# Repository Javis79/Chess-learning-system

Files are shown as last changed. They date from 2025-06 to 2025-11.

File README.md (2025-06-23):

# System Nauki Gry w Szachy

## Opis Projektu

System nauki gry w szachy jest dedykowany dla początkujących szachistów, którzy chcą poprawić swoje umiejętności i poznać zasady gry. Projekt oparty jest na mikrokontrolerze STM32, który zarządza interakcją z użytkownikiem oraz prezentuje ruchy na szachownicy.

Projekt ma na celu pomoc w nauce poprzez wizualne wskazywanie odpowiednich pól szachownicy oraz wyświetlanie notacji ruchów na wyświetlaczu 2.8 cala z interfejsem SPI. System wykorzystuje matrycę LED do podświetlania odpowiednich pól oraz umożliwia łatwe śledzenie postępów w grze.

## Zawartość Projektu

1. **Szachownica LED**: Matryca LED podświetlająca odpowiednie pola na planszy szachowej.
2. **Notacja Ruchów**: Wyświetlanie ruchów w odpowiedniej notacji na wyświetlaczu 2.8 cala z SPI.
3. **Mikrokontroler STM32**: Centralny układ sterujący systemem, odpowiedzialny za obsługę wyświetlacza i matrycy LED.
4. **Potencjalny Rozwój**:

   * **Wykrywanie Poprawności Ruchów**: Każde pole szachownicy będzie traktowane jako przycisk, a system będzie rozpoznawał odkliknięcie klawisza w celu sprawdzenia poprawności ruchu.
   * **Zegar Szachowy**: Wyświetlanie zegara szachowego na wyświetlaczu 2.8 cala, umożliwiającego śledzenie czasu każdej ze stron.

## Wymagania Systemowe

* **Mikrokontroler**: STM32F401RE ARM Cortex M4
* **Matryca LED**: 8x8 
* **Wyświetlacz**: 2.8 cala SPI
* **Zasilanie**: 5V 
* **Oprogramowanie**: STM32CubeIDE

## Wykorzystane Technologie

* **Mikrokontroler STM32**: Platforma sprzętowa do realizacji projektu.
* **SPI**: Interfejs do komunikacji z wyświetlaczem.
* **Matryca LED**: Wyświetlanie pól szachowych i interakcja z użytkownikiem.
* **C**: Język programowania do realizacji logiki sterującej mikrokontrolerem.

## Autor

Praca inżynierska jest tworzona przez Krystiana Bajerskiego, studenta elektroniki na AGH pod przewodnictwem dr inż. Agnieszki Dąbrowskiej-Boruch.

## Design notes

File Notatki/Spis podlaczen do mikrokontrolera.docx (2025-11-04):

# Spis podłączeń do mikrokontrolera

PIN | Podłączony element/IN/OUT elementu
PC0 | 1 rząd mux wyjście
PC1 | 2 rząd mux wyjście
PC2 | 3 rząd mux wyjście
PC3 | 4 rząd mux wyjście
PB7 | 5 rząd mux wyjście
PA13 | 6 rząd mux wyjście
PA14 | 7 rząd mux wyjście
PA15 | 8 rząd mux wyjście
PC10 | Wspólny S0 dla muxów
PC11 | Wspólny S1 dla muxów
PC12 | Wspólny S2 dla muxów
PB0 | Przycisk 1
PA4 | Przycisk 2
PA1 | Przycisk 3
PA0 | Przycisk 4

PINY WYŚWIETLACZA
3V3 | VCC, LED
GND | GND
PA5 | SCK
PA6 | MISO
PA7 | MOSI
PB6 | CS
PC7 | RESET
PA9 | DC
PA8 | Sterowanie matrycą LED
PA10 | CS karty SD

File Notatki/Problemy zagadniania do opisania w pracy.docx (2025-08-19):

# Napotkane problemy/zagadnienia do opisania w pracy

Dobór sposobu podświetlania pól, opisać opcje (dlaczego adresowalna taśma led)

Wybór centralnej jednostki (mikrokontroler, dlaczego stm, a nie esp, zalety wady)

Sposób zapisu posunięć szachowych, ustalenie w jaki sposób program przekształca sobie notacje na odpowiednie pola.

Sposób kontroli ledów, stworzenie programów do kontroli, przygotowanie systemu.

Zapis bazy otwarć szachowych (baza danych? Połączenie zdalne, format txt, json w pliku na karcie sd)

Przedstawienie posunięć na wyświetlaczu, dobór wyświetlacza, przetwarzanie bitmap, organizacja prezentowanych elementów na ekranie, optymalizacja pamięci, by bufor nie zapychał pamięci mikroprocesora.

Stworzenie układu, podłączenie elementów, schematy ideowe, blokowe, wizualizacje 3D szachownicy.

Dobór odpowiedniego zasilacza do wybranej ilości diod led.

Opisanie doboru ustawień mikrokontrolera, odpowiednia częstotliwość zegara, sposób dzialania z dokumentacji, kontrola przy pomocy odpowiednio długich sygnałów.

Podłączenie ledów z mikrokontrolerem, wspólna masa, osobne zasilanie mikrokontrolera i taśmy led. Dobór odpowiedniego przekroju przewodu do zasilania, wytrzymującego przepuszczany prąd.

Lutowanie matrycy led, druk 3d szachownicy.

Technologie zastane, informacje o produktach komercyjnych obecnych na rynku, rozwiązania opisane przy pomocy prac naukowych, potencjalne rozwiązania, którymi można się zainspirować, wady oraz zalety danych rozwiązań, kwestia ceny, zapotrzebowania technologicznego.

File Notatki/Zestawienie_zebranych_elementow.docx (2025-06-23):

# Spis elementów zebranych:

2,8 cala SPI TFT LCD ILI9341 (https://pl.aliexpress.com/item/1005006315533240.html)

WS2812B Taśma LED (https://pl.aliexpress.com/item/1005005824150092.html)

Karta pamięci 32GB (https://pl.aliexpress.com/item/1005006454965988.html)

STM32 NUCLEO-F401RE - STM32F401RE ARM Cortex M4 (https://botland.com.pl/stm32-nucleo/2217-stm32-nucleo-f401re-stm32f401re-arm-cortex-m4-5904422330613.html)

Zestaw rezystorów i kondensatorów

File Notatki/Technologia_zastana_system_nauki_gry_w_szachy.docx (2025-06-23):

Rozdział: Analiza technologii zastanej w projektach elektronicznych szachownic edukacyjnych

W związku z dynamicznym rozwojem technologii informacyjnych oraz rosnącym znaczeniem gier planszowych jako narzędzia edukacyjnego, w ostatnich latach powstało wiele projektów integrujących klasyczne rozgrywki szachowe z nowoczesnymi układami elektronicznymi. W niniejszym rozdziale przedstawiono przegląd wybranych realizacji, wskazując na wykorzystane technologie, cele projektowe oraz potencjalne ograniczenia.

Nasrul Humaïmi Mahmood oraz Che Ku Mohd Salahuddin Che Ku Long w pracy Smart Electronic Chess Board Using Reed Switch [1] przedstawili koncepcję elektronicznej szachownicy wykorzystującej czujniki kontaktronowe (reed switch). W zaproponowanym układzie pod każdą kratką planszy umieszczono czujnik reagujący na magnes w podstawie figury szachowej. W momencie przybliżenia figury do planszy, styk kontaktronu zamykał się, generując sygnał logiczny. Ze względu na dużą liczbę wymaganych wejść zastosowano multipleksery 8:1 typu 74LS251, co ograniczyło ilość linii sygnałowych do mikrokontrolera PIC18F452. Układ komunikował się z komputerem przez konwerter MAX232 i interfejs RS-232, a oprogramowanie w Visual Basic umożliwiało wizualizację rozmieszczenia figur, prowadzenie zapisu partii i obsługę zegara. Choć system nie rozpoznawał typu figur, jego prostota i niskie koszty czyniły go użytecznym narzędziem edukacyjnym oraz turniejowym.

Kolejnym rozwinięciem tej idei był projekt zaprezentowany przez Siti Zarinę Mohd Muji, Mohda Helmy’ego Abdula Wahaba, Radziego Ambara oraz Wong Kiana Loo w publikacji Design and Implementation of Electronic Chess Set [2]. Zamiast czujników magnetycznych zastosowano tu rozwiązanie optyczne — każda figura posiadała nadajnik IR, natomiast pod każdym polem planszy umieszczono fotodiodę. Mikrokontroler Arduino Mega 2560 zarządzał całością systemu, a możliwe ruchy były sygnalizowane poprzez podświetlenie odpowiednich pól diodami LED. Dzięki zastosowaniu enkoderów 64:6, multiplekserów 64:1 oraz rejestrów przesuwających rozwiązano problem ograniczonej liczby wejść/wyjść. System analizował także możliwe ruchy figur, uwzględniając zasady takie jak bicie na skos czy ruchy początkowe pionków. Pomimo ograniczeń w dokładności rozpoznawania typu figur (około 80,95%), rozwiązanie wyróżniało się dużą precyzją w detekcji pozycji i ogromnym potencjałem edukacyjnym.

Równolegle, w obszarze wykorzystania sztucznej inteligencji, badacze ze Sri Lanka Institute of Information Technology: Anuhas Divulage, Ruchika Bandara, Thamara Liyanage, Malith Ishara, Aruna Ishara Gamage i Thusithanjana Thilakarathna opracowali system Chess ADC – An Automated Aide-De-Camp [3]. Projekt ten łączył techniki głębokiego uczenia z tradycyjną grą na fizycznej szachownicy. System wykorzystywał kamery oraz algorytmy oparte na sieciach neuronowych (CNN, ConvLSTM) do wykrywania pozycji figur, kontroli poprawności ruchów i predykcji kolejnych posunięć przeciwnika. Gracze mogli korzystać z podpowiedzi generowanych przez silnik Stockfish, a wszystkie partie były zapisywane w bazie danych w formacie PGN. Analiza zmian prawdopodobieństwa wygranej po każdym ruchu oraz wysokie wyniki trafności predykcji (np. 70,71% dla pionków) czyniły Chess ADC zaawansowanym narzędziem wspierającym rozwój strategicznych umiejętności szachistów.

Studentów Uniwersytetu Centralnej Florydy (UCF) — Aleca Barno, Alejandra Felixa, Cassidy’ego Phillipsa, Viniciusa Resende oraz Nikolaia Colettę — zainteresowała natomiast kwestia intuicyjnego wsparcia nauki dla początkujących graczy. W projekcie Optical Interactive Chess Board for Beginners [4] zaprojektowali szachownicę, w której do identyfikacji figur użyto światłowodów oraz fotodiod. Odbite od podstaw figur światło, modyfikowane przez specjalne filtry, pozwalało określić typ figury stojącej na danym polu. Pod planszą umieszczono diody LED informujące o możliwych ruchach i błędach, a wyświetlacz LCD przekazywał dodatkowe instrukcje. System posiadał rozbudowaną obsługę sytuacji nieregularnych — takich jak nieprawidłowe ruchy, roszada, en passant czy promocja piona — oraz zakładał przyszłą rozbudowę o przeciwnika AI i funkcje dźwiękowe. Projekt wyróżniał się zaawansowaniem technicznym przy zachowaniu prostoty użytkowania.

Odmiennym podejściem do zagadnienia była praca Filipa Sušaca, Ivana Aleksiego oraz Željko Hocenskiego, którzy zaprezentowali rozwiązanie Digital Chess Board based on Array of Hall-Effect Sensors [5]. W ich systemie do wykrywania obecności figur zastosowano 64 czujniki efektu Halla (A3144) rozmieszczone pod polami planszy, a każda figura została wyposażona w magnes trwały. Odczyt danych realizowano poprzez multipleksowanie wierszy i przesyłanie wyników do komputera za pomocą komunikacji UART. Analiza zmian w macierzy stanów planszy umożliwiała wykrywanie ruchów, w tym podnoszenia, przesunięć oraz bić. Oprogramowanie PC oferowało graficzną wizualizację pozycji oraz zapis partii w standardowej notacji. Skuteczność wykrywania ruchów sięgała 96% dla zwykłych przesunięć oraz 86% dla bicia figur. Mimo konieczności ręcznej inicjalizacji pozycji początkowej i ograniczeń w automatycznym rozpoznawaniu typów figur, system stanowił niedrogą i edukacyjną alternatywę dla komercyjnych rozwiązań.

Nowym podejściem do integracji tradycyjnej szachownicy z systemami cyfrowymi zajęli się Guljan Atayeva, Perman Hojaqulyyev, Ayjemal Ussayeva, Yslam Orazov oraz Annageldi Orazov w pracy Cyber Physical System for Physical Chessboard Game on Computer Screen in a Real Time [6]. Autorzy zaprezentowali projekt interaktywnej szachownicy edukacyjnej, która w czasie rzeczywistym odwzorowuje fizyczną grę na ekranie komputera. Kluczowym elementem systemu były czujniki kontaktronowe (reed switch) umieszczone pod każdym polem planszy, reagujące na magnesy zamontowane w podstawach figur. Sygnały z czujników przetwarzane były przez układ Arduino Uno oraz przesyłane do oprogramowania komputerowego napisanego w Pythonie, gdzie z wykorzystaniem biblioteki Tkinter tworzono wizualizację aktualnego stanu gry. System umożliwiał nie tylko śledzenie ruchów na bieżąco, ale także rejestrowanie historii rozgrywki w plikach .xls, co pozwalało na późniejszą analizę partii. Wśród proponowanych ulepszeń autorzy wskazali m.in. możliwość rozwoju sterowania głosowego, integracji z aplikacją mobilną oraz zastosowania identyfikacji figur za pomocą chipów RFID. Projekt stanowił wartościowy krok w kierunku połączenia klasycznej gry planszowej z nowoczesnymi technologiami, oferując atrakcyjne narzędzie dydaktyczne dla graczy w każdym wieku.

Jednym z najbardziej rozpoznawalnych produktów jest DGT e-Board, wykorzystywana w oficjalnych turniejach szachowych FIDE [7]. Plansza ta wykorzystuje technologię pasywnych obwodów LC umieszczonych w podstawie każdej figury oraz aktywnych cewek w polach planszy. Dzięki pomiarowi częstotliwości rezonansowej system jest w stanie nie tylko wykrywać obecność figur, ale również rozpoznawać ich typ. DGT e-Board umożliwia bezpośrednie przesyłanie aktualnego układu planszy do komputerów i transmisję partii online. Rozwiązanie to cechuje się wysoką precyzją i niezawodnością, choć jego koszt oraz potrzeba integracji ze specjalistycznym oprogramowaniem mogą być barierą dla użytkowników domowych.

Innym ciekawym rozwiązaniem jest Square Off, które wprowadziło innowacyjną funkcję automatycznego przesuwania figur [8]. System wykorzystuje ukryty mechanizm XY, który przesuwa figury za pomocą wbudowanych magnesów, tworząc wrażenie „samodzielnie grającej” szachownicy. Użytkownicy mogą rywalizować zarówno z wirtualnymi przeciwnikami AI, jak i z graczami online. Choć rozwiązanie to imponuje efektem wizualnym, jest ono mniej skoncentrowane na edukacyjnych aspektach nauki zasad gry.

W segmencie bardziej przystępnym cenowo wyróżnia się Chessnut Air [9], który łączy fizyczną szachownicę z cyfrowym interfejsem. System oparty na matrycy czujników wykrywa obecność figur na planszy i synchronizuje je z aplikacjami szachowymi (takimi jak Chess.com czy Lichess). Chessnut Air umożliwia grę z AI oraz rozgrywki online, oferując intuicyjny sposób nauki i analizy rozgrywek. Urządzenie wymaga połączenia zewnętrznego (telefonu, tabletu lub komputera), co zwiększa jego elastyczność.

[1] N. H. Mahmood and C. K. M. S. C. K. Long, "Smart Electronic Chess Board Using Reed Switch," Jurnal Teknologi, vol. 55, no. Sains & Kej., May 2011.

[2] S. Z. M. Muji, M. H. A. Wahab, R. Ambar, and W. K. Loo, "Design and Implementation of Electronic Chess Set," in Proc. 2016 Int. Conf. Advances in Electrical, Electronic and System Engineering (ICAEES), Putrajaya, Malaysia, 2016.

[3] A. Divulage, R. Bandara, T. Liyanage, M. Ishara, A. I. Gamage, and T. Thilakarathna, "Chess ADC – An Automated Aide-De-Camp," in Proc. 20th Int. Conf. Advances in ICT for Emerging Regions (ICTer), Colombo, Sri Lanka, 2020.

[4] A. Barno, A. Felix, C. Phillips, V. Resende, and N. Coletta, "Optical Interactive Chess Board for Beginners," Senior Design Project, University of Central Florida, 2023.

[5] F. Sušac, I. Aleksi, and Ž. Hocenski, "Digital Chess Board based on Array of Hall-Effect Sensors," in Proc. 2017 Int. Conv. Information and Communication Technology, Electronics and Microelectronics (MIPRO), Opatija, Croatia, 2017.

[6] G. Atayeva, P. Hojaqulyyev, A. Ussayeva, Y. Orazov and A. Orazov, "Cyber Physical System for Physical Chessboard Game on Computer Screen in a Real Time," in Proc. 2024 3rd International Conference on Computational Modelling, Simulation and Optimization (ICCMSO), Ashgabat, Turkmenistan, 2024.

[7] Digital Game Technology (DGT), „DGT Electronic Chess Board – przegląd produktu”, [Online]. https://www.digitalgametechnology.com. [Dostęp: 28-kwi-2025].

[8] Square Off, „Square Off – pierwsza na świecie automatyczna szachownica”, [Online]. https://squareoffnow.com. [Dostęp: 28-kwi-2025].

[9] Chessnut, „Chessnut Air – inteligentna elektroniczna szachownica”, [Online]. https://chessnutech.com. [Dostęp: 28-kwi-2025].

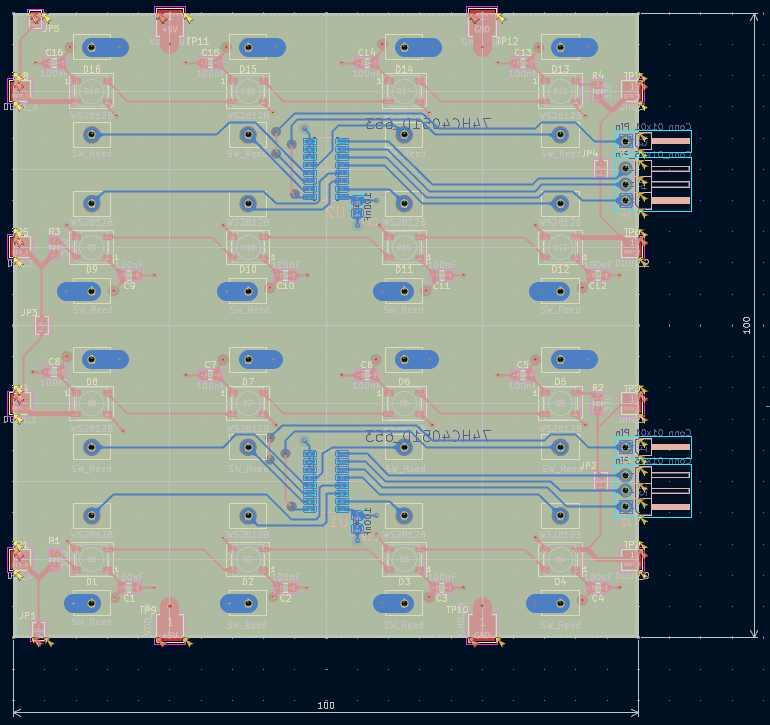
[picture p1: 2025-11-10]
PCB_inzynierka/screens/Screenshot from 2025-11-08 16-29-04.png

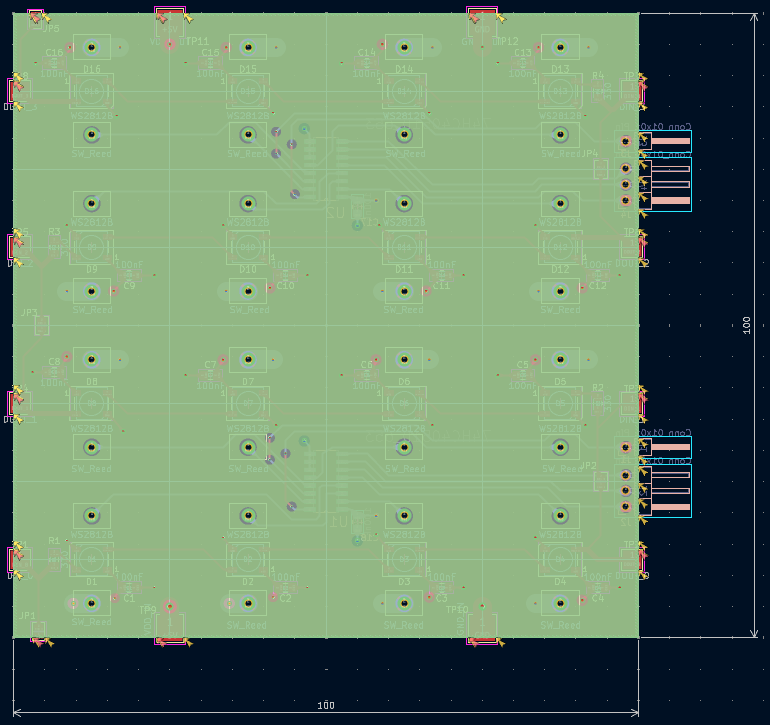
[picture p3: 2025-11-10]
PCB_inzynierka/screens/Screenshot from 2025-11-08 16-28-57.png

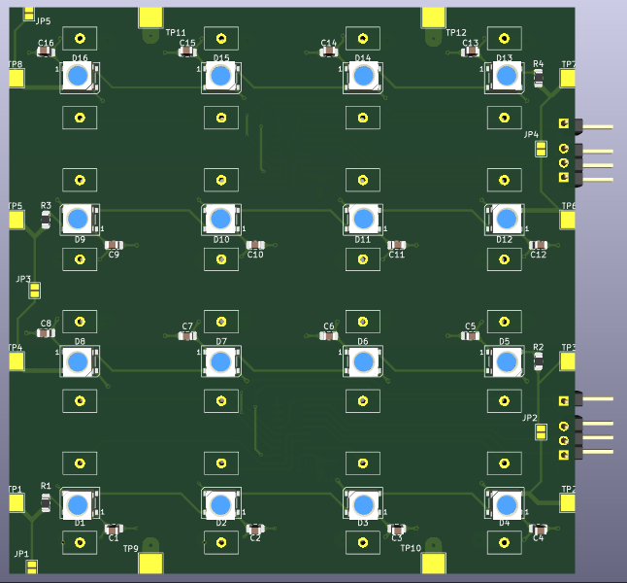
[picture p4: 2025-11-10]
PCB_inzynierka/screens/Screenshot from 2025-11-08 16-29-26.png

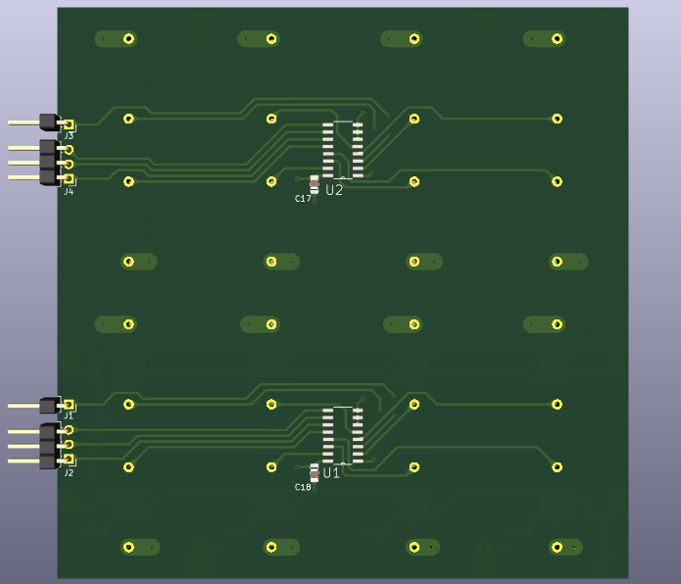
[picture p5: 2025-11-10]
PCB_inzynierka/screens/Screenshot from 2025-11-08 16-29-47.png

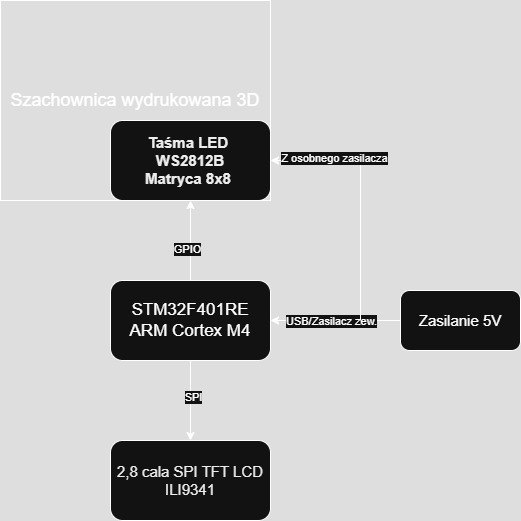
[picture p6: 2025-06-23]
Grafiki/Schemat_blokowy.jpg

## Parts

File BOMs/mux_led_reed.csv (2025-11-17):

Id | Designator | Footprint | Quantity | Designation | Supplier and ref
1 | D11,D1,D10,D12,D16,D8,D3,D6,D2,D15,D7,D13,D9,D14,D4,D5 | LED_WS2812B_PLCC4_5.0x5.0mm_P3.2mm | 16 | WS2812B
2 | SW9,SW15,SW3,SW1,SW14,SW5,SW10,SW2,SW16,SW13,SW7,SW4,SW6,SW11,SW8,SW12 | ReedSwitch_2x14mm | 16 | SW_Reed
3 | C13,C16,C7,C14,C8,C2,C11,C1,C10,C4,C5,C12,C3,C6,C9,C15,C18,C17 | C_0805_2012Metric_Pad1.18x1.45mm_HandSolder | 18 | 100nF
4 | J6,J10,J5,J9 | PinHeader_1x04_P2.54mm_Horizontal | 4 | Conn_01x04_Pin
5 | TP1 | TestPoint_Pad_3.0x3.0mm | 1 | DIN_0
6 | J8,J11,J7,J12 | PinSocket_1x04_P2.54mm_Horizontal | 4 | Conn_01x04_Pin
7 | TP9 | TestPoint_Pad_4.0x4.0mm | 1 | VDD_IN
8 | TP11 | TestPoint_Pad_4.0x4.0mm | 1 | VDD_OUT
9 | R4,R2,R1,R3 | R_0805_2012Metric_Pad1.20x1.40mm_HandSolder | 4 | 330
10 | TP6 | TestPoint_Pad_3.0x3.0mm | 1 | DOUT_2
11 | TP7 | TestPoint_Pad_3.0x3.0mm | 1 | DIN_3
12 | TP10 | TestPoint_Pad_4.0x4.0mm | 1 | GND_IN
13 | TP5 | TestPoint_Pad_3.0x3.0mm | 1 | DIN_2
14 | TP2 | TestPoint_Pad_3.0x3.0mm | 1 | DOUT_0
15 | TP12 | TestPoint_Pad_4.0x4.0mm | 1 | GND_OUT
16 | TP3 | TestPoint_Pad_3.0x3.0mm | 1 | DIN_1
17 | TP8 | TestPoint_Pad_3.0x3.0mm | 1 | DOUT_3
18 | TP4 | TestPoint_Pad_3.0x3.0mm | 1 | DOUT_1
19 | J1,J3 | PinHeader_1x01_P2.54mm_Vertical | 2 | Conn_01x01_Pin
20 | U1,U2 | SOIC127P600X175-16N | 2 | 74HC4051D_653
21 | J2,J4 | PinHeader_1x03_P2.54mm_Vertical | 2 | Conn_01x03_Pin

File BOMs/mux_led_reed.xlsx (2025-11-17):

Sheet: mux_led_reed
Id | Designator | Footprint | Quantity | Designation | Supplier and ref
1 | D11,D1,D10,D12,D16,D8,D3,D6,D2,D15,D7,D13,D9,D14,D4,D5 | LED_WS2812B_PLCC4_5.0x5.0mm_P3.2mm | 16 | WS2812B | ws2812B (https://pl.aliexpress.com/item/4001345875756.html?mp=1)
2 | SW9,SW15,SW3,SW1,SW14,SW5,SW10,SW2,SW16,SW13,SW7,SW4,SW6,SW11,SW8,SW12 | ReedSwitch_2x14mm | 16 | SW_Reed | reed_switch (https://pl.aliexpress.com/item/1005008194740665.html?mp=1)
3 | C13,C16,C7,C14,C8,C2,C11,C1,C10,C4,C5,C12,C3,C6,C9,C15,C18,C17 | C_0805_2012Metric_Pad1.18x1.45mm_HandSolder | 18 | 100nF
4 | J6,J10,J5,J9 | PinHeader_1x04_P2.54mm_Horizontal | 4 | Conn_01x04_Pin
5 | TP1 | TestPoint_Pad_3.0x3.0mm | 1 | DIN_0
6 | J8,J11,J7,J12 | PinSocket_1x04_P2.54mm_Horizontal | 4 | Conn_01x04_Pin
7 | TP9 | TestPoint_Pad_4.0x4.0mm | 1 | VDD_IN
8 | TP11 | TestPoint_Pad_4.0x4.0mm | 1 | VDD_OUT
9 | R4,R2,R1,R3 | R_0805_2012Metric_Pad1.20x1.40mm_HandSolder | 4 | 330
10 | TP6 | TestPoint_Pad_3.0x3.0mm | 1 | DOUT_2
11 | TP7 | TestPoint_Pad_3.0x3.0mm | 1 | DIN_3
12 | TP10 | TestPoint_Pad_4.0x4.0mm | 1 | GND_IN
13 | TP5 | TestPoint_Pad_3.0x3.0mm | 1 | DIN_2
14 | TP2 | TestPoint_Pad_3.0x3.0mm | 1 | DOUT_0
15 | TP12 | TestPoint_Pad_4.0x4.0mm | 1 | GND_OUT
16 | TP3 | TestPoint_Pad_3.0x3.0mm | 1 | DIN_1
17 | TP8 | TestPoint_Pad_3.0x3.0mm | 1 | DOUT_3
18 | TP4 | TestPoint_Pad_3.0x3.0mm | 1 | DOUT_1
19 | J1,J3 | PinHeader_1x01_P2.54mm_Vertical | 2 | Conn_01x01_Pin
20 | U1,U2 | SOIC127P600X175-16N | 2 | 74HC4051D_653
21 | J2,J4 | PinHeader_1x03_P2.54mm_Vertical | 2 | Conn_01x03_Pin

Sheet: uC_screen_power
Id | Designator | Footprint | Quantity | Designation | Supplier and ref
1 | C67 | CP_Radial_D4.0mm_P2.00mm | 1 | 100nF
2 | U10 | TFT-320x240 | 1 | TFT_320x240
3 | C78,C79,C76,C77 | C_0805_2012Metric_Pad1.18x1.45mm_HandSolder | 4 | 100nF
4 | SW76,SW74,SW75,SW73 | SW_TS02-66-60-BK-100-LCR-D | 4 | SW_DPST
5 | J4,J5 | PinHeader_1x04_P2.54mm_Horizontal | 2 | Conn_01x04_Pin
6 | C66 | CP_Radial_D4.0mm_P2.00mm | 1 | 22uF
7 | J1 | BarrelJack_Horizontal | 1 | Barrel_Jack_Switch
8 | J7 | PinHeader_1x01_P2.54mm_Vertical | 1 | Conn_01x01_Pin
9 | U11 | ST_NUCLEO-F401RE | 1 | NUCLEO-F401RE
10 | J2,J3 | PinHeader_1x04_P2.54mm_Vertical | 2 | Conn_01x04_Pin
11 | J6 | PinHeader_1x03_P2.54mm_Vertical | 1 | Conn_01x03_Pin

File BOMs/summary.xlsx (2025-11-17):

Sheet: Summary
Id | Footprint | Quantity | Link
1 | LED_WS2812B_PLCC4_5.0x5.0mm_P3.2mm | 64 | ws2812B (https://pl.aliexpress.com/item/4001345875756.html?mp=1)
2 | ReedSwitch_2x14mm | 64 | reed_switch (https://pl.aliexpress.com/item/1005008194740665.html?mp=1)
3 | C_0805_2012Metric_Pad1.18x1.45mm_HandSolder | 76 | cap_100nF_smd (https://www.tme.eu/pl/details/0805b104k500ct/kondensatory-mlcc-smd/walsin/)
4 | PinHeader_1x04_P2.54mm_Horizontal | 18 | pin_header_1x4hor (https://www.tme.eu/pl/details/826631-4/listwy-i-gniazda-kolkowe/te-connectivity/)
5 | PinSocket_1x04_P2.54mm_Horizontal | 16 | pin_socket_1x4hor (https://www.tme.eu/pl/details/zl263-4sg/listwy-i-gniazda-kolkowe/connfly/ds1024-1-4r2/)
6 | PinHeader_1x01_P2.54mm_Vertical | 10 | pin_header_1x1ver (https://www.tme.eu/pl/details/825433-1/listwy-i-gniazda-kolkowe/te-connectivity/)
7 | PinHeader_1x03_P2.54mm_Vertical | 10 | pin_header_1x3ver (https://www.tme.eu/pl/details/zl201-03g/listwy-i-gniazda-kolkowe/connfly/ds1021-1-3sf11-b/)
8 | SOIC127P600X175-16N | 8 | mux (https://www.tme.eu/pl/details/74hc4051dbj/dekodery-multipleksery-przelaczniki/toshiba/74hc4051d-bj/)
9 | CP_Radial_D4.0mm_P2.00mm (22uF) | 1
10 | TFT-320x240 | 1 | tft_screen (https://pl.aliexpress.com/item/1005006315533240.html)
11 | SW_TS02-66-60-BK-100-LCR-D | 4
12 | CP_Radial_D4.0mm_P2.00mm (100nF) | 1
13 | BarrelJack_Horizontal | 1 | barrel_jack (https://www.tme.eu/pl/details/1613-21/zlacza-dc/lumberg/1613-21/)
14 | ST_NUCLEO-F401RE | 1 | stm_nucleo (https://botland.com.pl/stm32-nucleo/2217-stm32-nucleo-f401re-stm32f401re-arm-cortex-m4-5904422330613.html)
15 | R_0805_2012Metric_Pad1.20x1.40mm_HandSolder (330Ω) | 16 | rezystor (https://www.tme.eu/pl/details/crgcq0805f330r/rezystory-smd/te-connectivity/1-2176341-9/)

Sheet: mux_led_reed
Id | Designator | Footprint | Quantity | Designation | Link
1 | D11,D1,D10,D12,D16,D8,D3,D6,D2,D15,D7,D13,D9,D14,D4,D5 | LED_WS2812B_PLCC4_5.0x5.0mm_P3.2mm | 16 | WS2812B | ws2812B (https://pl.aliexpress.com/item/4001345875756.html?mp=1)
2 | SW9,SW15,SW3,SW1,SW14,SW5,SW10,SW2,SW16,SW13,SW7,SW4,SW6,SW11,SW8,SW12 | ReedSwitch_2x14mm | 16 | SW_Reed | reed_switch (https://pl.aliexpress.com/item/1005008194740665.html?mp=1)
3 | C13,C16,C7,C14,C8,C2,C11,C1,C10,C4,C5,C12,C3,C6,C9,C15,C18,C17 | C_0805_2012Metric_Pad1.18x1.45mm_HandSolder | 18 | 100nF
4 | J6,J10,J5,J9 | PinHeader_1x04_P2.54mm_Horizontal | 4 | Conn_01x04_Pin
5 | TP1 | TestPoint_Pad_3.0x3.0mm | 1 | DIN_0
6 | J8,J11,J7,J12 | PinSocket_1x04_P2.54mm_Horizontal | 4 | Conn_01x04_Pin
7 | TP9 | TestPoint_Pad_4.0x4.0mm | 1 | VDD_IN
8 | TP11 | TestPoint_Pad_4.0x4.0mm | 1 | VDD_OUT
9 | R4,R2,R1,R3 | R_0805_2012Metric_Pad1.20x1.40mm_HandSolder | 4 | 330
10 | TP6 | TestPoint_Pad_3.0x3.0mm | 1 | DOUT_2
11 | TP7 | TestPoint_Pad_3.0x3.0mm | 1 | DIN_3
12 | TP10 | TestPoint_Pad_4.0x4.0mm | 1 | GND_IN
13 | TP5 | TestPoint_Pad_3.0x3.0mm | 1 | DIN_2
14 | TP2 | TestPoint_Pad_3.0x3.0mm | 1 | DOUT_0
15 | TP12 | TestPoint_Pad_4.0x4.0mm | 1 | GND_OUT
16 | TP3 | TestPoint_Pad_3.0x3.0mm | 1 | DIN_1
17 | TP8 | TestPoint_Pad_3.0x3.0mm | 1 | DOUT_3
18 | TP4 | TestPoint_Pad_3.0x3.0mm | 1 | DOUT_1
19 | J1,J3 | PinHeader_1x01_P2.54mm_Vertical | 2 | Conn_01x01_Pin
20 | U1,U2 | SOIC127P600X175-16N | 2 | 74HC4051D_653
21 | J2,J4 | PinHeader_1x03_P2.54mm_Vertical | 2 | Conn_01x03_Pin

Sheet: uC_screen_power
Id | Designator | Footprint | Quantity | Designation | Link
1 | C67 | CP_Radial_D4.0mm_P2.00mm | 1 | 100nF
2 | U10 | TFT-320x240 | 1 | TFT_320x240
3 | C78,C79,C76,C77 | C_0805_2012Metric_Pad1.18x1.45mm_HandSolder | 4 | 100nF
4 | SW76,SW74,SW75,SW73 | SW_TS02-66-60-BK-100-LCR-D | 4 | SW_DPST
5 | J4,J5 | PinHeader_1x04_P2.54mm_Horizontal | 2 | Conn_01x04_Pin
6 | C66 | CP_Radial_D4.0mm_P2.00mm | 1 | 22uF
7 | J1 | BarrelJack_Horizontal | 1 | Barrel_Jack_Switch
8 | J7 | PinHeader_1x01_P2.54mm_Vertical | 1 | Conn_01x01_Pin
9 | U11 | ST_NUCLEO-F401RE | 1 | NUCLEO-F401RE
10 | J2,J3 | PinHeader_1x04_P2.54mm_Vertical | 2 | Conn_01x04_Pin
11 | J6 | PinHeader_1x03_P2.54mm_Vertical | 1 | Conn_01x03_Pin

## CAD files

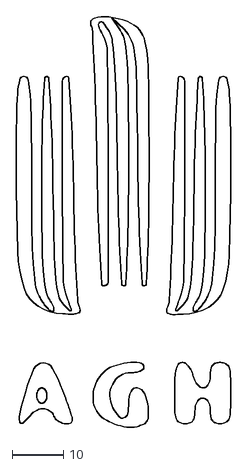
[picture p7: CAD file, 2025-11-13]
Grafiki/logo_agh-removebg-preview.dxf
42.0 x 80.5

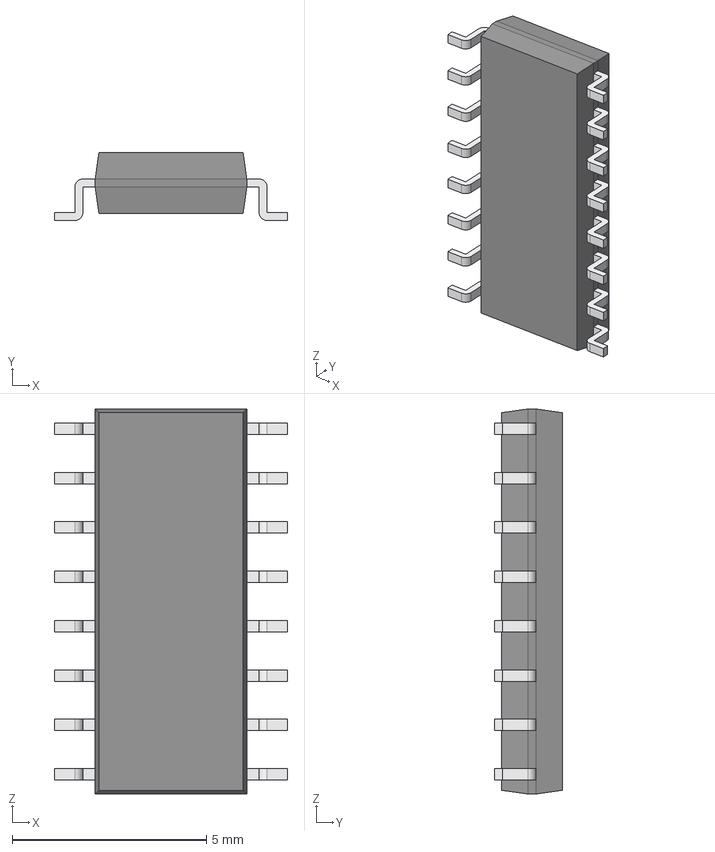
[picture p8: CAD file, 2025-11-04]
PCB_inzynierka/footprints/74HC4051D_653/74HC4051D_653.step
6.00 x 1.75 x 9.90 mm
Body001 (Mirror #1) x 8
XY-plane x 12
X-axis x 12

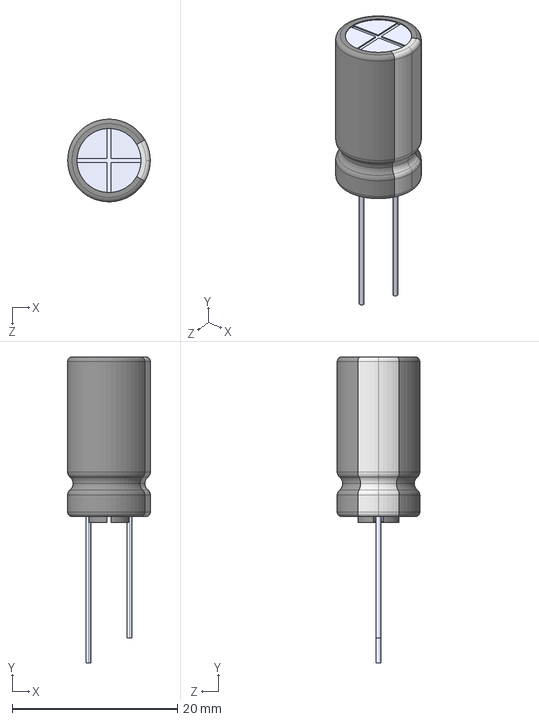
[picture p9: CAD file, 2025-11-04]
PCB_inzynierka/footprints/EEUFR1C152/EEUFR1C152.step
10.0 x 37.0 x 9.99 mm

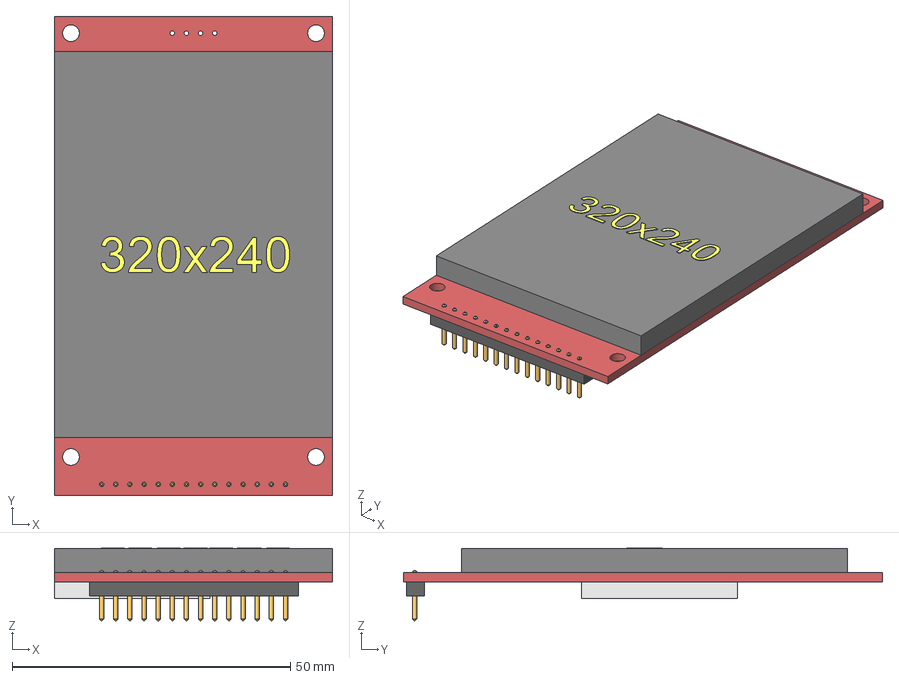
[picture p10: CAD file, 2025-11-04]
PCB_inzynierka/footprints/TFT_screen/TFT_320x240_touch_r0.step
50.0 x 86.0 x 13.1 mm
Body-header
Body-pins
Body-display
Body-sdcard
Body-board

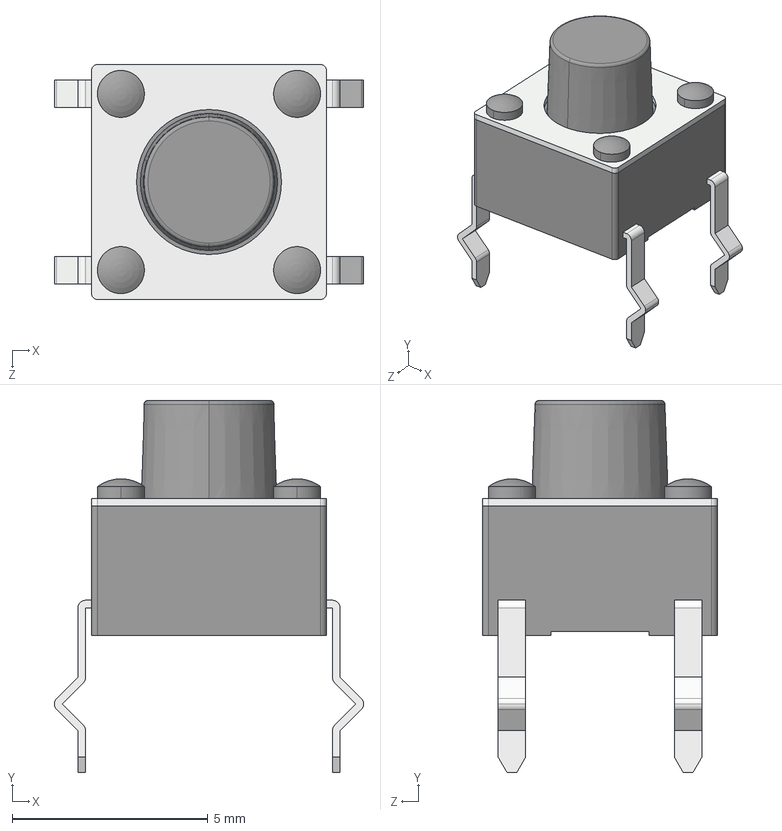
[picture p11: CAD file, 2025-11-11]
PCB_inzynierka/footprints/TS02-66-60-BK-100-LCR-D/TS02-66-60-BK-100-LCR-D.step
7.90 x 9.50 x 6.00 mm

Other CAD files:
Model_3D/podstawa szachownicy od strony uC.f3d
Model_3D/podstawa szachownicy.f3d
Model_3D/uC podstawa.f3d
Model_3D/zlozenie szachownicy.f3z

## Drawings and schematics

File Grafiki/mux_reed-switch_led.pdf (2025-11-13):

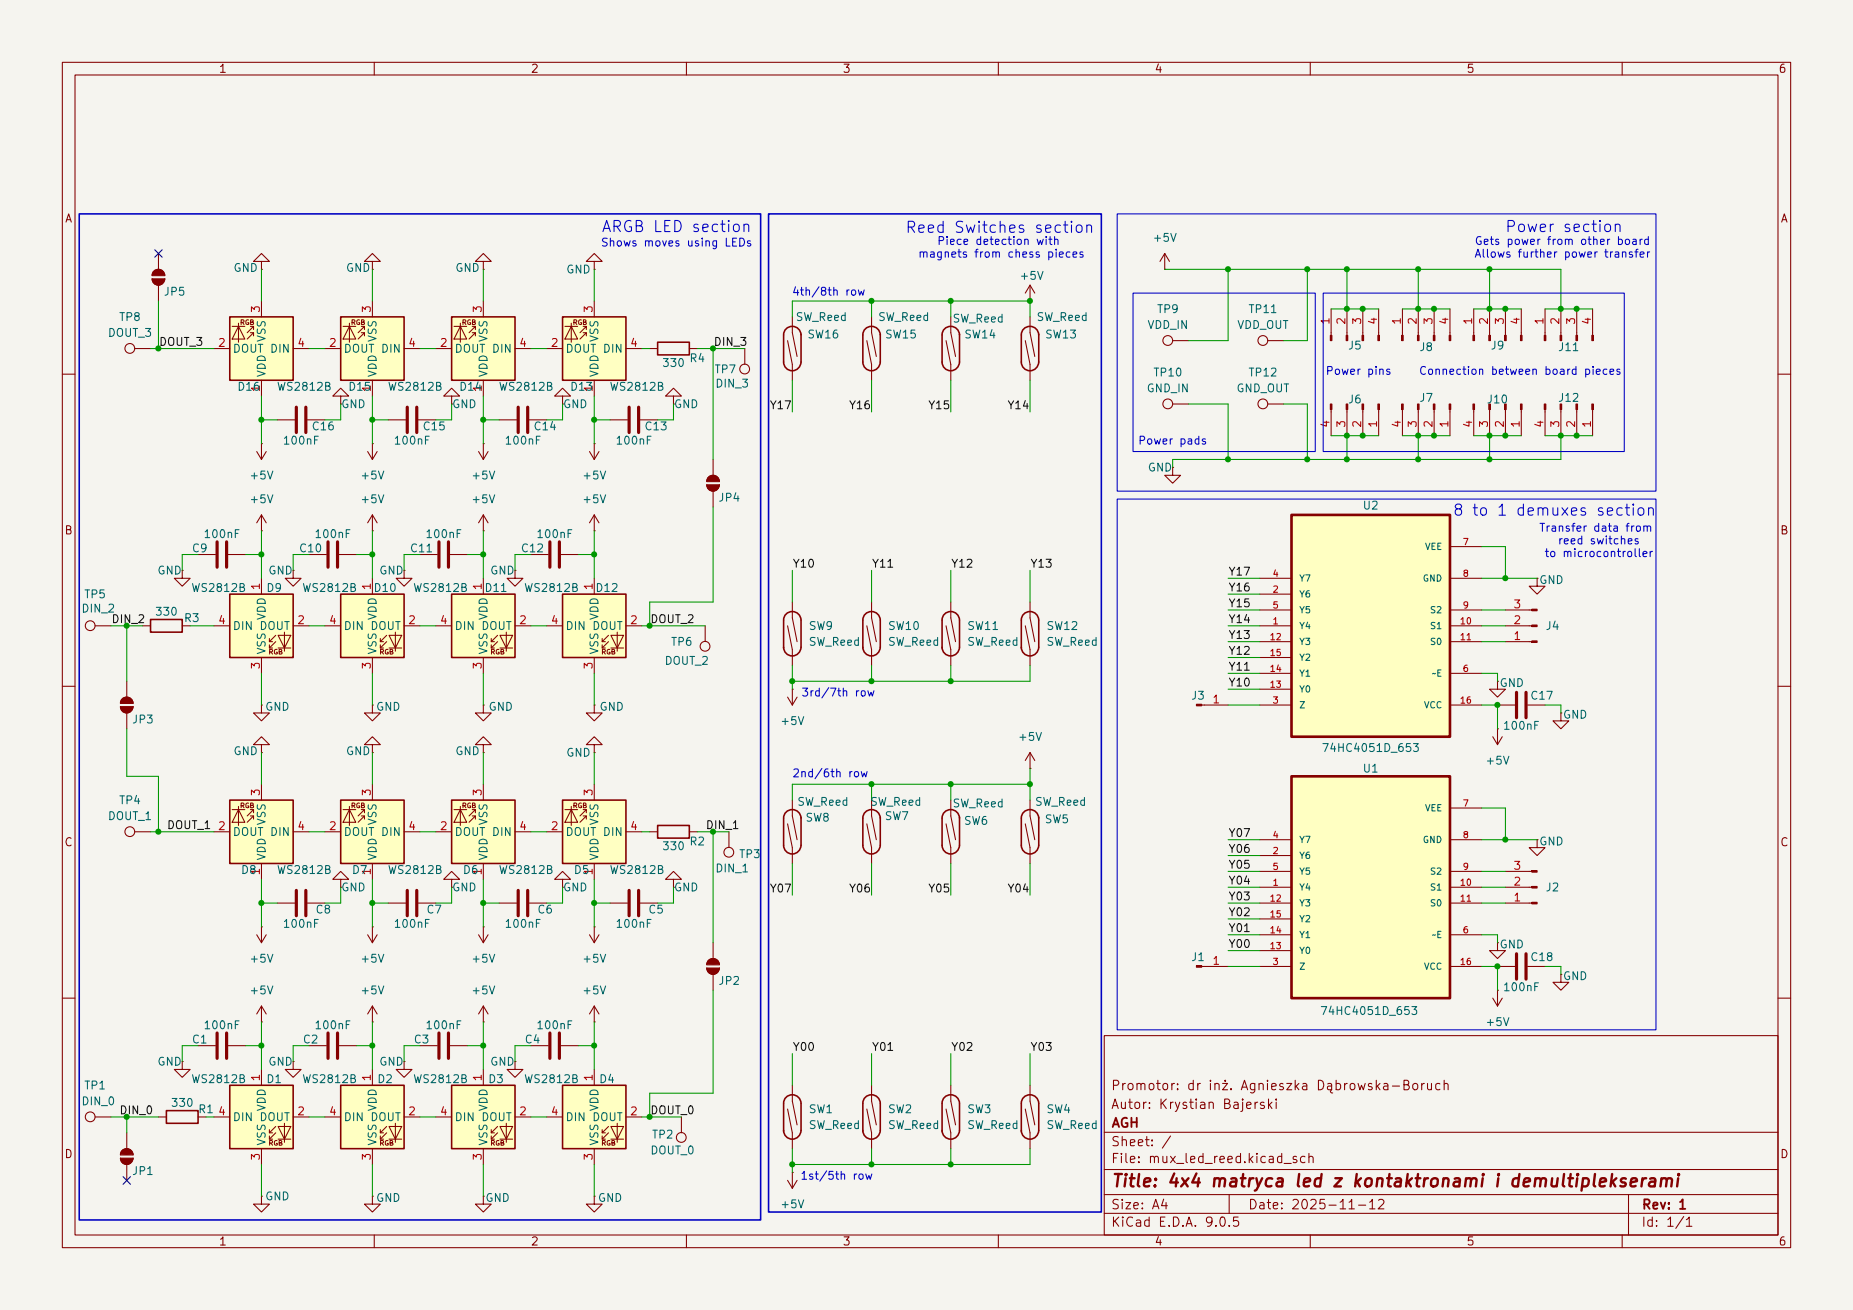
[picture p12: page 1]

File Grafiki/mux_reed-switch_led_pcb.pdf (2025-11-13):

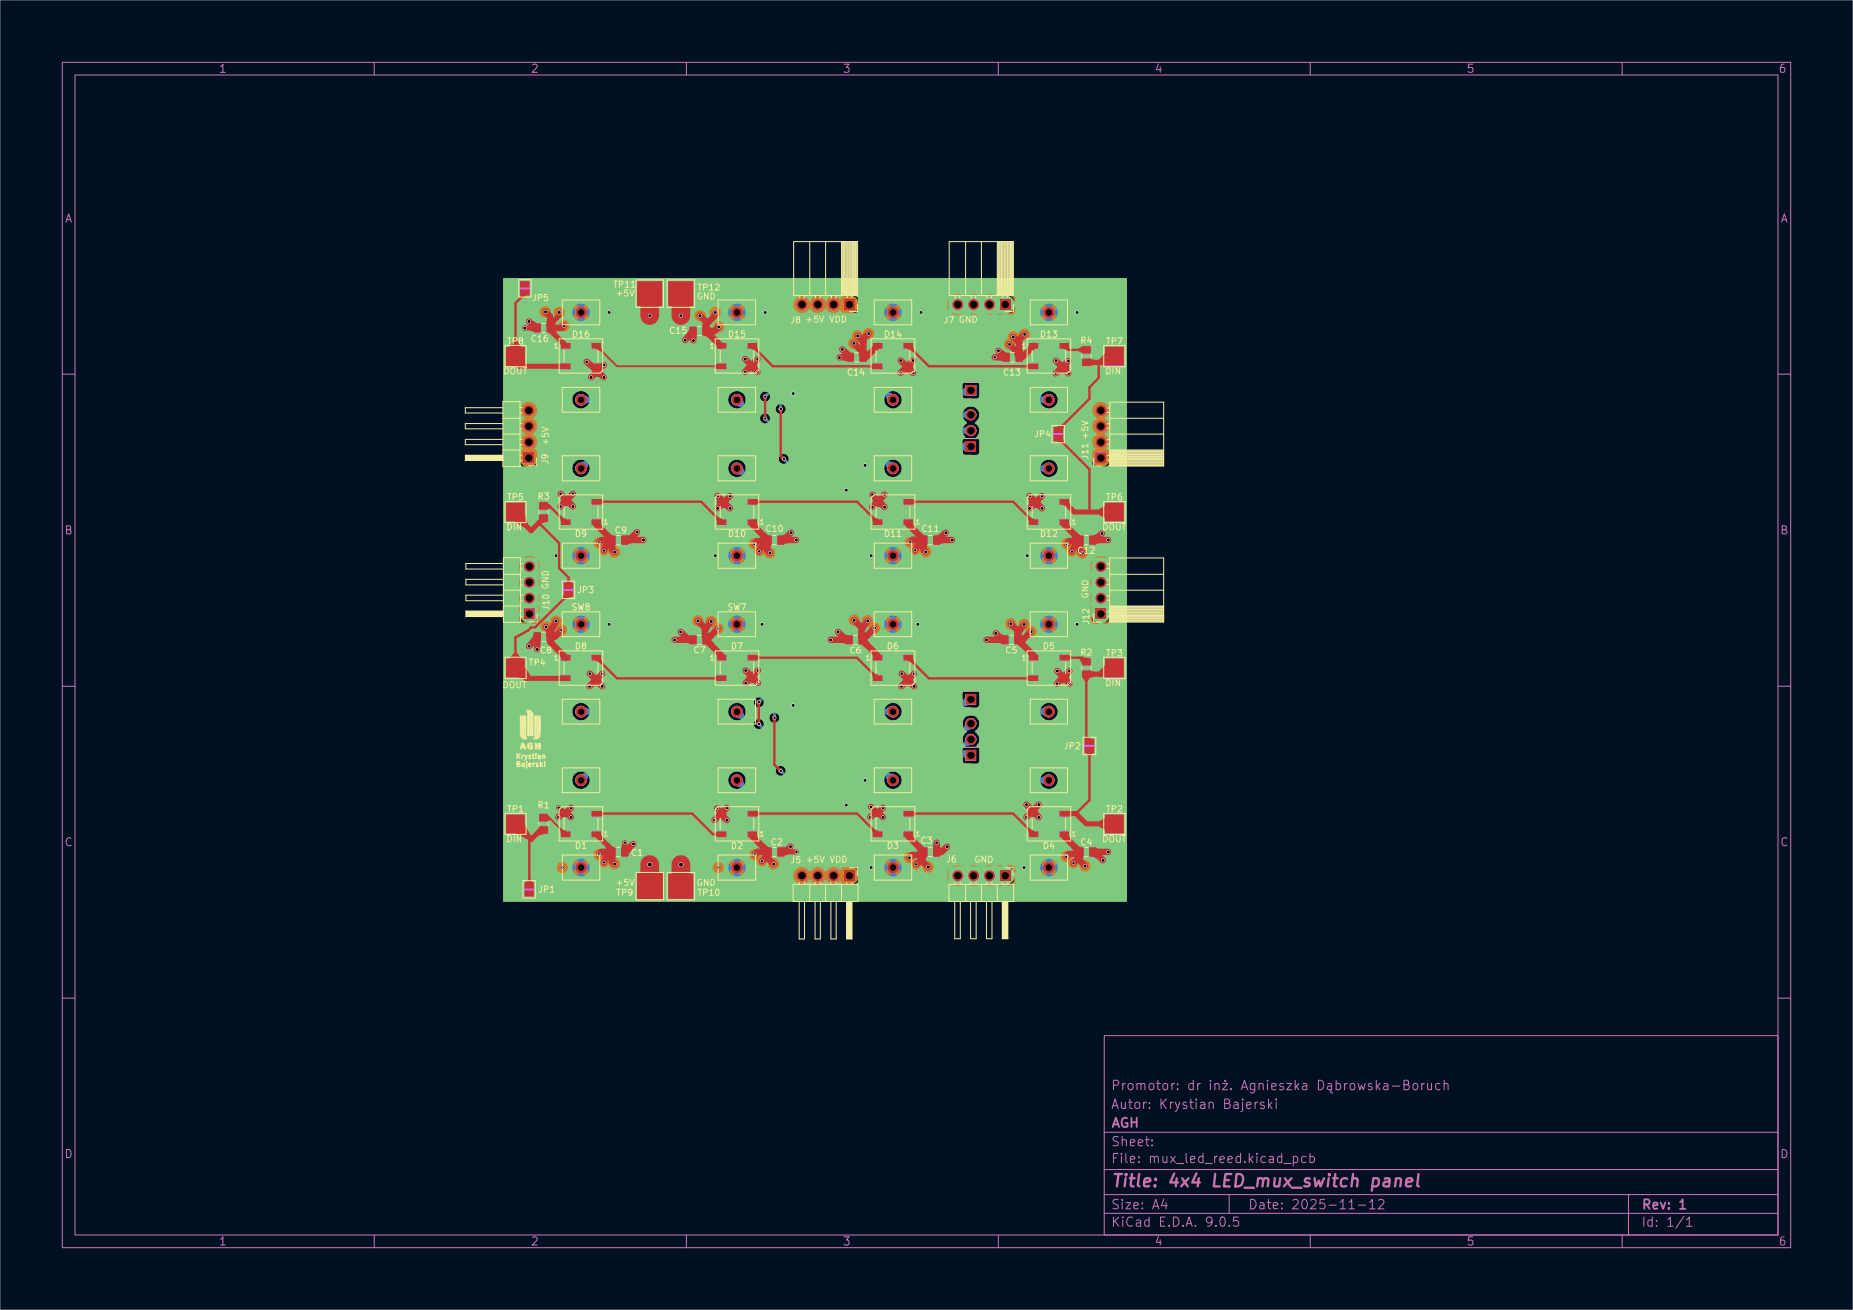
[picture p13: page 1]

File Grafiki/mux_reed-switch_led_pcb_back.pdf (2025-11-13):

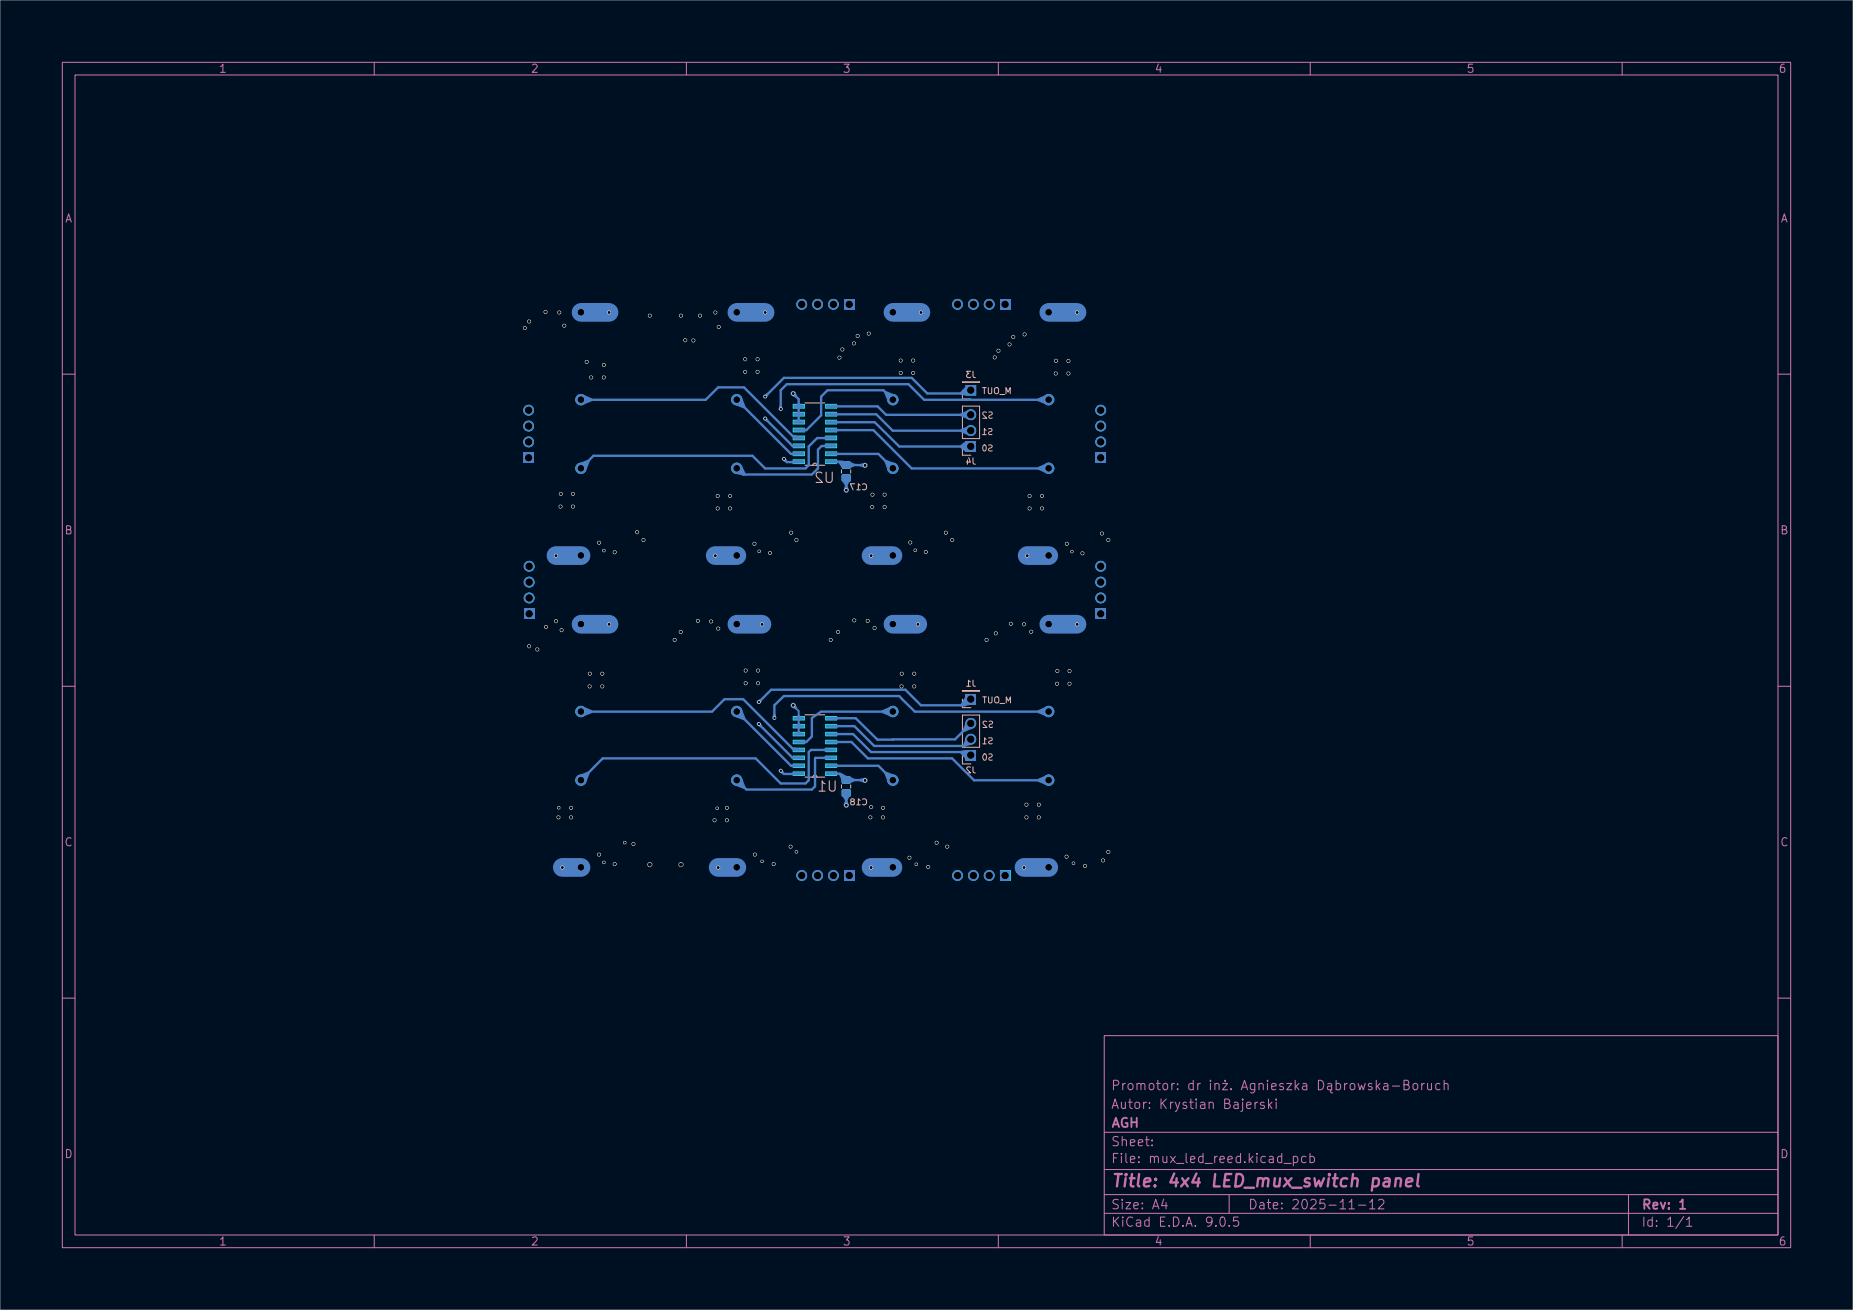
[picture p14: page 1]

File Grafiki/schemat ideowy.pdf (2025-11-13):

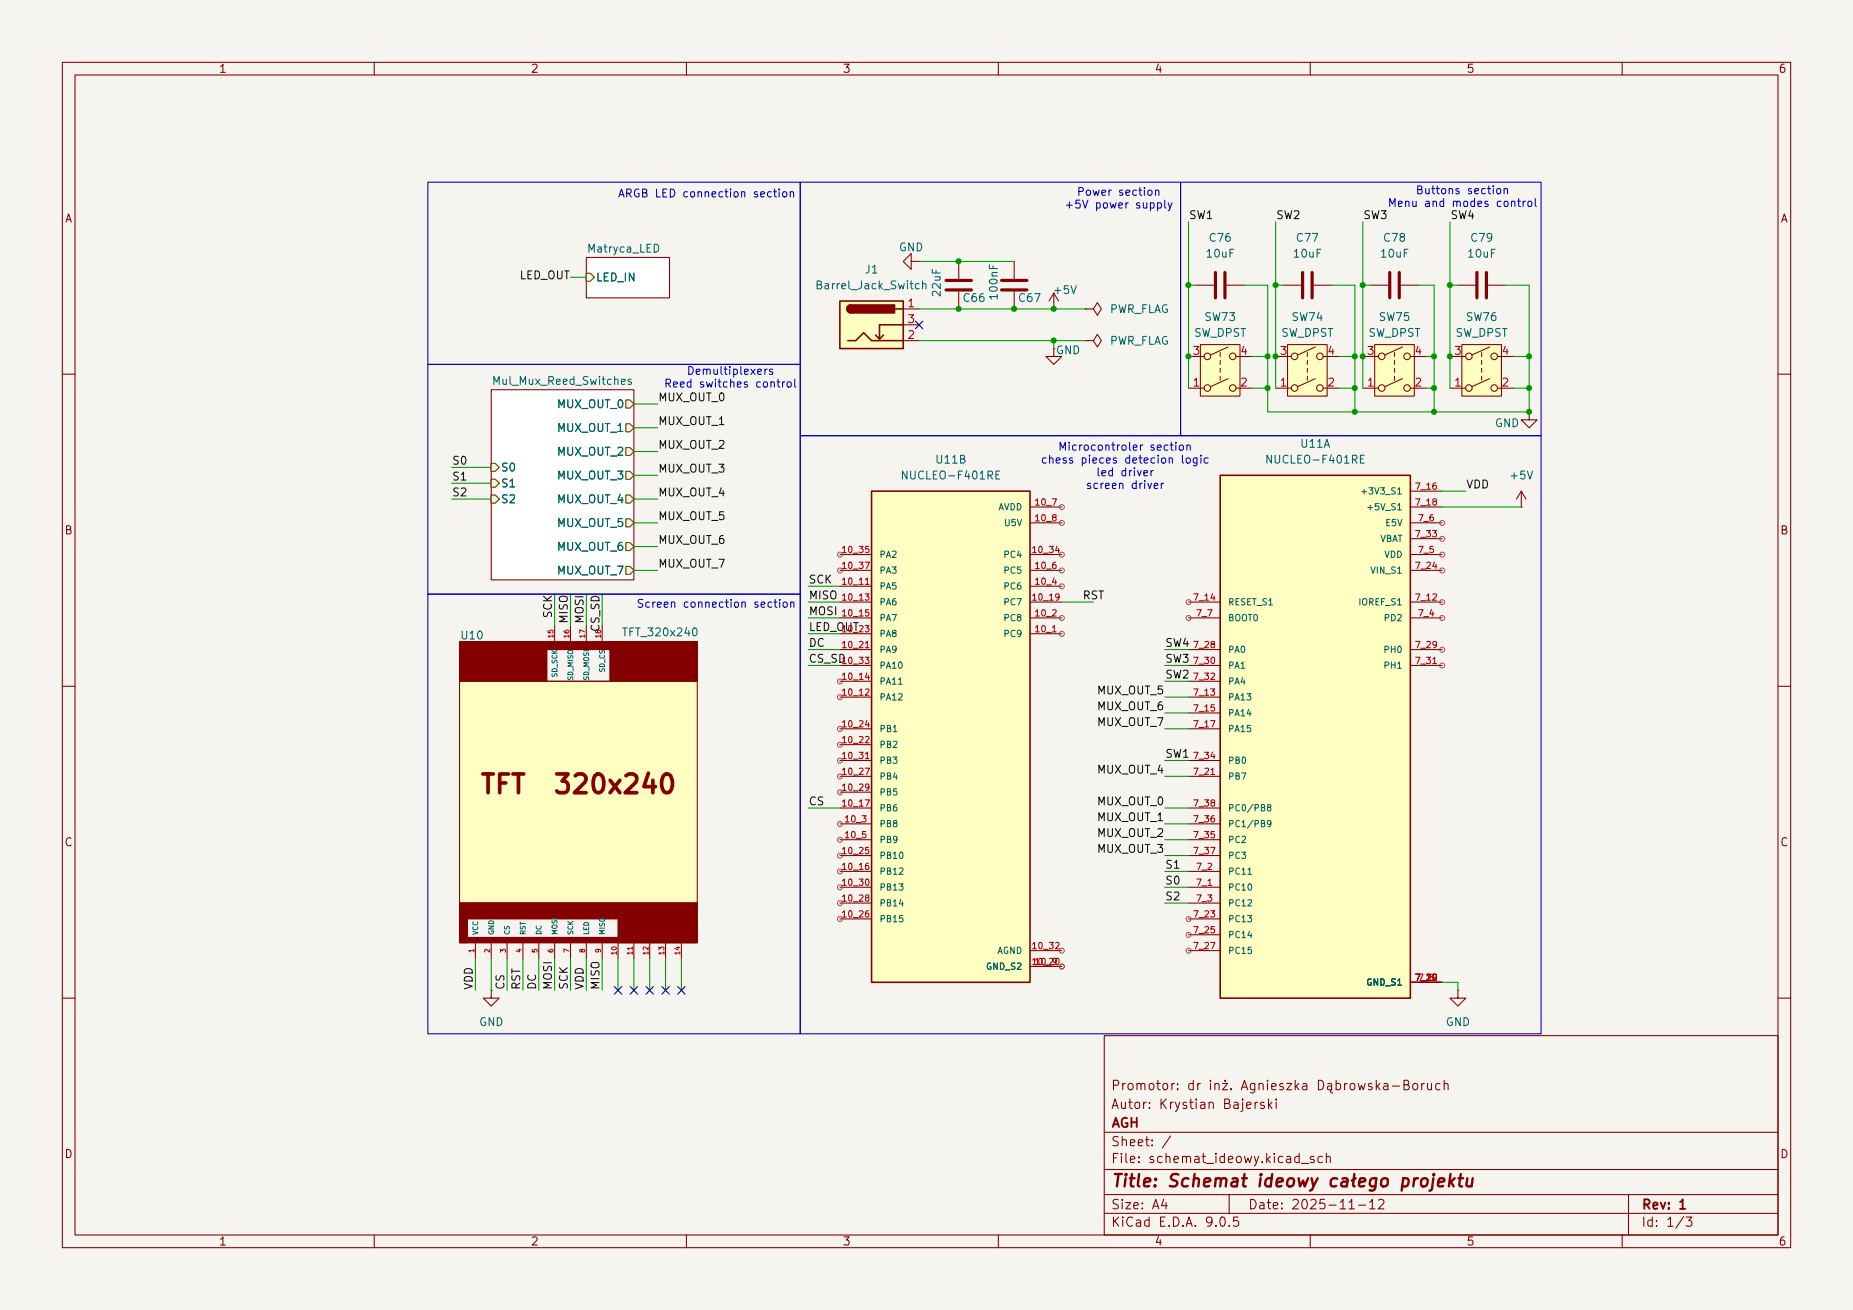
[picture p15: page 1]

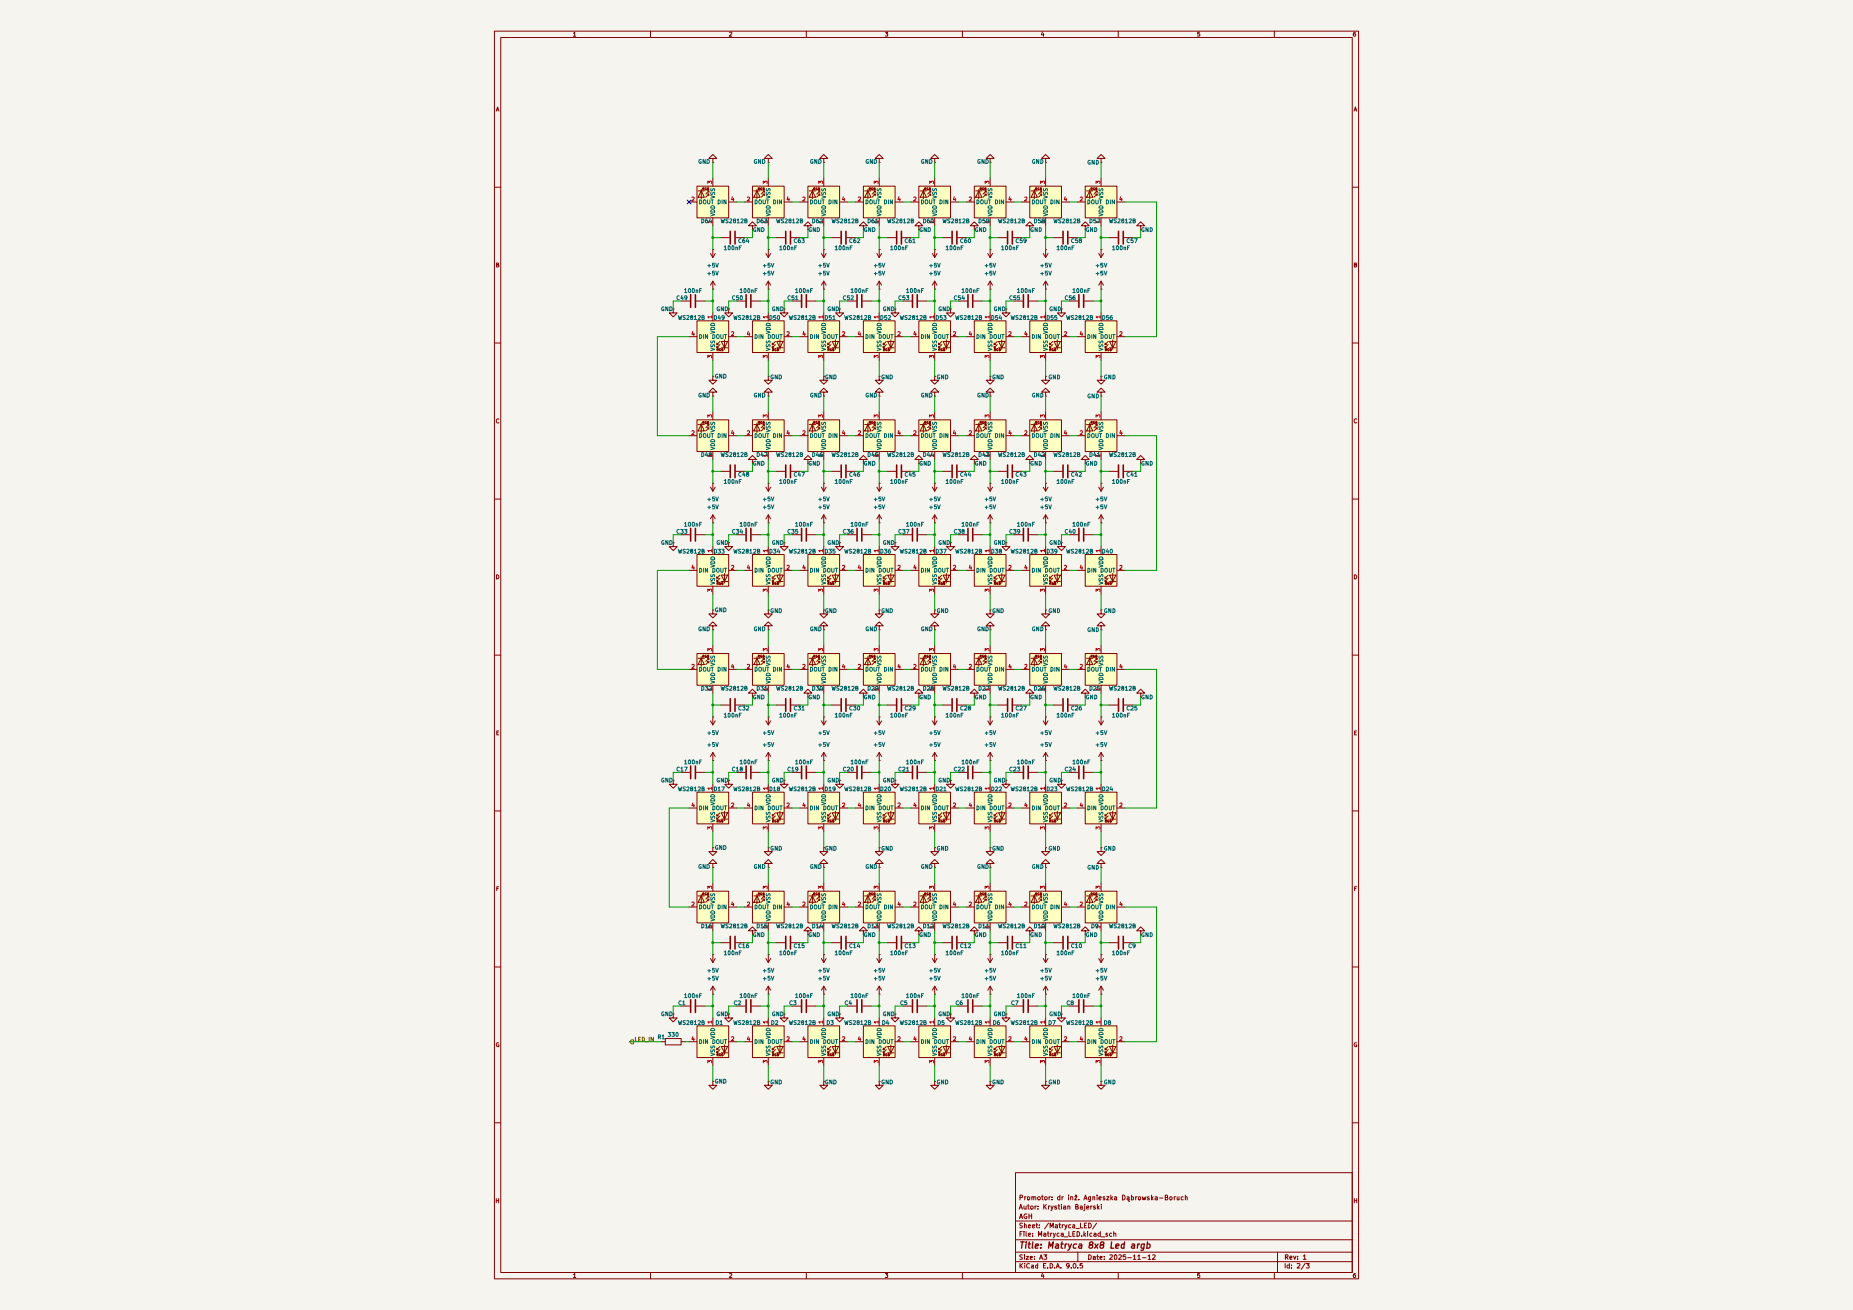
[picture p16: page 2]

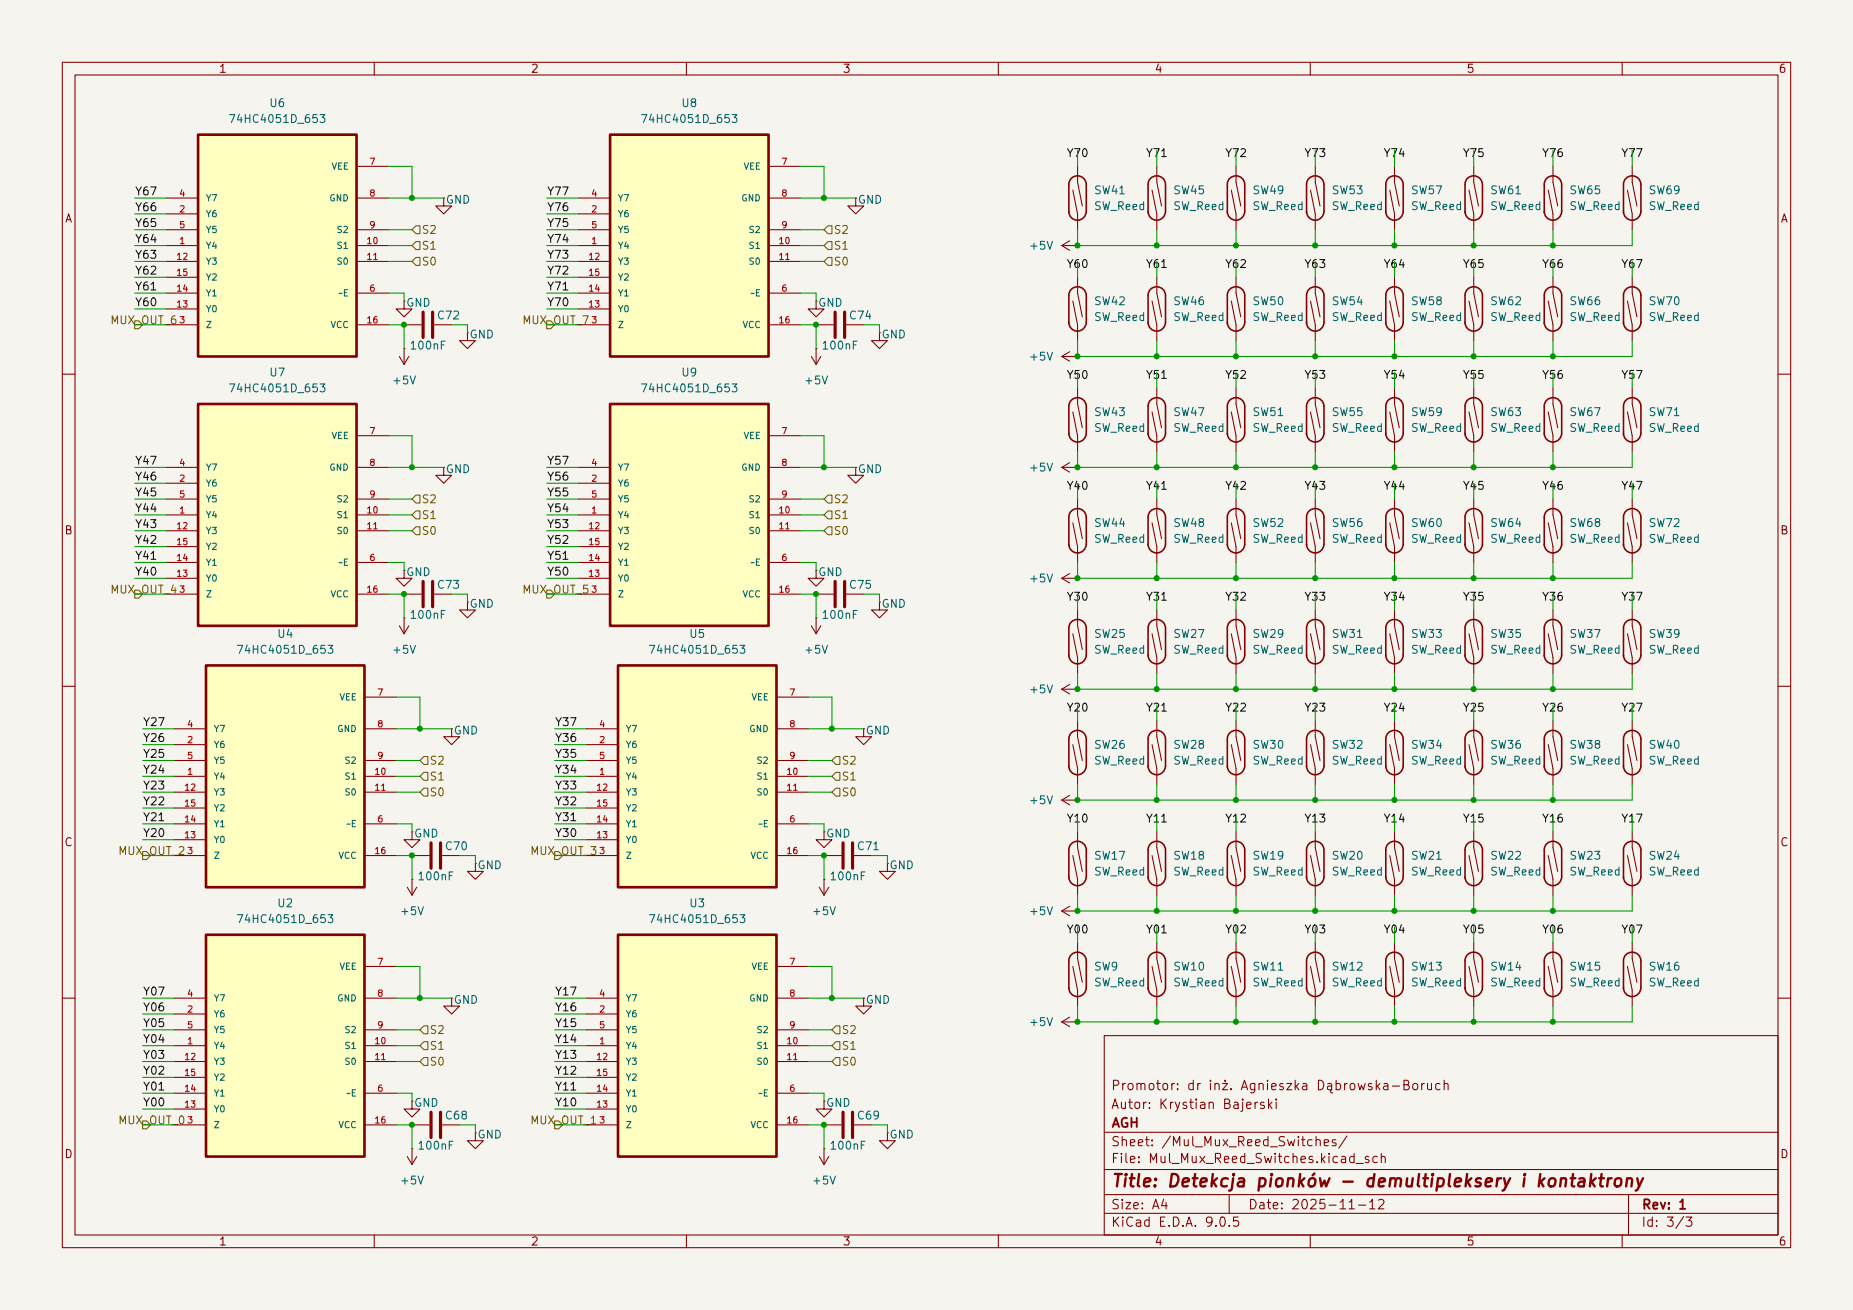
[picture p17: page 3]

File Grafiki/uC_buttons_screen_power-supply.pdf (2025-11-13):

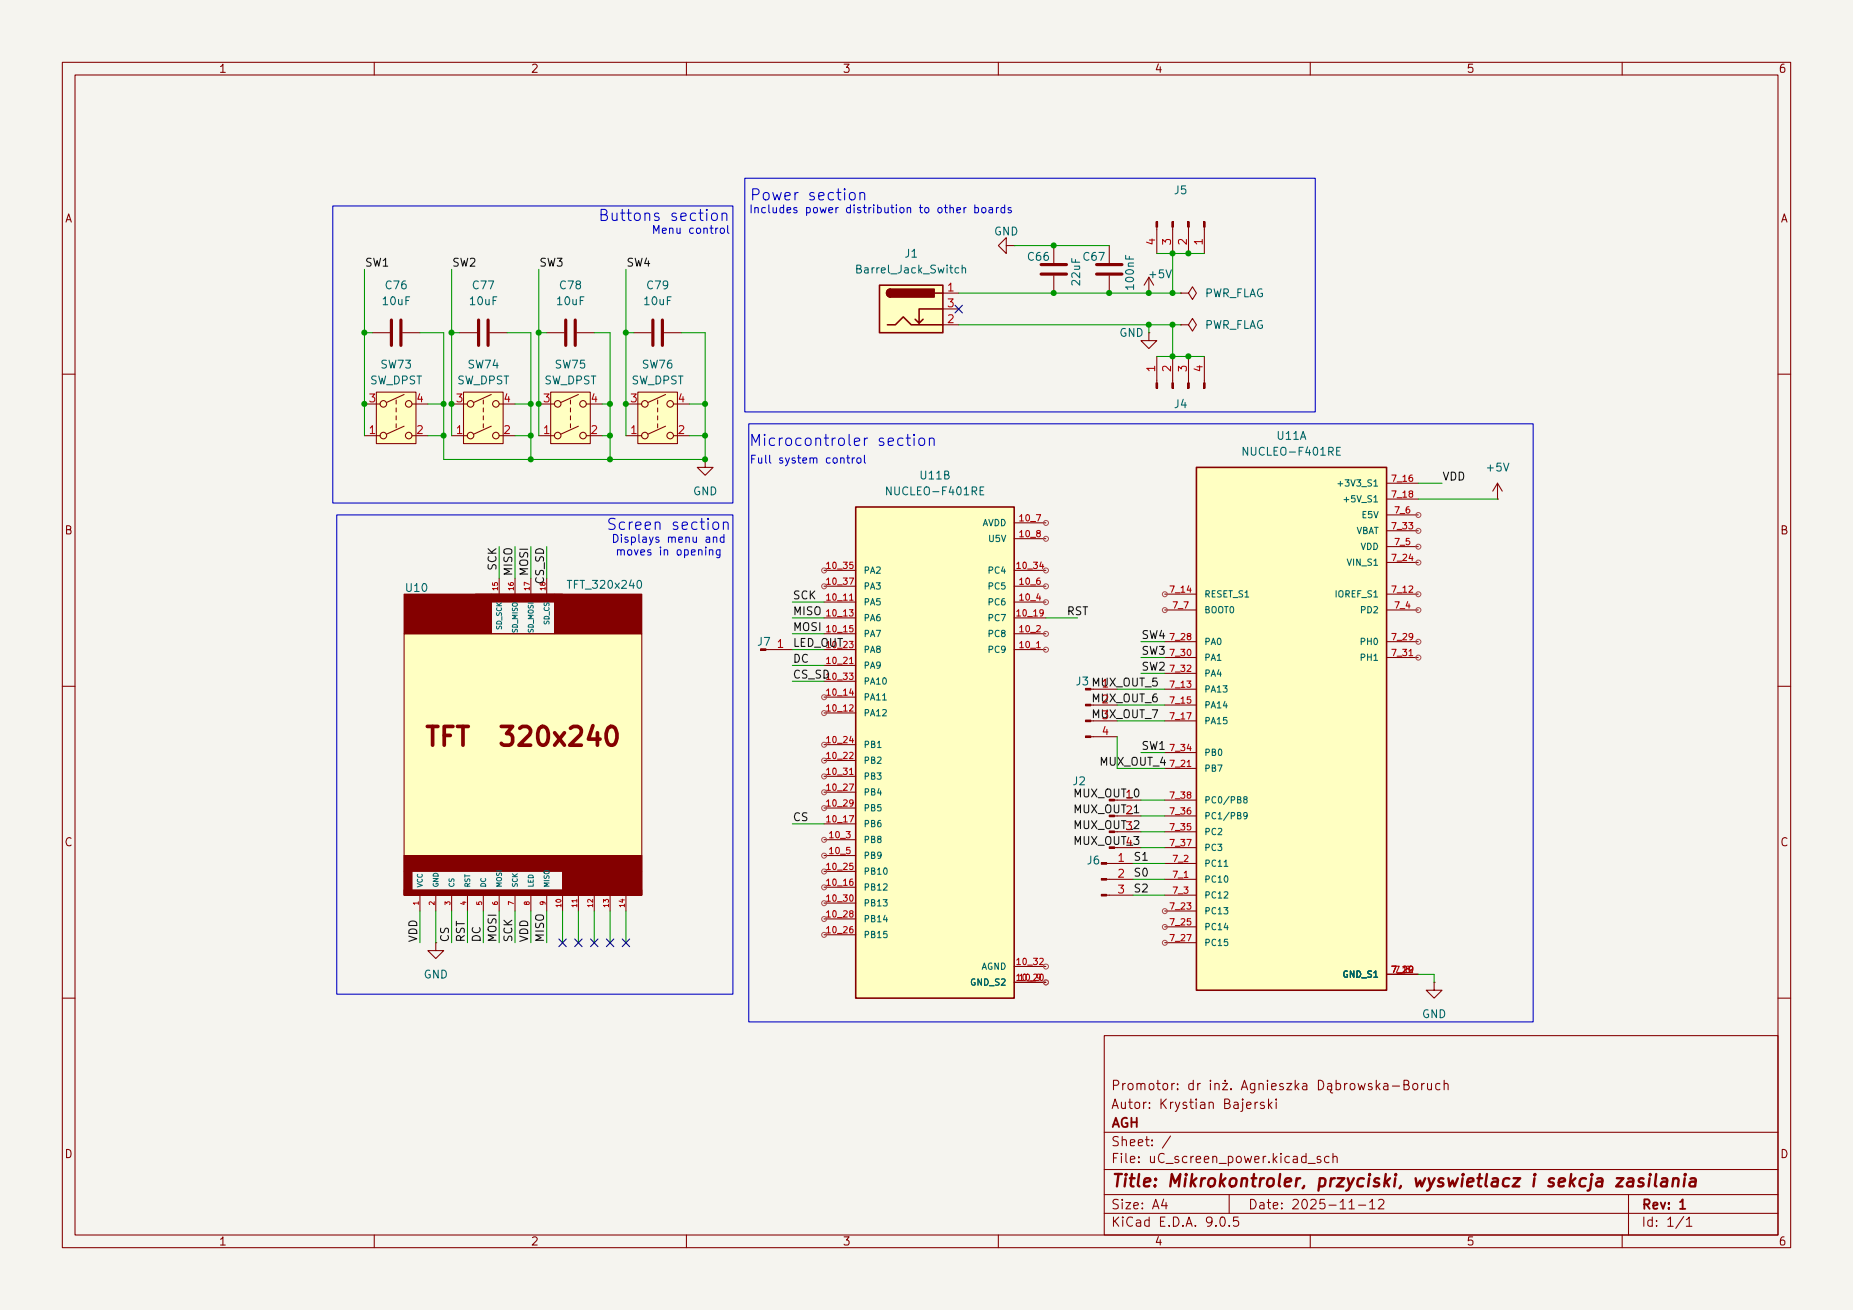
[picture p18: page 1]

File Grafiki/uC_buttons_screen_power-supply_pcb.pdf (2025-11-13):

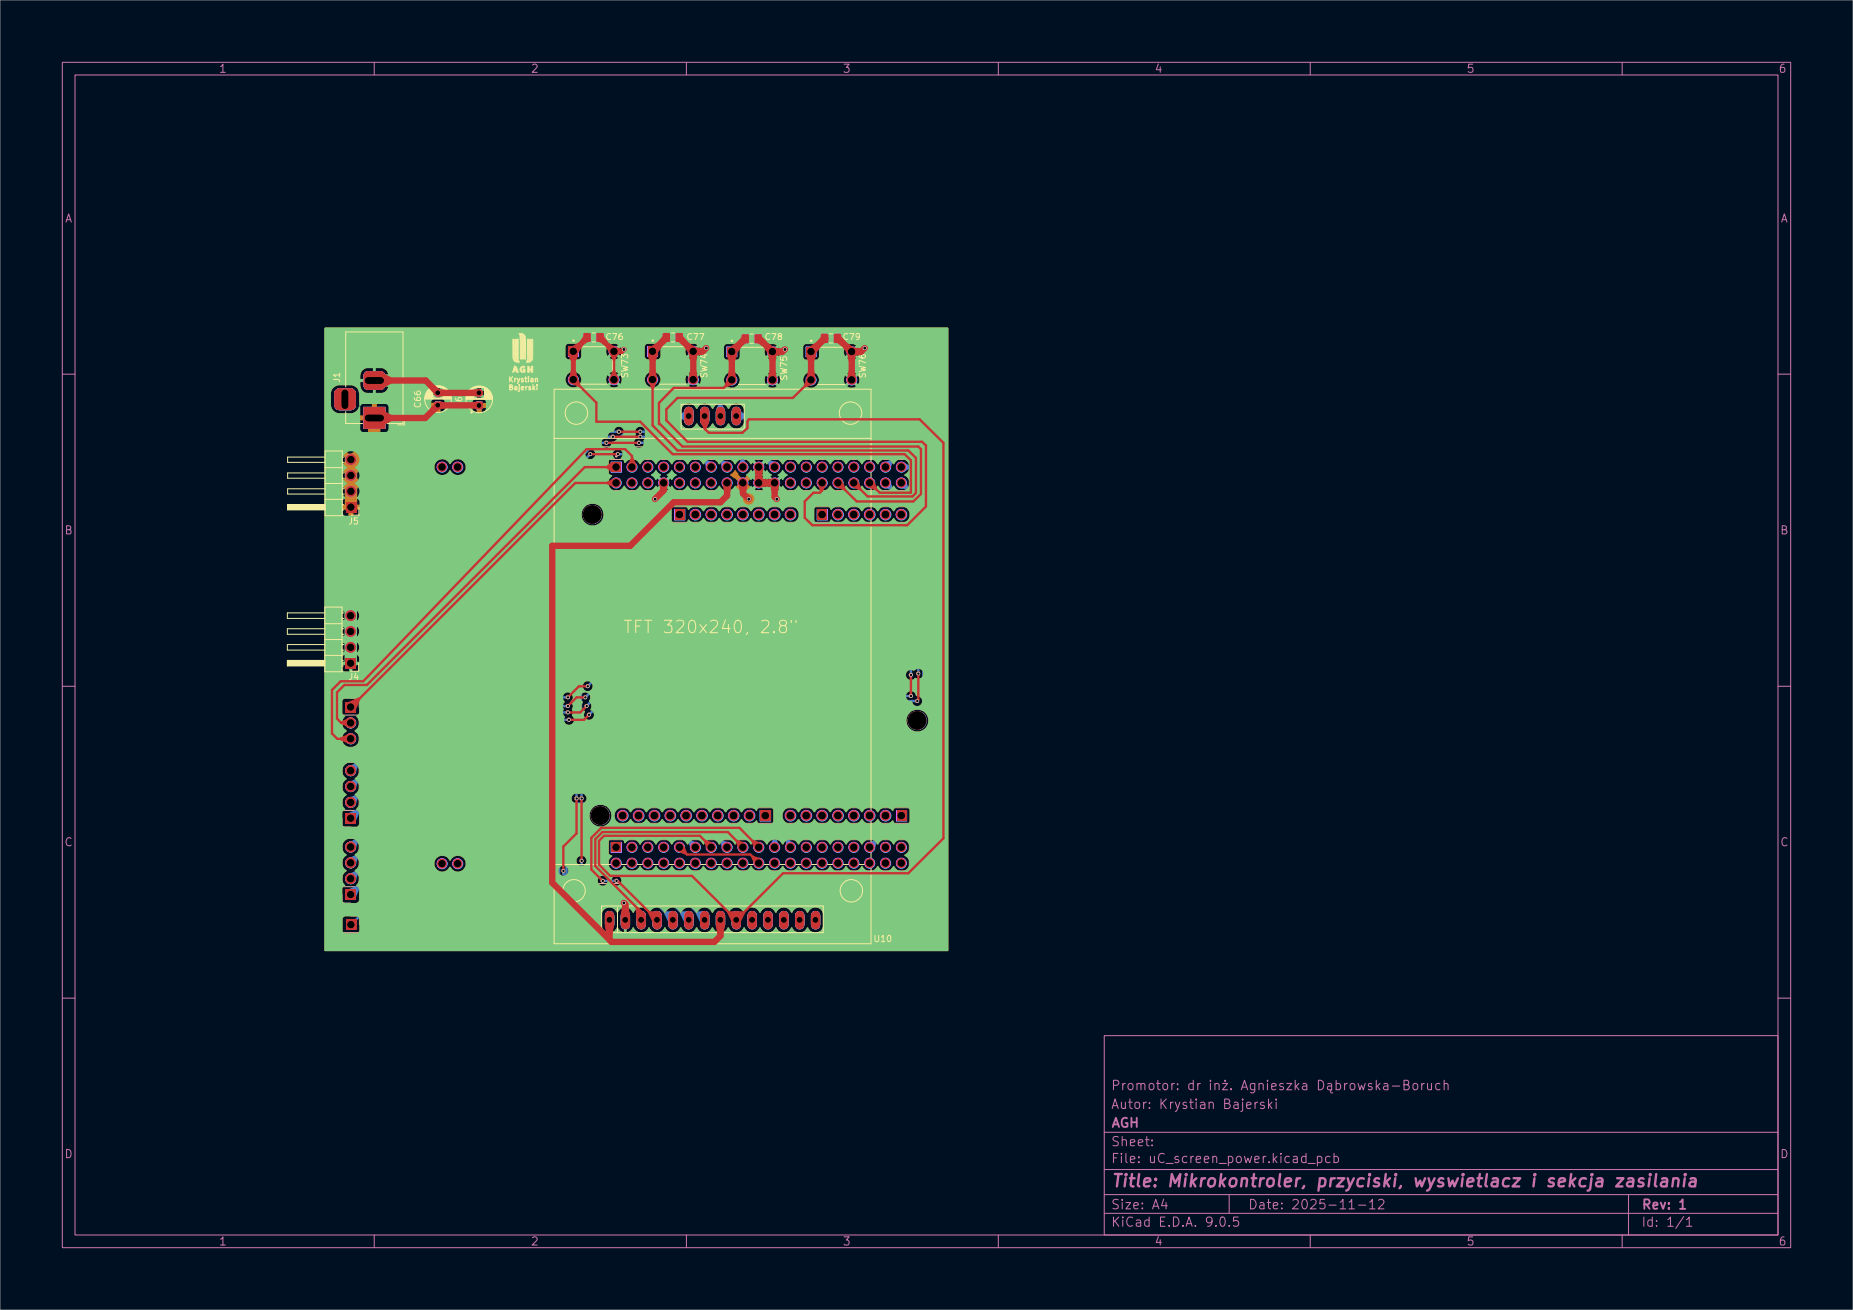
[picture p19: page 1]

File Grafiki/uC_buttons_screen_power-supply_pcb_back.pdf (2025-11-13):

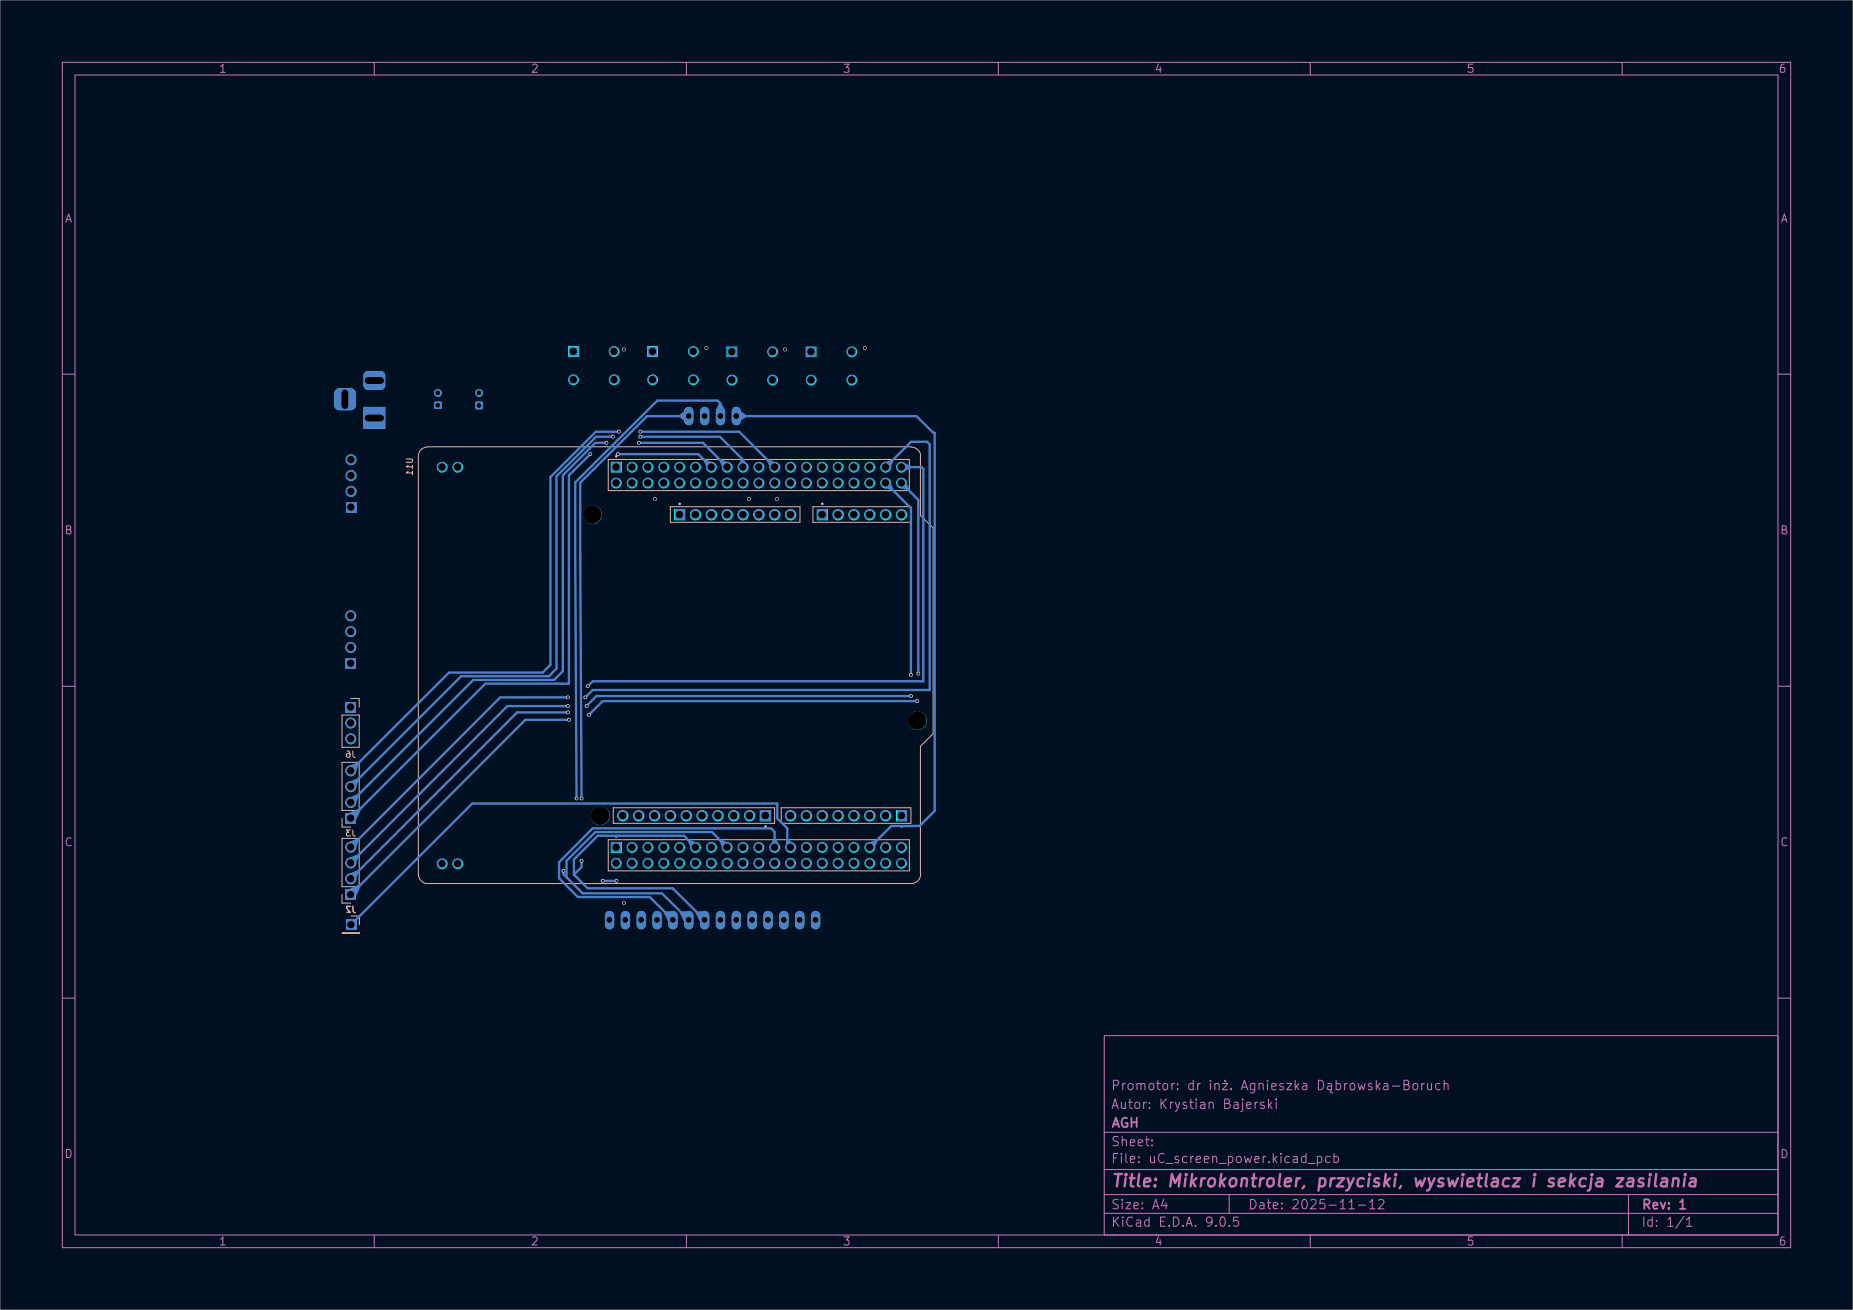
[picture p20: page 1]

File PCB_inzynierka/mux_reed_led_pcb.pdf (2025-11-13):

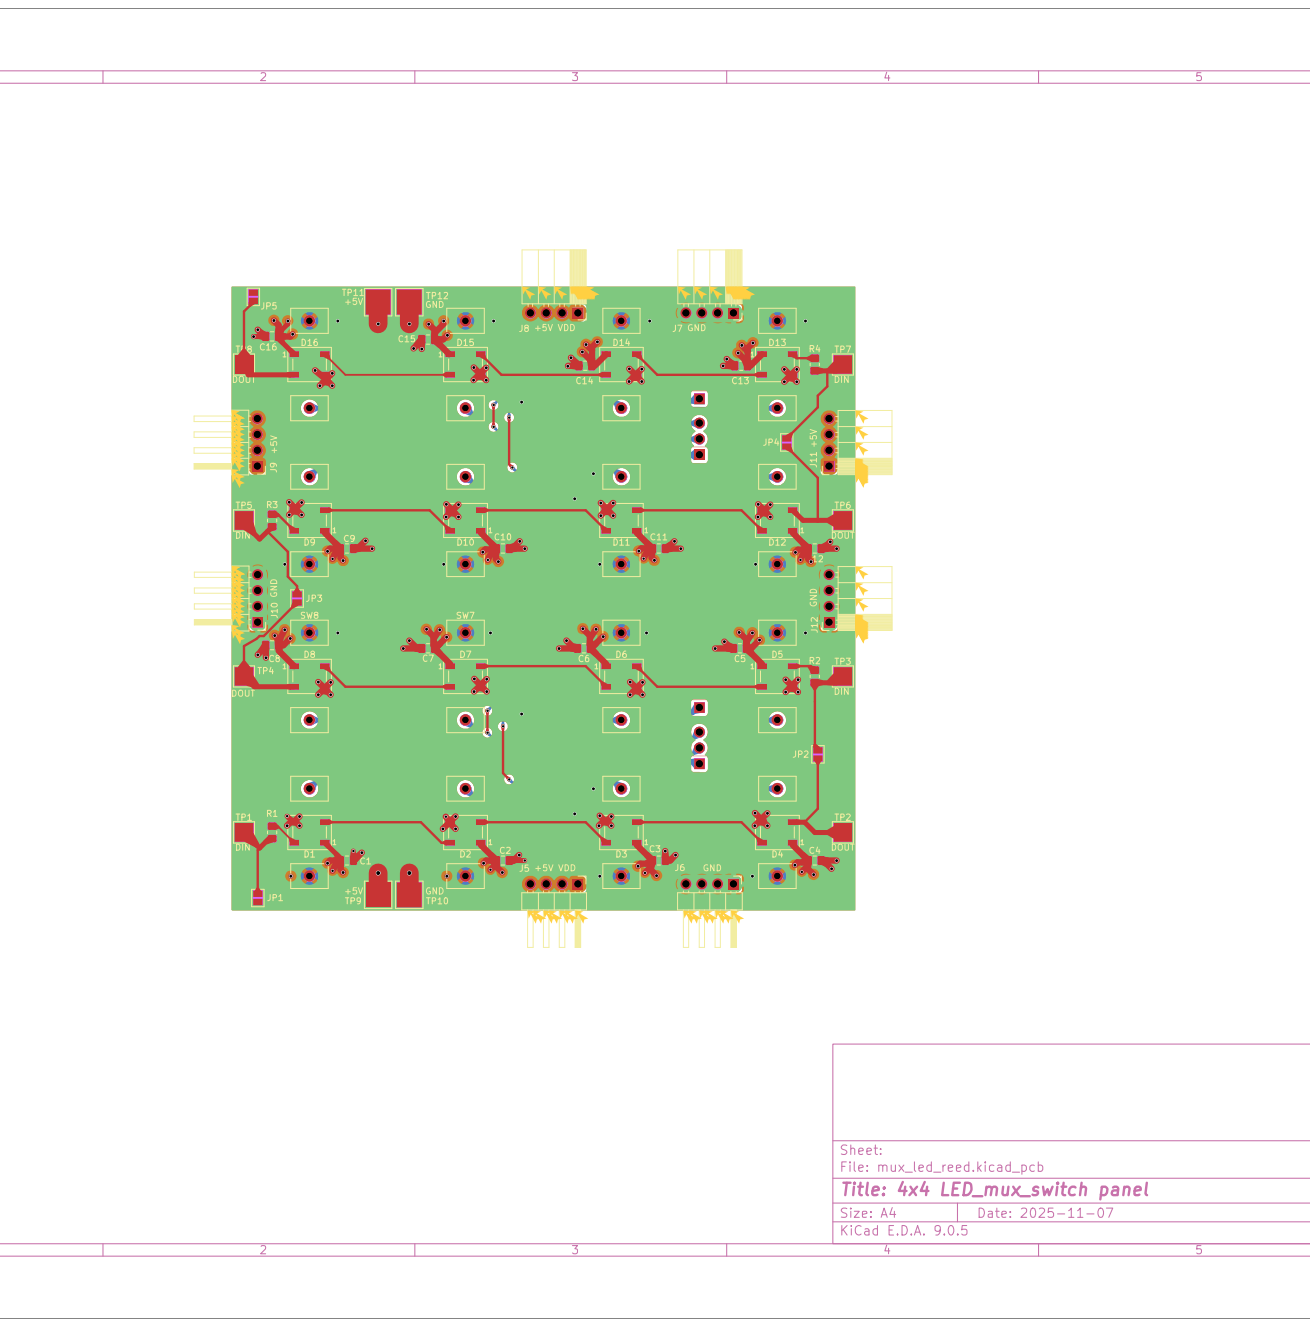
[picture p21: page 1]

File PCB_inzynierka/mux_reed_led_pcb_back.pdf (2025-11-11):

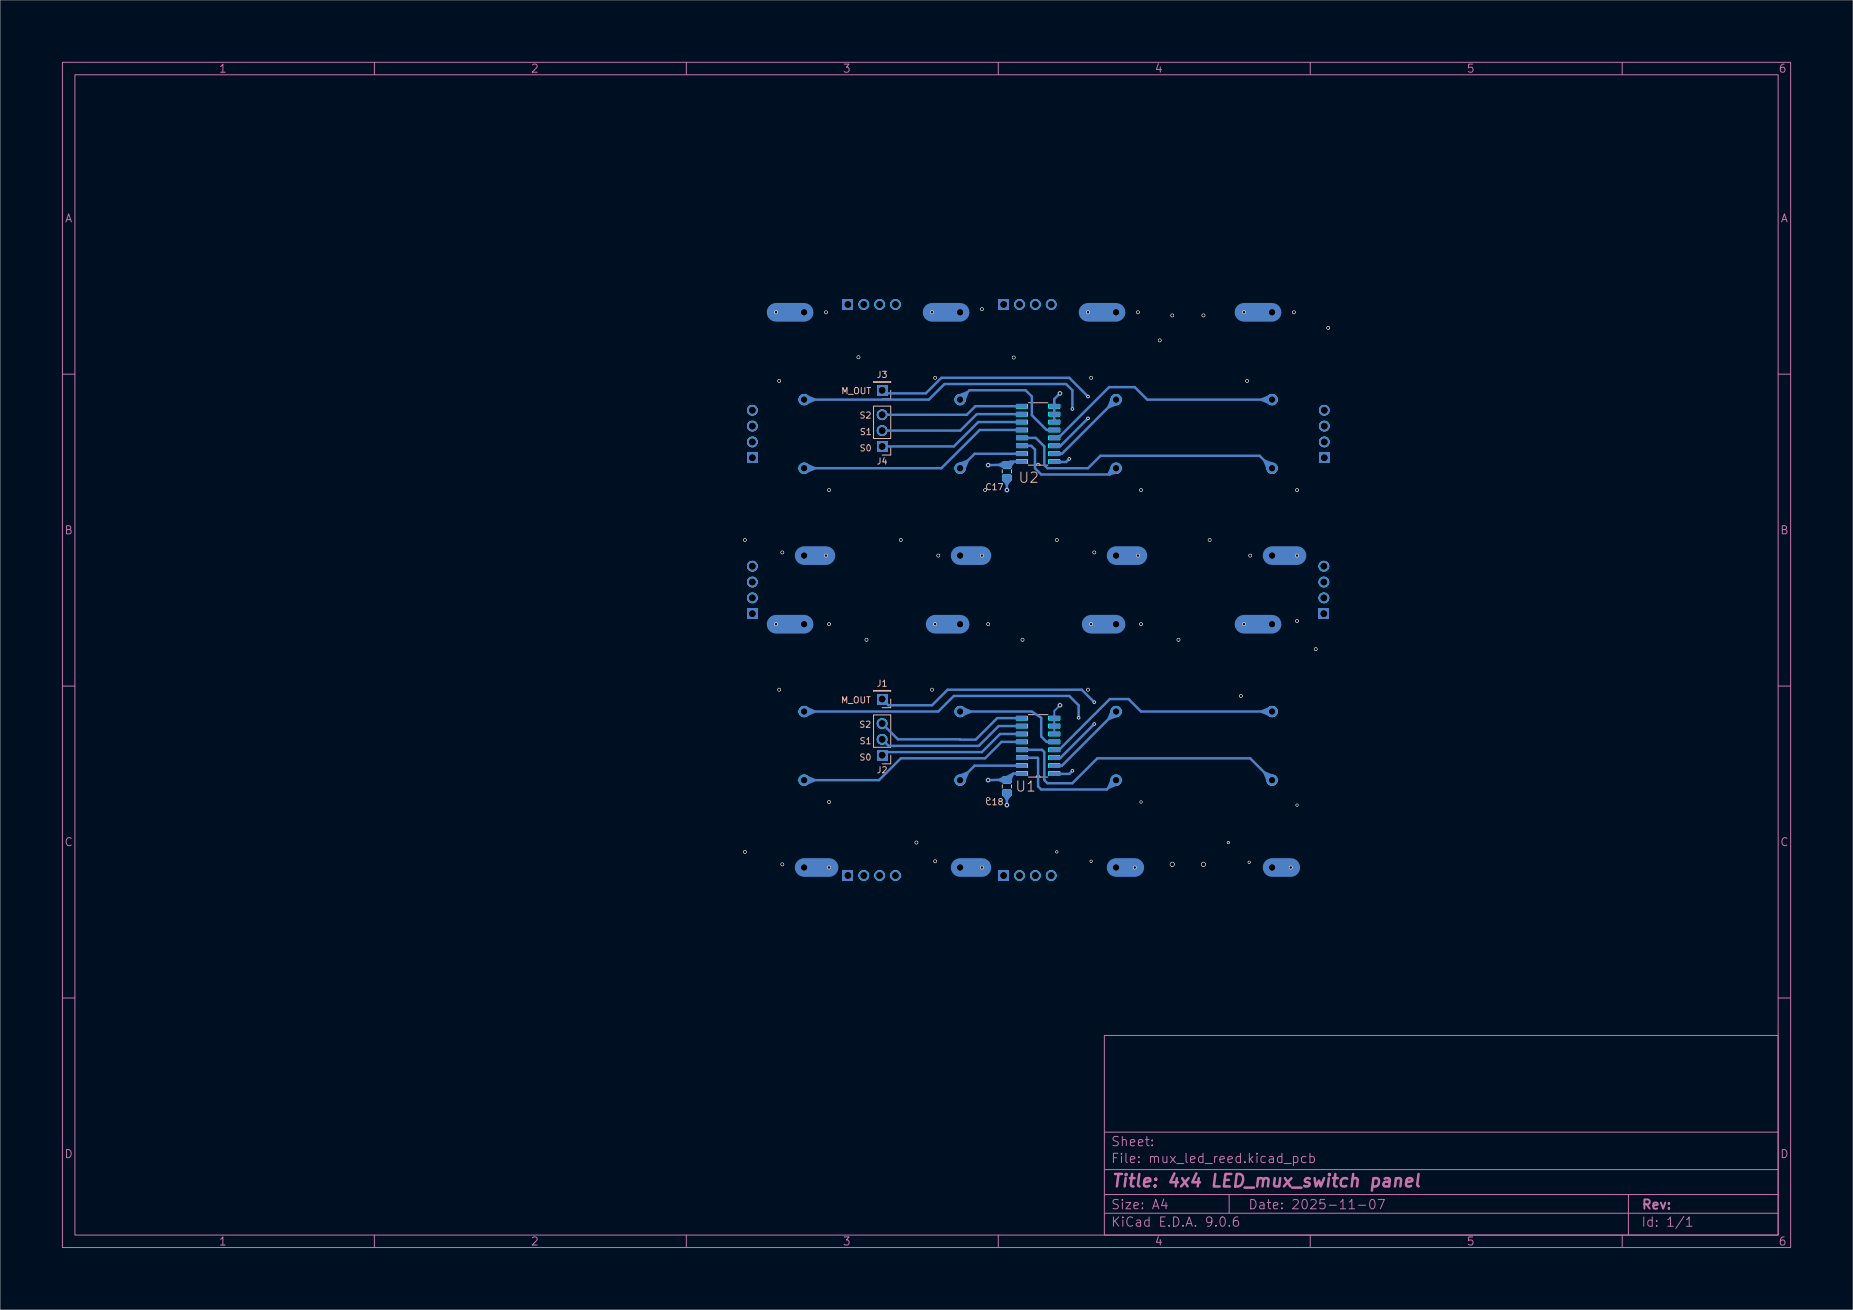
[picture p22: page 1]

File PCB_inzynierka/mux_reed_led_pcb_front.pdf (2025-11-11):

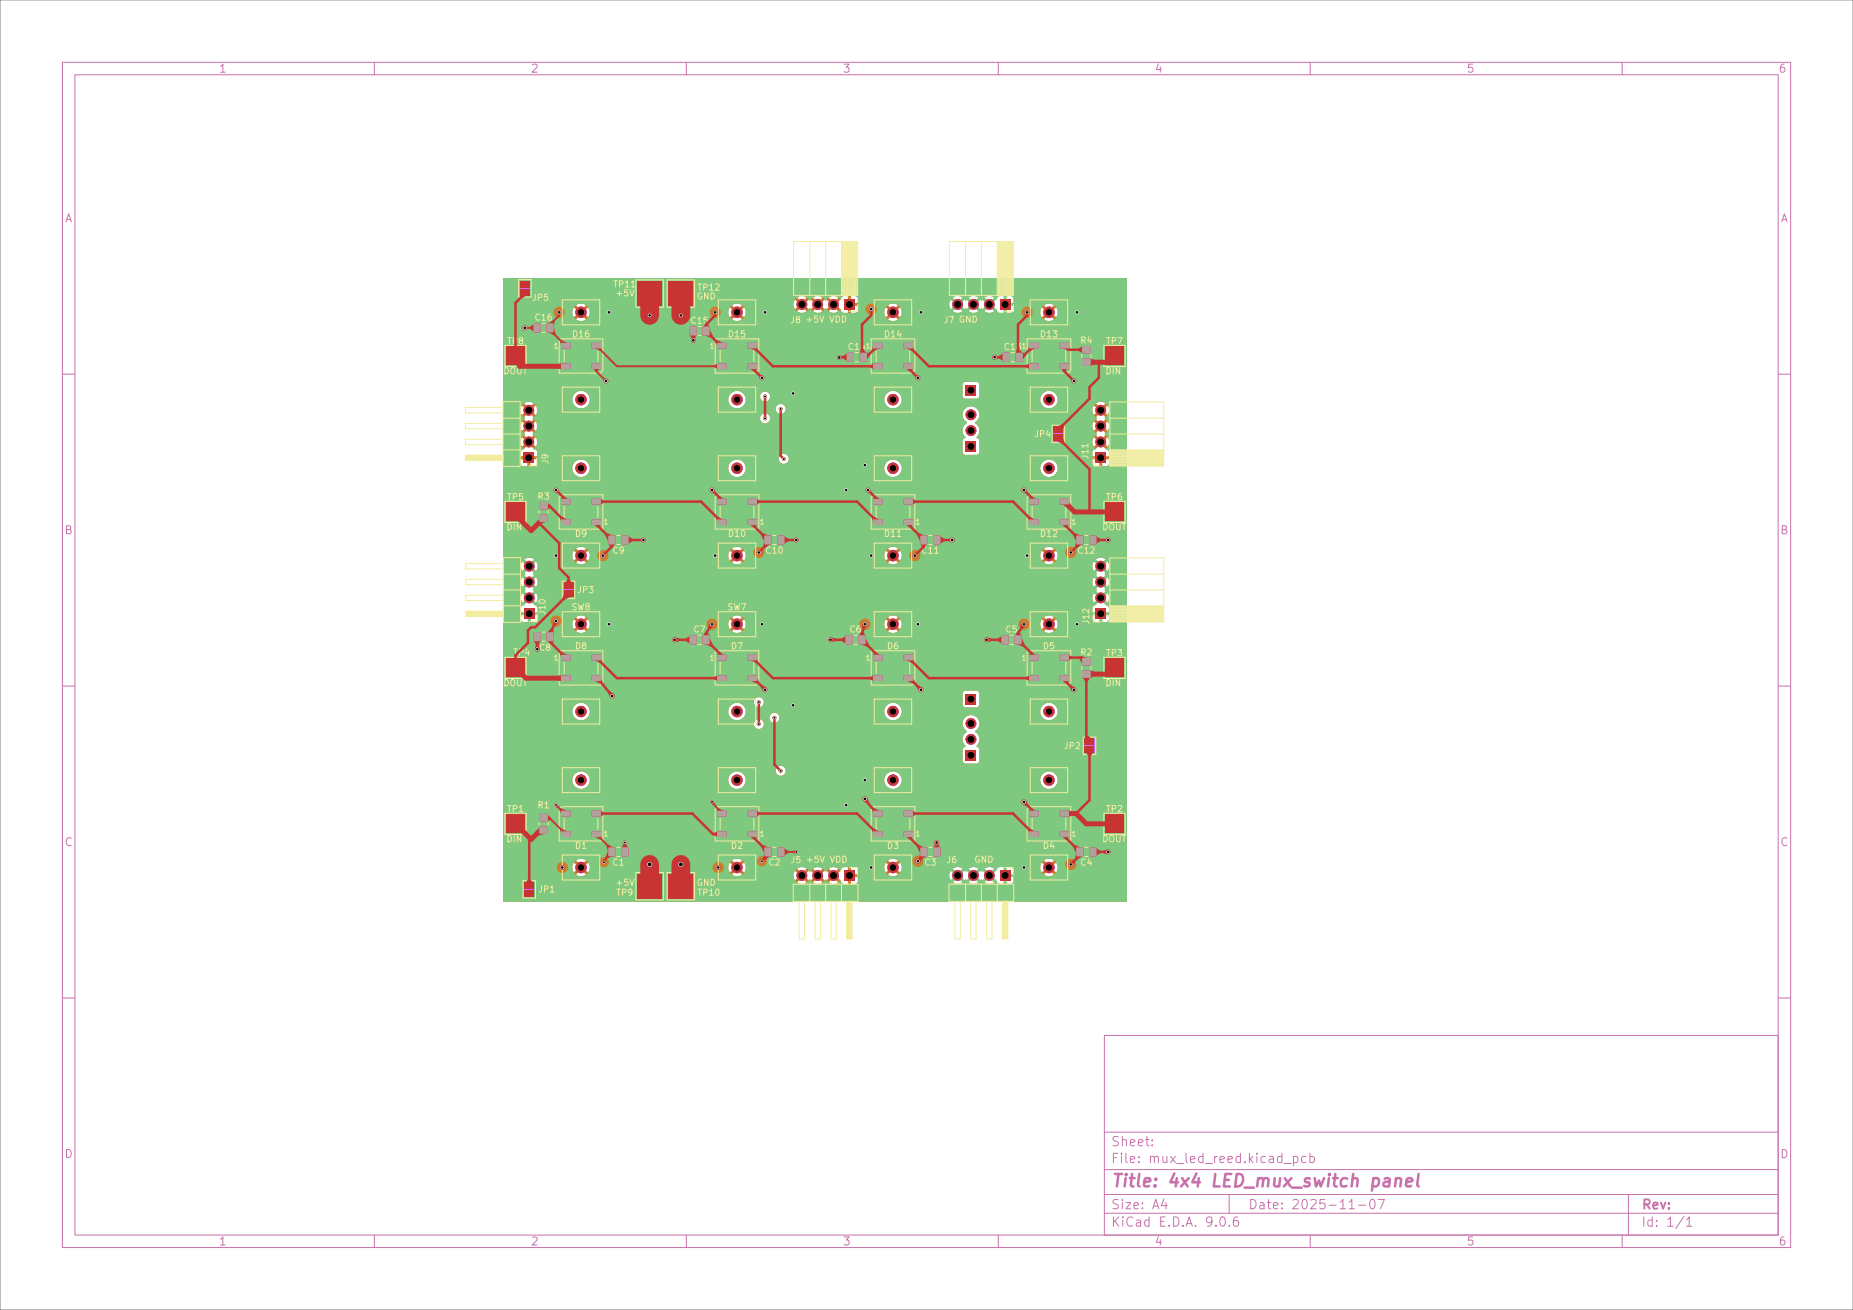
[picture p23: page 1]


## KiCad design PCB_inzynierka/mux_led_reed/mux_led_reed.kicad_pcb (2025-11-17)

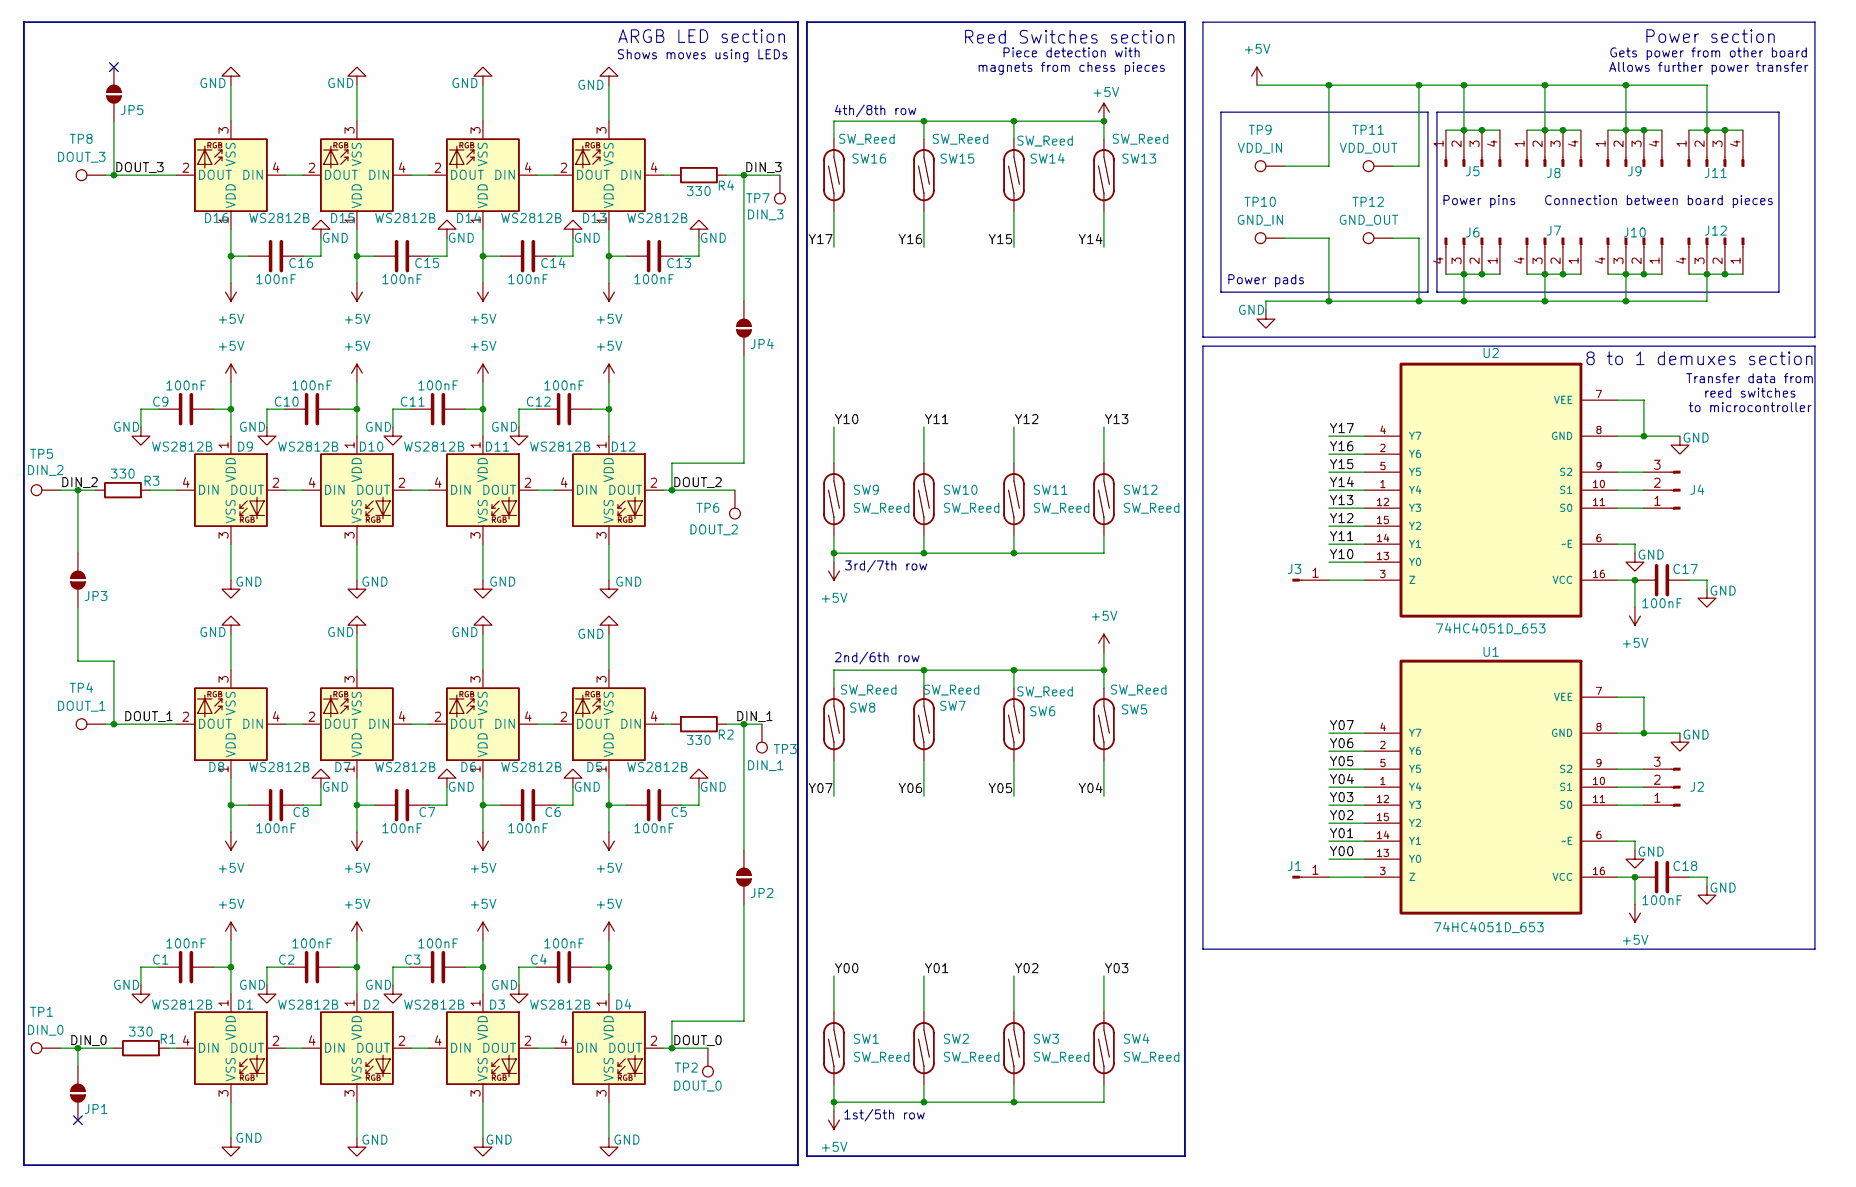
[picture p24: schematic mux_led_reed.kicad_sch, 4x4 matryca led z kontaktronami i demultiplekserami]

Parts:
C1, C2, C3, C4, C5, C6, C7, C8, C9, C10, C11, C12, C13, C14, C15, C16, C17, C18: 100nF; C_0805_2012Metric_Pad1.18x1.45mm_HandSolder
D1, D2, D3, D4, D5, D6, D7, D8, D9, D10, D11, D12, D13, D14, D15, D16: WS2812B; LED_WS2812B_PLCC4_5.0x5.0mm_P3.2mm
J1, J3: Conn_01x01_Pin; PinHeader_1x01_P2.54mm_Vertical
J2, J4: Conn_01x03_Pin; PinHeader_1x03_P2.54mm_Vertical
J5, J6, J9, J10: Conn_01x04_Pin; PinHeader_1x04_P2.54mm_Horizontal
J7, J8, J11, J12: Conn_01x04_Pin; PinSocket_1x04_P2.54mm_Horizontal
JP1, JP2, JP3, JP4, JP5: SolderJumper_2_Open; SolderJumper-2_P1.3mm_Open_Pad1.0x1.5mm
R1, R2, R3, R4: 330; R_0805_2012Metric_Pad1.20x1.40mm_HandSolder
SW1, SW2, SW3, SW4, SW5, SW6, SW7, SW8, SW9, SW10, SW11, SW12, SW13, SW14, SW15, SW16: SW_Reed; ReedSwitch_2x14mm
TP1: DIN_0; TestPoint_Pad_3.0x3.0mm
TP2: DOUT_0; TestPoint_Pad_3.0x3.0mm
TP3: DIN_1; TestPoint_Pad_3.0x3.0mm
TP4: DOUT_1; TestPoint_Pad_3.0x3.0mm
TP5: DIN_2; TestPoint_Pad_3.0x3.0mm
TP6: DOUT_2; TestPoint_Pad_3.0x3.0mm
TP7: DIN_3; TestPoint_Pad_3.0x3.0mm
TP8: DOUT_3; TestPoint_Pad_3.0x3.0mm
TP9: VDD_IN; TestPoint_Pad_4.0x4.0mm
TP10: GND_IN; TestPoint_Pad_4.0x4.0mm
TP11: VDD_OUT; TestPoint_Pad_4.0x4.0mm
TP12: GND_OUT; TestPoint_Pad_4.0x4.0mm
U1, U2: 74HC4051D_653; SOIC127P600X175-16N; MPN 74HC4051D,653

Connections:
+5V: C1.2, C2.2, C3.2, C4.2, C5.2, C6.2, C7.2, C8.2, C9.2, C10.2, C11.2, C12.2, C13.2, C14.2, C15.2, C16.2, C17.1, C18.1, D1.1 (VDD), D2.1 (VDD), D3.1 (VDD), D4.1 (VDD), D5.1 (VDD), D6.1 (VDD), D7.1 (VDD), D8.1 (VDD), D9.1 (VDD), D10.1 (VDD), D11.1 (VDD), D12.1 (VDD), D13.1 (VDD), D14.1 (VDD), D15.1 (VDD), D16.1 (VDD), J5.1, J5.2, J5.3, J5.4, J8.1, J8.2, J8.3, J8.4, J9.1, J9.2, J9.3, J9.4, J11.1, J11.2, J11.3, J11.4, SW1.2, SW2.2, SW3.2, SW4.2, SW5.2, SW6.2, SW7.2, SW8.2, SW9.2, SW10.2, SW11.2, SW12.2, SW13.2, SW14.2, SW15.2, SW16.2, TP9.1, TP11.1, U1.16 (VCC), U2.16 (VCC)
/DIN_0: JP1.2 (B), R1.1, TP1.1
/DIN_1: JP2.2 (B), R2.1, TP3.1
/DIN_2: JP3.2 (B), R3.1, TP5.1
/DIN_3: JP4.2 (B), R4.1, TP7.1
/DOUT_0: D4.2 (DOUT), JP2.1 (A), TP2.1
/DOUT_1: D8.2 (DOUT), JP3.1 (A), TP4.1
/DOUT_2: D12.2 (DOUT), JP4.1 (A), TP6.1
/DOUT_3: D16.2 (DOUT), JP5.1 (A), TP8.1
/Y00: SW1.1, U1.13 (Y0)
/Y01: SW2.1, U1.14 (Y1)
/Y02: SW3.1, U1.15 (Y2)
/Y03: SW4.1, U1.12 (Y3)
/Y04: SW5.1, U1.1 (Y4)
/Y05: SW6.1, U1.5 (Y5)
/Y06: SW7.1, U1.2 (Y6)
/Y07: SW8.1, U1.4 (Y7)
/Y10: SW9.1, U2.13 (Y0)
/Y11: SW10.1, U2.14 (Y1)
/Y12: SW11.1, U2.15 (Y2)
/Y13: SW12.1, U2.12 (Y3)
/Y14: SW13.1, U2.1 (Y4)
/Y15: SW14.1, U2.5 (Y5)
/Y16: SW15.1, U2.2 (Y6)
/Y17: SW16.1, U2.4 (Y7)
GND: C1.1, C2.1, C3.1, C4.1, C5.1, C6.1, C7.1, C8.1, C9.1, C10.1, C11.1, C12.1, C13.1, C14.1, C15.1, C16.1, C17.2, C18.2, D1.3 (VSS), D2.3 (VSS), D3.3 (VSS), D4.3 (VSS), D5.3 (VSS), D6.3 (VSS), D7.3 (VSS), D8.3 (VSS), D9.3 (VSS), D10.3 (VSS), D11.3 (VSS), D12.3 (VSS), D13.3 (VSS), D14.3 (VSS), D15.3 (VSS), D16.3 (VSS), J6.1, J6.2, J6.3, J6.4, J7.1, J7.2, J7.3, J7.4, J10.1, J10.2, J10.3, J10.4, J12.1, J12.2, J12.3, J12.4, TP10.1, TP12.1, U1.6 (~E), U1.7 (VEE), U1.8 (GND), U2.6 (~E), U2.7 (VEE), U2.8 (GND)
unnamed: D1.4 (DIN), R1.2
unnamed: D1.2 (DOUT), D2.4 (DIN)
unnamed: D2.2 (DOUT), D3.4 (DIN)
unnamed: D3.2 (DOUT), D4.4 (DIN)
unnamed: D5.4 (DIN), R2.2
unnamed: D5.2 (DOUT), D6.4 (DIN)
unnamed: D6.2 (DOUT), D7.4 (DIN)
unnamed: D7.2 (DOUT), D8.4 (DIN)
unnamed: D9.4 (DIN), R3.2
unnamed: D9.2 (DOUT), D10.4 (DIN)
unnamed: D10.2 (DOUT), D11.4 (DIN)
unnamed: D11.2 (DOUT), D12.4 (DIN)
unnamed: D13.4 (DIN), R4.2
unnamed: D13.2 (DOUT), D14.4 (DIN)
unnamed: D14.2 (DOUT), D15.4 (DIN)
unnamed: D15.2 (DOUT), D16.4 (DIN)
unnamed: J1.1, U1.3 (Z)
unnamed: J2.1, U1.11 (S0)
unnamed: J2.2, U1.10 (S1)
unnamed: J2.3, U1.9 (S2)
unnamed: J3.1, U2.3 (Z)
unnamed: J4.1, U2.11 (S0)
unnamed: J4.2, U2.10 (S1)
unnamed: J4.3, U2.9 (S2)

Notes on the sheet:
ARGB LED section
Gets power from other board Allows further power transfer
2nd/6th row
Shows moves using LEDs
1st/5th row
Power pads
Power section
8 to 1 demuxes section
Reed Switches section
Power pins Connection between board pieces
Piece detection with magnets from chess pieces
4th/8th row
Transfer data from reed switches to microcontroller
3rd/7th row

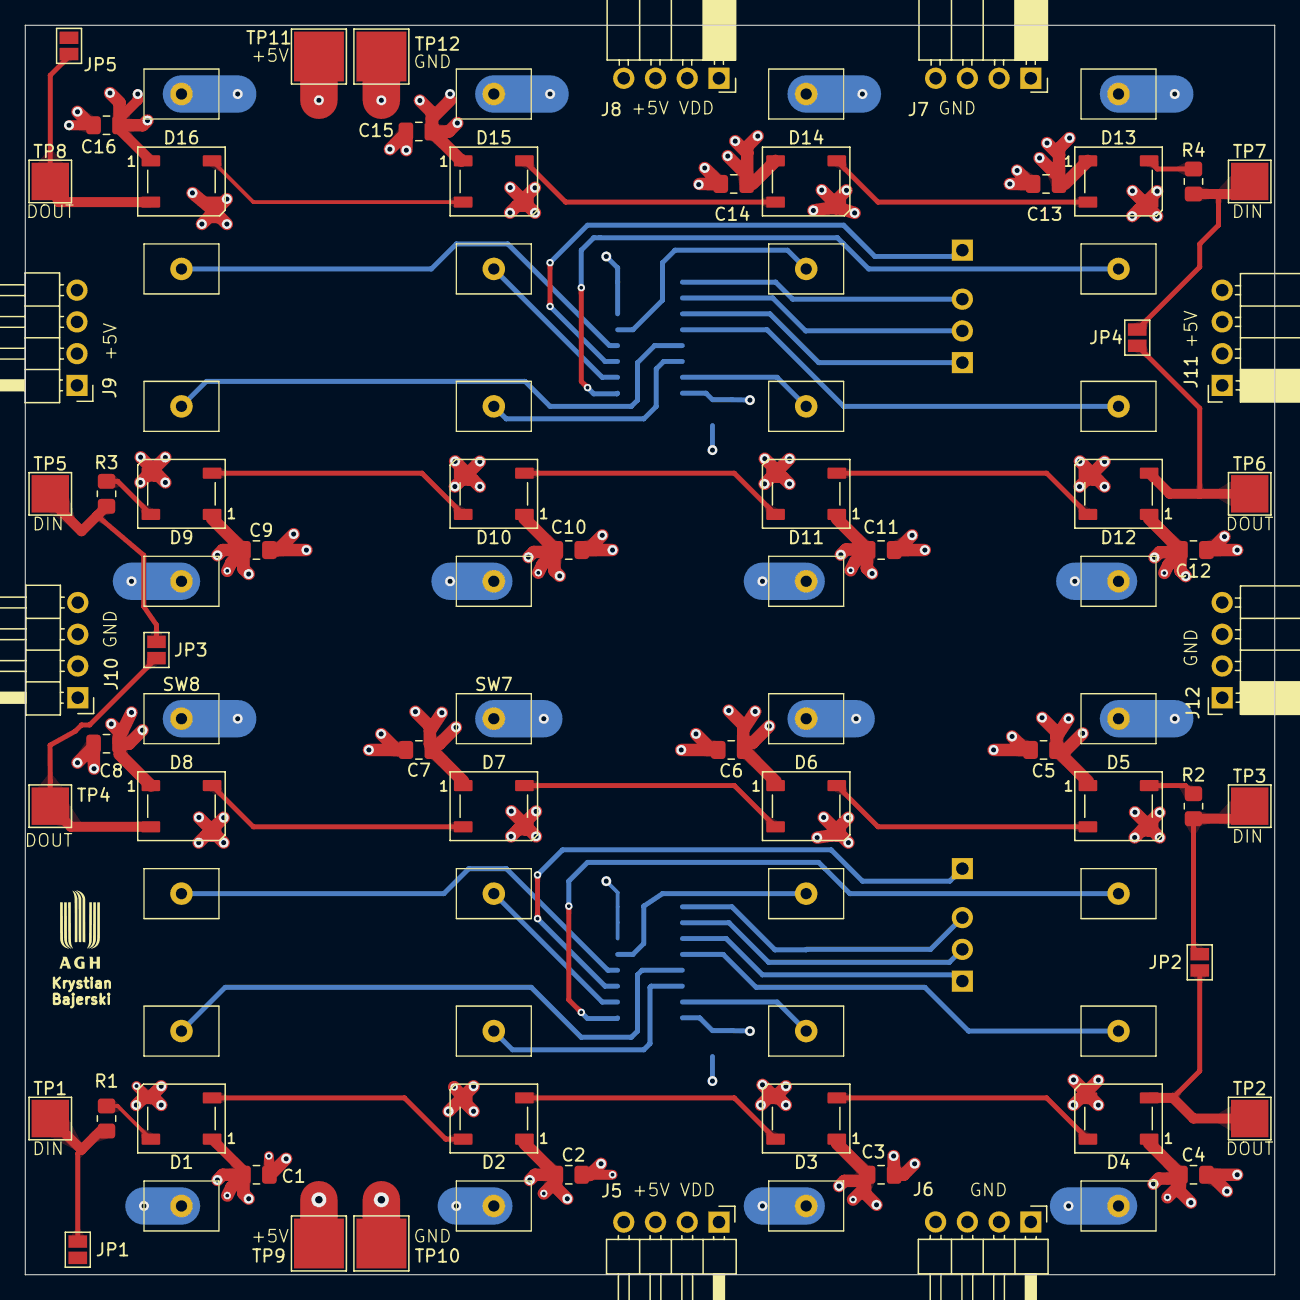
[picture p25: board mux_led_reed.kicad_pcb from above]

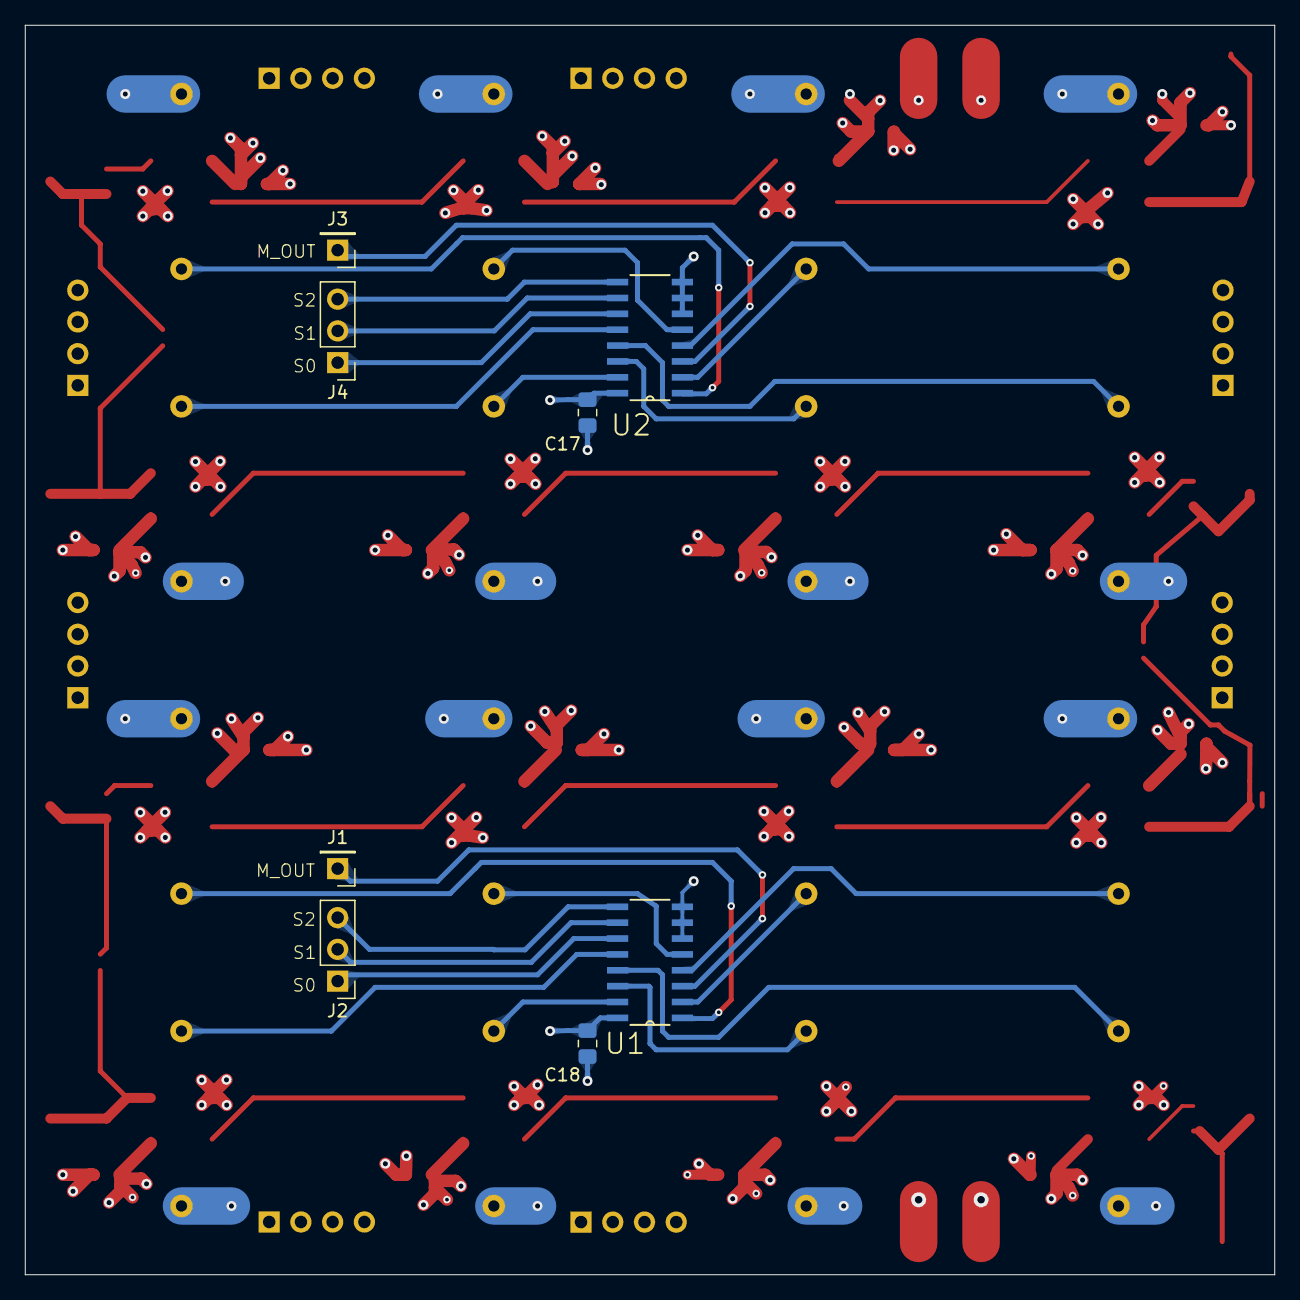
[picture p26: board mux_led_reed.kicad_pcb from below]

Board: 4 copper layers, 100.0 x 100.0 mm, 85 parts (8 on the bottom side), 50 nets.

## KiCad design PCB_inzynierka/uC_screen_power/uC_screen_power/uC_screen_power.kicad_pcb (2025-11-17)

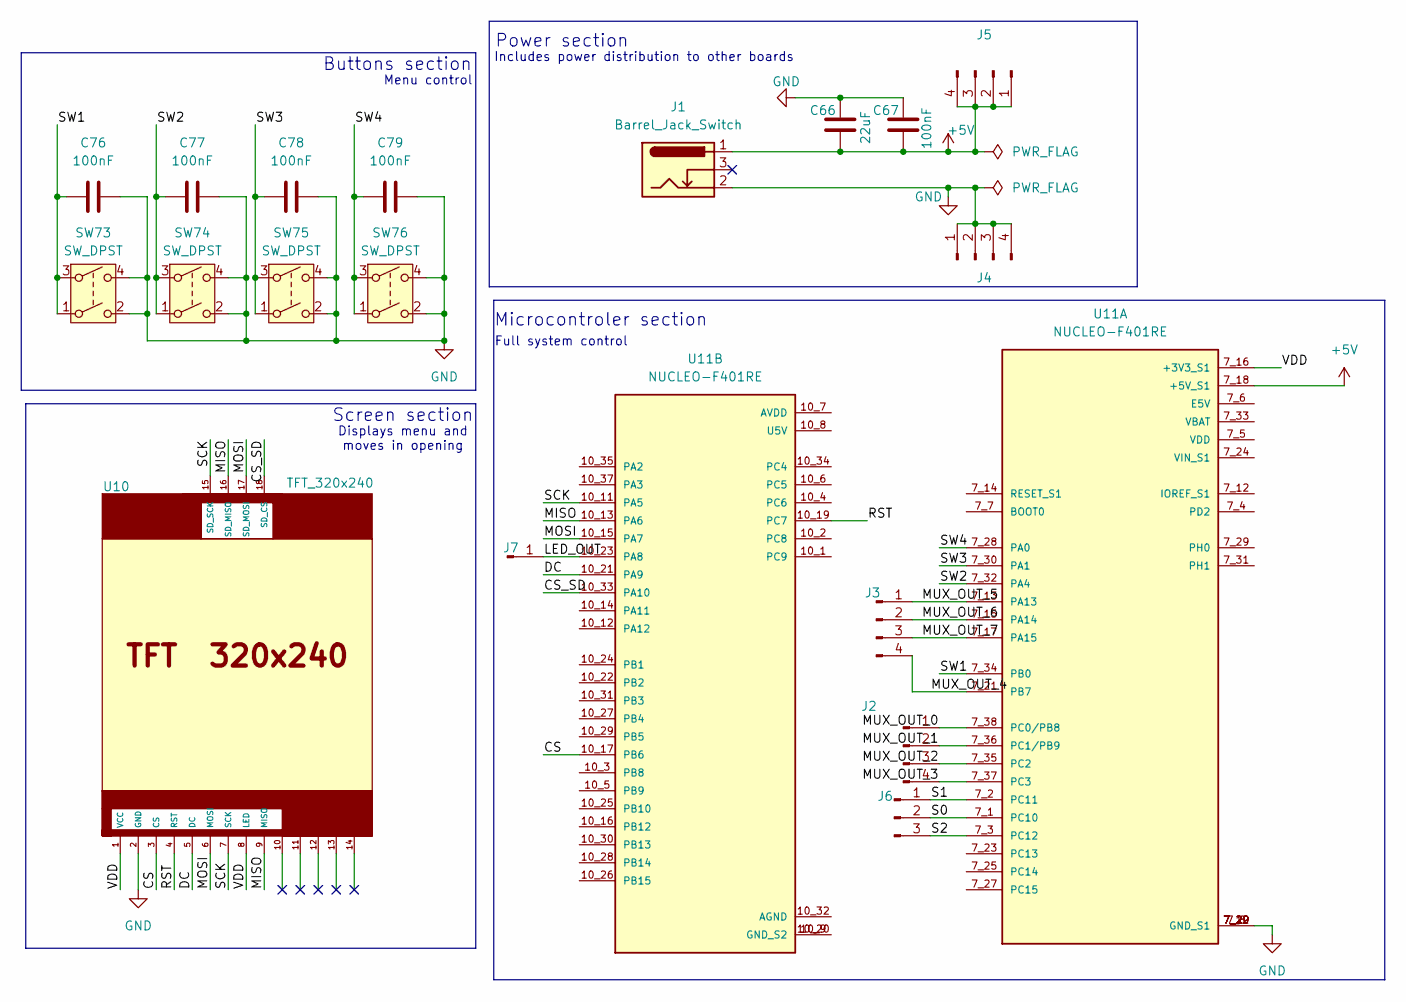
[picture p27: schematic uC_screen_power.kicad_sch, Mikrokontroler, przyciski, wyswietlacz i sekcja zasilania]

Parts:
C66: 22uF; CP_Radial_D4.0mm_P2.00mm
C67: 100nF; CP_Radial_D4.0mm_P2.00mm
C76, C77, C78, C79: 100nF; C_0805_2012Metric_Pad1.18x1.45mm_HandSolder
J1: Barrel_Jack_Switch; BarrelJack_Horizontal
J2, J3: Conn_01x04_Pin; PinHeader_1x04_P2.54mm_Vertical
J4, J5: Conn_01x04_Pin; PinHeader_1x04_P2.54mm_Horizontal
J6: Conn_01x03_Pin; PinHeader_1x03_P2.54mm_Vertical
J7: Conn_01x01_Pin; PinHeader_1x01_P2.54mm_Vertical
SW73, SW74, SW75, SW76: SW_DPST; SW_TS02-66-60-BK-100-LCR-D
U10: TFT_320x240; TFT-320x240
U11: NUCLEO-F401RE; ST_NUCLEO-F401RE; PARTREV 13

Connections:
+5V: C66.1, C67.1, J1.1, J5.1, J5.2, J5.3, J5.4, U11.7_18 (+5V_S1)
/CS: U10.3 (CS), U11.10_17 (PB6)
/CS_SD: U10.18 (SD_CS), U11.10_33 (PA10)
/DC: U10.5 (DC), U11.10_21 (PA9)
/LED_OUT: J7.1, U11.10_23 (PA8)
/MISO: U10.9 (MISO), U10.16 (SD_MISO), U11.10_13 (PA6)
/MOSI: U10.6 (MOSI), U10.17 (SD_MOSI), U11.10_15 (PA7)
/MUX_OUT_0: J2.1, U11.7_38 (PC0/PB8)
/MUX_OUT_1: J2.2, U11.7_36 (PC1/PB9)
/MUX_OUT_2: J2.3, U11.7_35 (PC2)
/MUX_OUT_3: J2.4, U11.7_37 (PC3)
/MUX_OUT_4: J3.4, U11.7_21 (PB7)
/MUX_OUT_5: J3.1, U11.7_13 (PA13)
/MUX_OUT_6: J3.2, U11.7_15 (PA14)
/MUX_OUT_7: J3.3, U11.7_17 (PA15)
/RST: U10.4 (RST), U11.10_19 (PC7)
/S0: J6.2, U11.7_1 (PC10)
/S1: J6.1, U11.7_2 (PC11)
/S2: J6.3, U11.7_3 (PC12)
/SCK: U10.7 (SCK), U10.15 (SD_SCK), U11.10_11 (PA5)
/SW1: C76.1, SW73.1, SW73.3, U11.7_34 (PB0)
/SW2: C77.1, SW74.1, SW74.3, U11.7_32 (PA4)
/SW3: C78.1, SW75.1, SW75.3, U11.7_30 (PA1)
/SW4: C79.1, SW76.1, SW76.3, U11.7_28 (PA0)
/VDD: U10.1 (VCC), U10.8 (LED), U11.7_16 (+3V3_S1)
GND: C66.2, C67.2, C76.2, C77.2, C78.2, C79.2, J1.2, J4.1, J4.2, J4.3, J4.4, SW73.2, SW73.4, SW74.2, SW74.4, SW75.2, SW75.4, SW76.2, SW76.4, U10.2 (GND), U11.7_8 (GND_S1), U11.7_19 (GND_S1), U11.7_20 (GND_S1), U11.7_22 (GND_S1)
unnamed: U11.10_9 (GND_S2), U11.10_20 (GND_S2)

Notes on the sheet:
Microcontroler section
Power section
Full system control
Menu control
Displays menu and moves in opening
Screen section
Buttons section
Includes power distribution to other boards

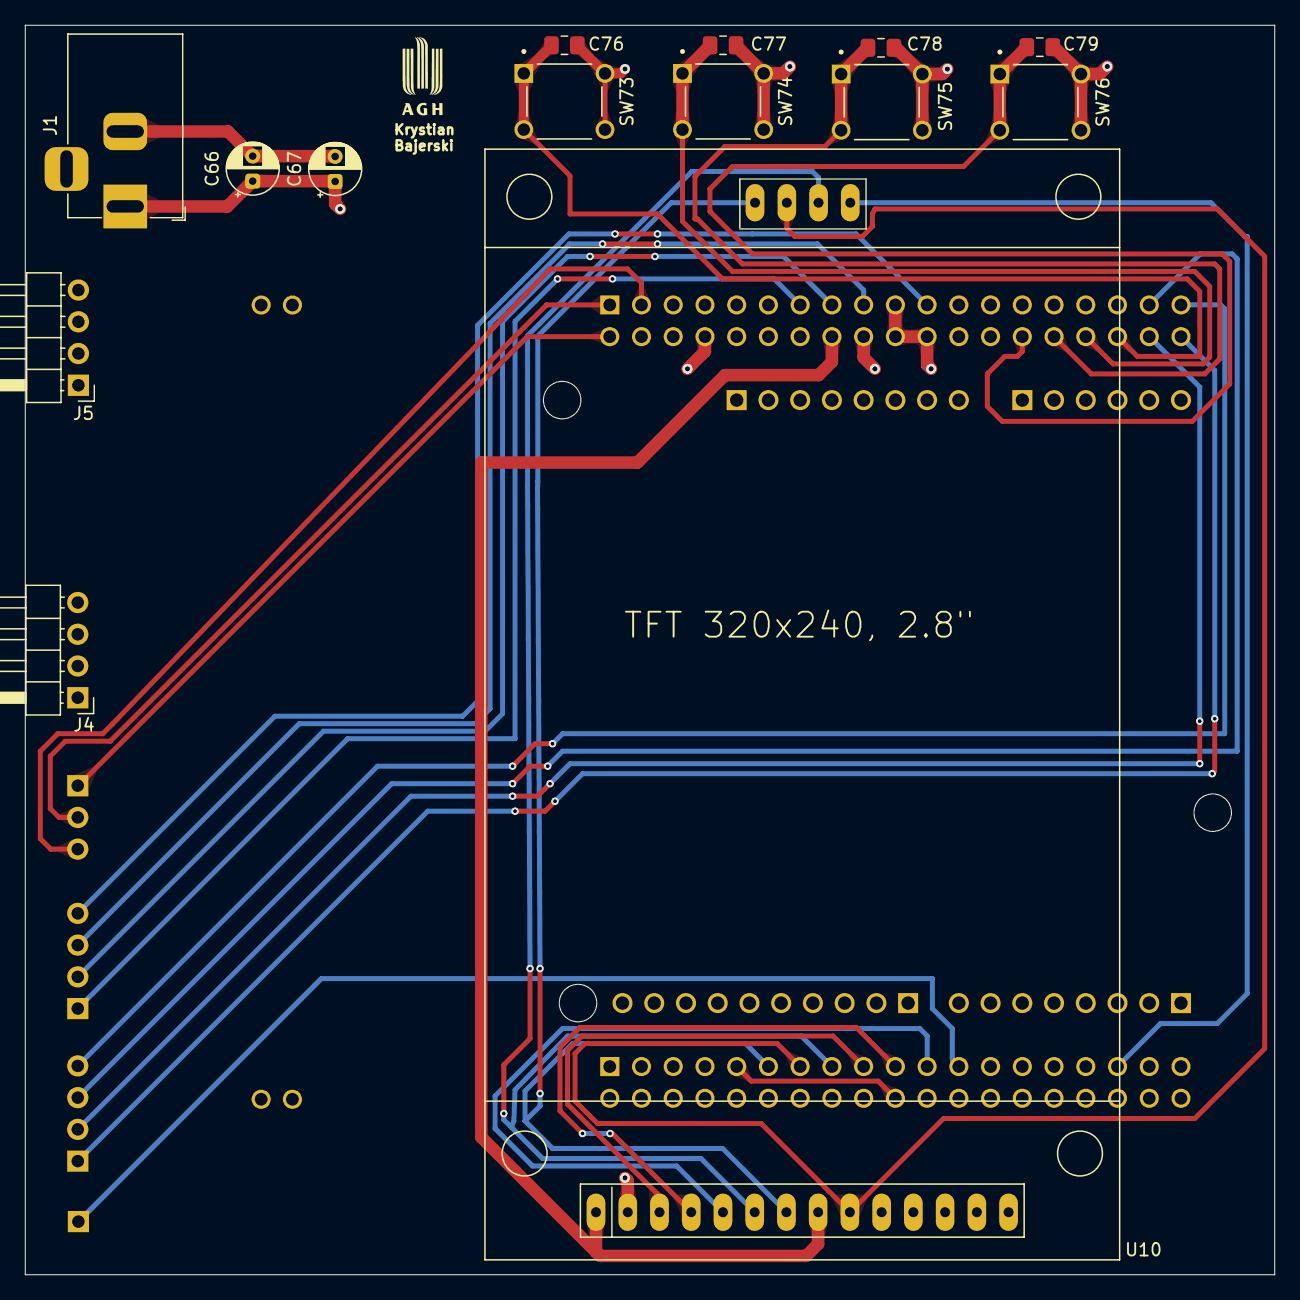
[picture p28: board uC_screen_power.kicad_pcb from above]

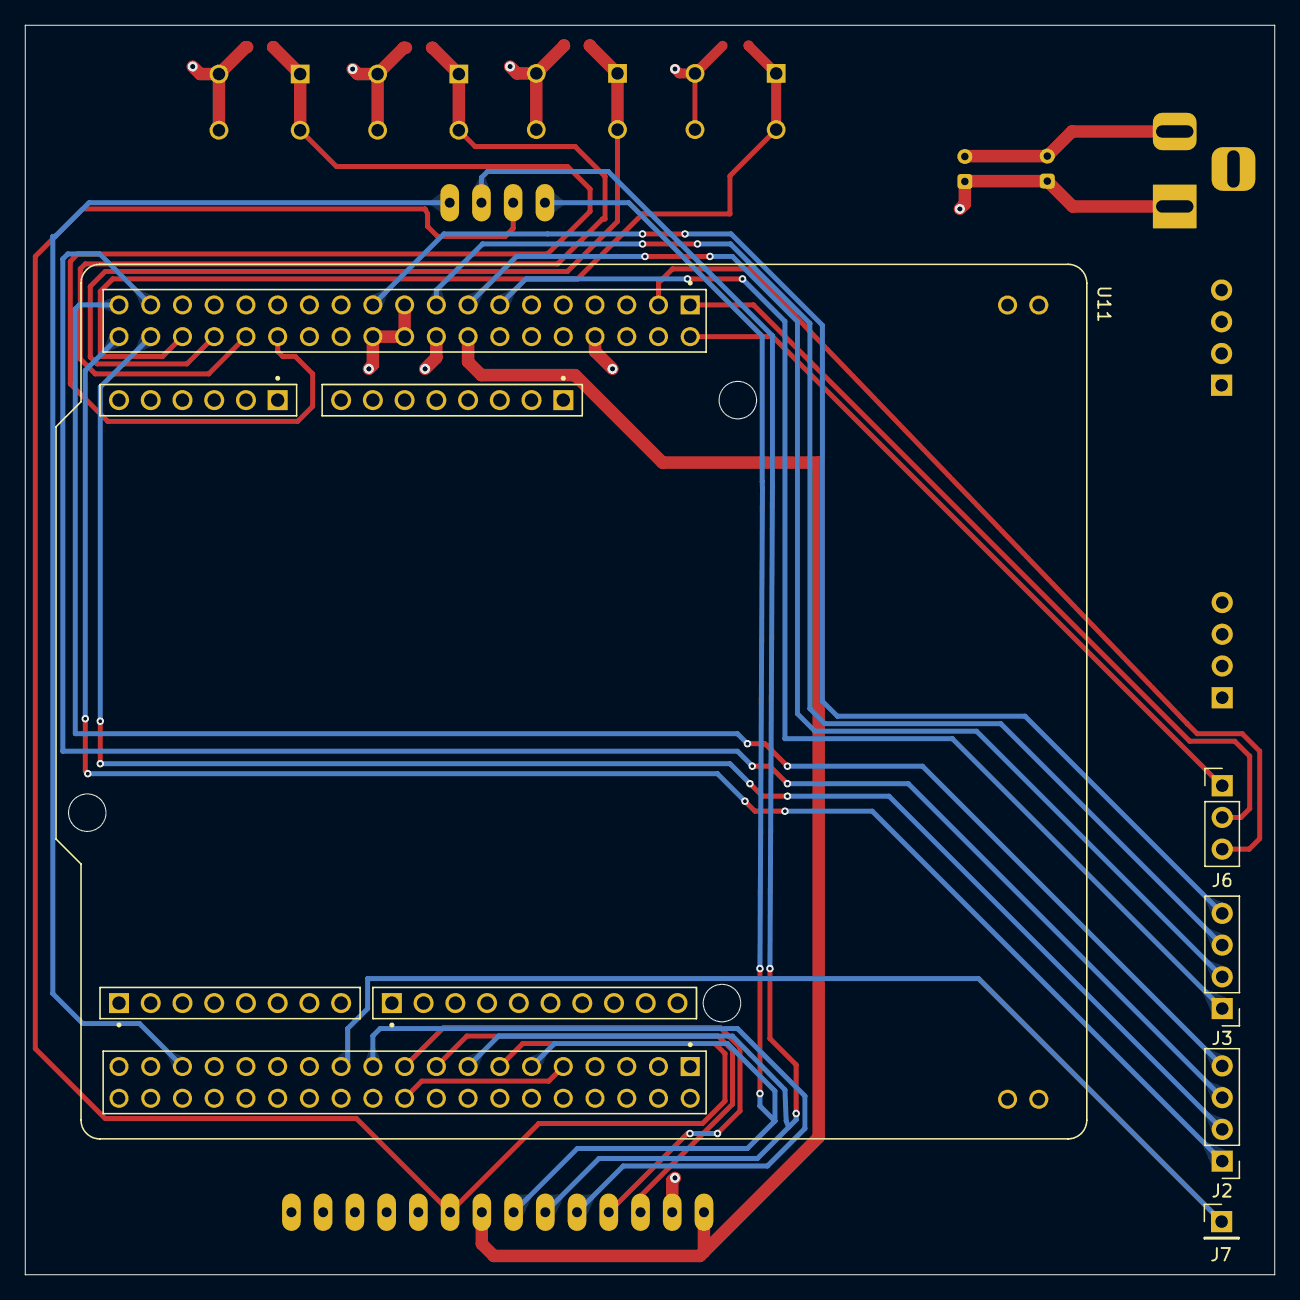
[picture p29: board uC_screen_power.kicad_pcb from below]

Board: 4 copper layers, 100.0 x 100.0 mm, 19 parts (5 on the bottom side), 27 nets.

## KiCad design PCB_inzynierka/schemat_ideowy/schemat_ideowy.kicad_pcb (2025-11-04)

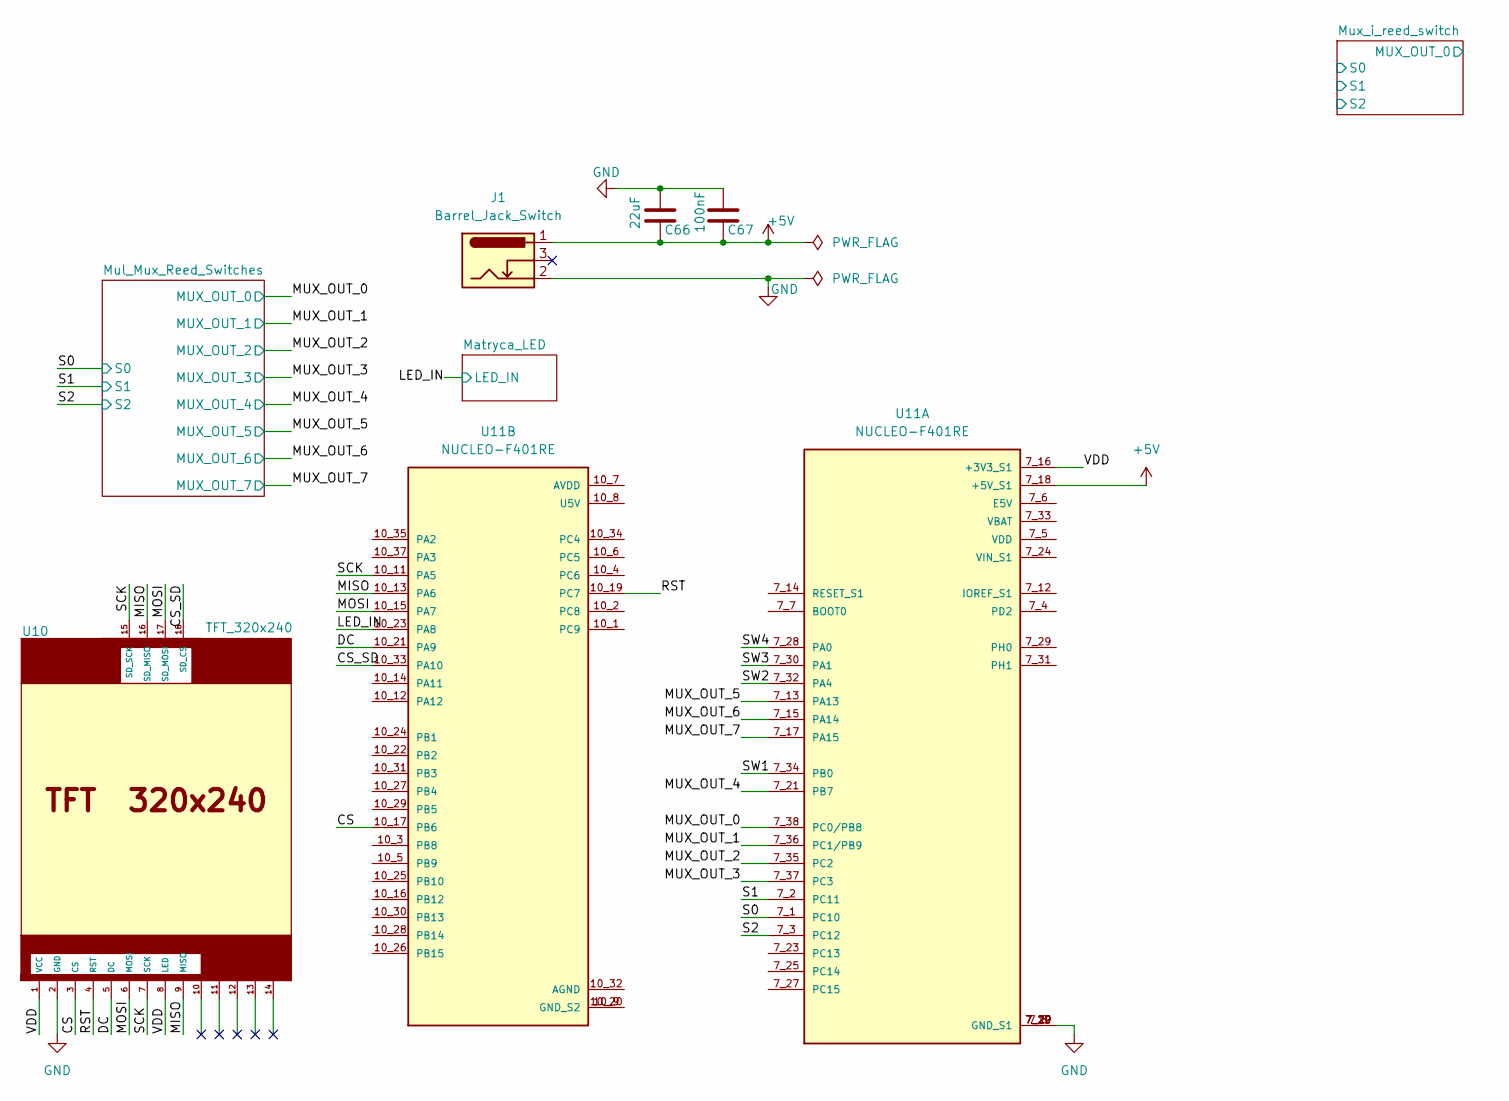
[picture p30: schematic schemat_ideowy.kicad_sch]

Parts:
C66: 22uF; CP_Radial_D4.0mm_P2.00mm
C67: 100nF; CP_Radial_D4.0mm_P2.00mm
J1: Barrel_Jack_Switch; BarrelJack_Horizontal
U10: TFT_320x240; TFT-320x240
U11: NUCLEO-F401RE; ST_NUCLEO-F401RE; PARTREV 13

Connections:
+5V: C66.2, C67.2, J1.1, U11.7_18 (+5V_S1); also elsewhere on the board
/CS: U10.3 (CS), U11.10_17 (PB6)
/CS_SD: U10.18 (SD_CS), U11.10_33 (PA10)
/DC: U10.5 (DC), U11.10_21 (PA9)
/LED_IN: U11.10_23 (PA8); also elsewhere on the board
/MISO: U10.9 (MISO), U10.16 (SD_MISO), U11.10_13 (PA6)
/MOSI: U10.6 (MOSI), U10.17 (SD_MOSI), U11.10_15 (PA7)
/MUX_OUT_0: U11.7_38 (PC0/PB8); also elsewhere on the board
/MUX_OUT_1: U11.7_36 (PC1/PB9); also elsewhere on the board
/MUX_OUT_2: U11.7_35 (PC2); also elsewhere on the board
/MUX_OUT_3: U11.7_37 (PC3); also elsewhere on the board
/MUX_OUT_4: U11.7_21 (PB7); also elsewhere on the board
/MUX_OUT_5: U11.7_13 (PA13); also elsewhere on the board
/MUX_OUT_6: U11.7_15 (PA14); also elsewhere on the board
/MUX_OUT_7: U11.7_17 (PA15); also elsewhere on the board
/RST: U10.4 (RST), U11.10_19 (PC7)
/S0: U11.7_1 (PC10); also elsewhere on the board
/S1: U11.7_2 (PC11); also elsewhere on the board
/S2: U11.7_3 (PC12); also elsewhere on the board
/SCK: U10.7 (SCK), U10.15 (SD_SCK), U11.10_11 (PA5)
/SW1: U11.7_34 (PB0)
/SW2: U11.7_32 (PA4)
/SW3: U11.7_30 (PA1)
/SW4: U11.7_28 (PA0)
/VDD: U10.1 (VCC), U10.8 (LED), U11.7_16 (+3V3_S1)
GND: C66.1, C67.1, J1.2, U10.2 (GND), U11.7_8 (GND_S1), U11.7_19 (GND_S1), U11.7_20 (GND_S1), U11.7_22 (GND_S1); also elsewhere on the board
unnamed: U11.10_9 (GND_S2), U11.10_20 (GND_S2)

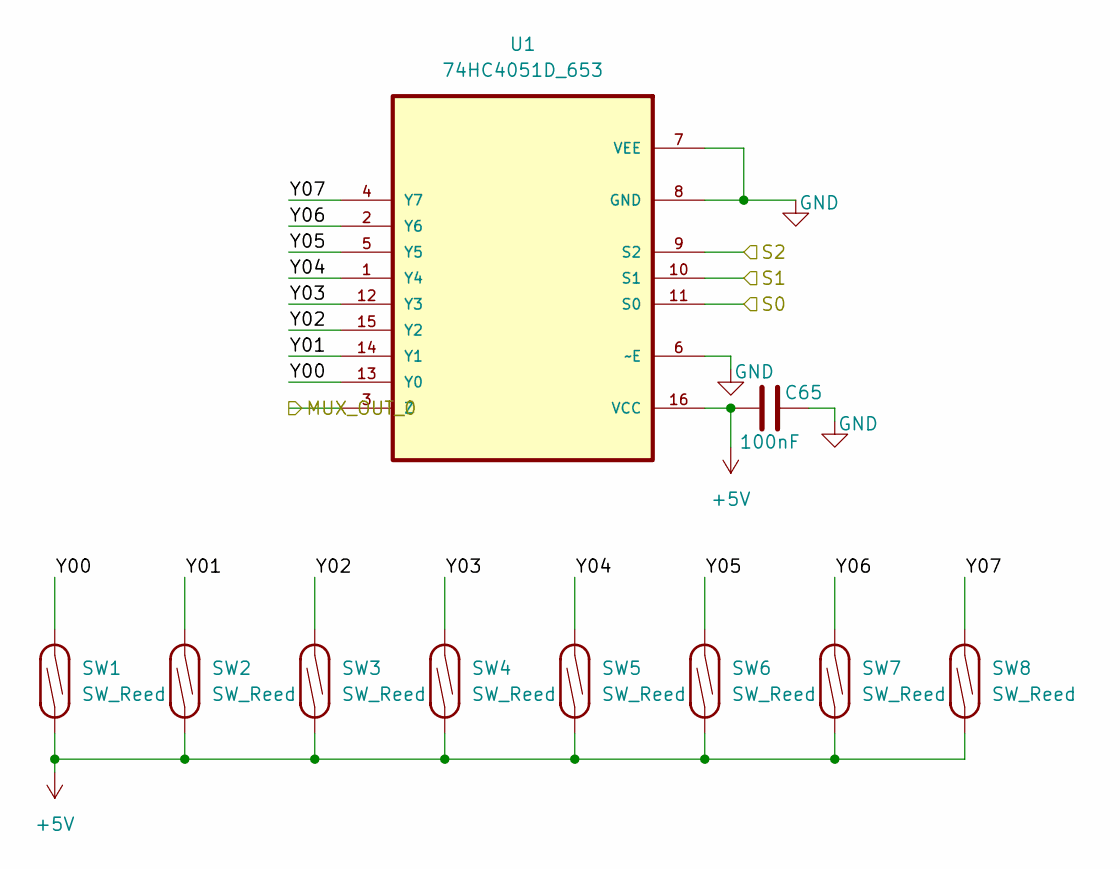
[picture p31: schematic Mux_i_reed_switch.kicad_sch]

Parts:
C65: 100nF; C_0805_2012Metric_Pad1.18x1.45mm_HandSolder
SW1, SW2, SW3, SW4, SW5, SW6, SW7, SW8: SW_Reed; ReedSwitch_2x14mm
U1: 74HC4051D_653; SOIC127P600X175-16N; MPN 74HC4051D,653

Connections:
+5V: C65.1, SW1.2, SW2.2, SW3.2, SW4.2, SW5.2, SW6.2, SW7.2, SW8.2, U1.16 (VCC); also elsewhere on the board
/Mux_i_reed_switch/MUX_OUT_0: U1.3 (Z)
/Mux_i_reed_switch/S0: U1.11 (S0)
/Mux_i_reed_switch/S1: U1.10 (S1)
/Mux_i_reed_switch/S2: U1.9 (S2)
/Mux_i_reed_switch/Y00: SW1.1, U1.13 (Y0)
/Mux_i_reed_switch/Y01: SW2.1, U1.14 (Y1)
/Mux_i_reed_switch/Y02: SW3.1, U1.15 (Y2)
/Mux_i_reed_switch/Y03: SW4.1, U1.12 (Y3)
/Mux_i_reed_switch/Y04: SW5.1, U1.1 (Y4)
/Mux_i_reed_switch/Y05: SW6.1, U1.5 (Y5)
/Mux_i_reed_switch/Y06: SW7.1, U1.2 (Y6)
/Mux_i_reed_switch/Y07: SW8.1, U1.4 (Y7)
GND: C65.2, U1.6 (~E), U1.7 (VEE), U1.8 (GND); also elsewhere on the board

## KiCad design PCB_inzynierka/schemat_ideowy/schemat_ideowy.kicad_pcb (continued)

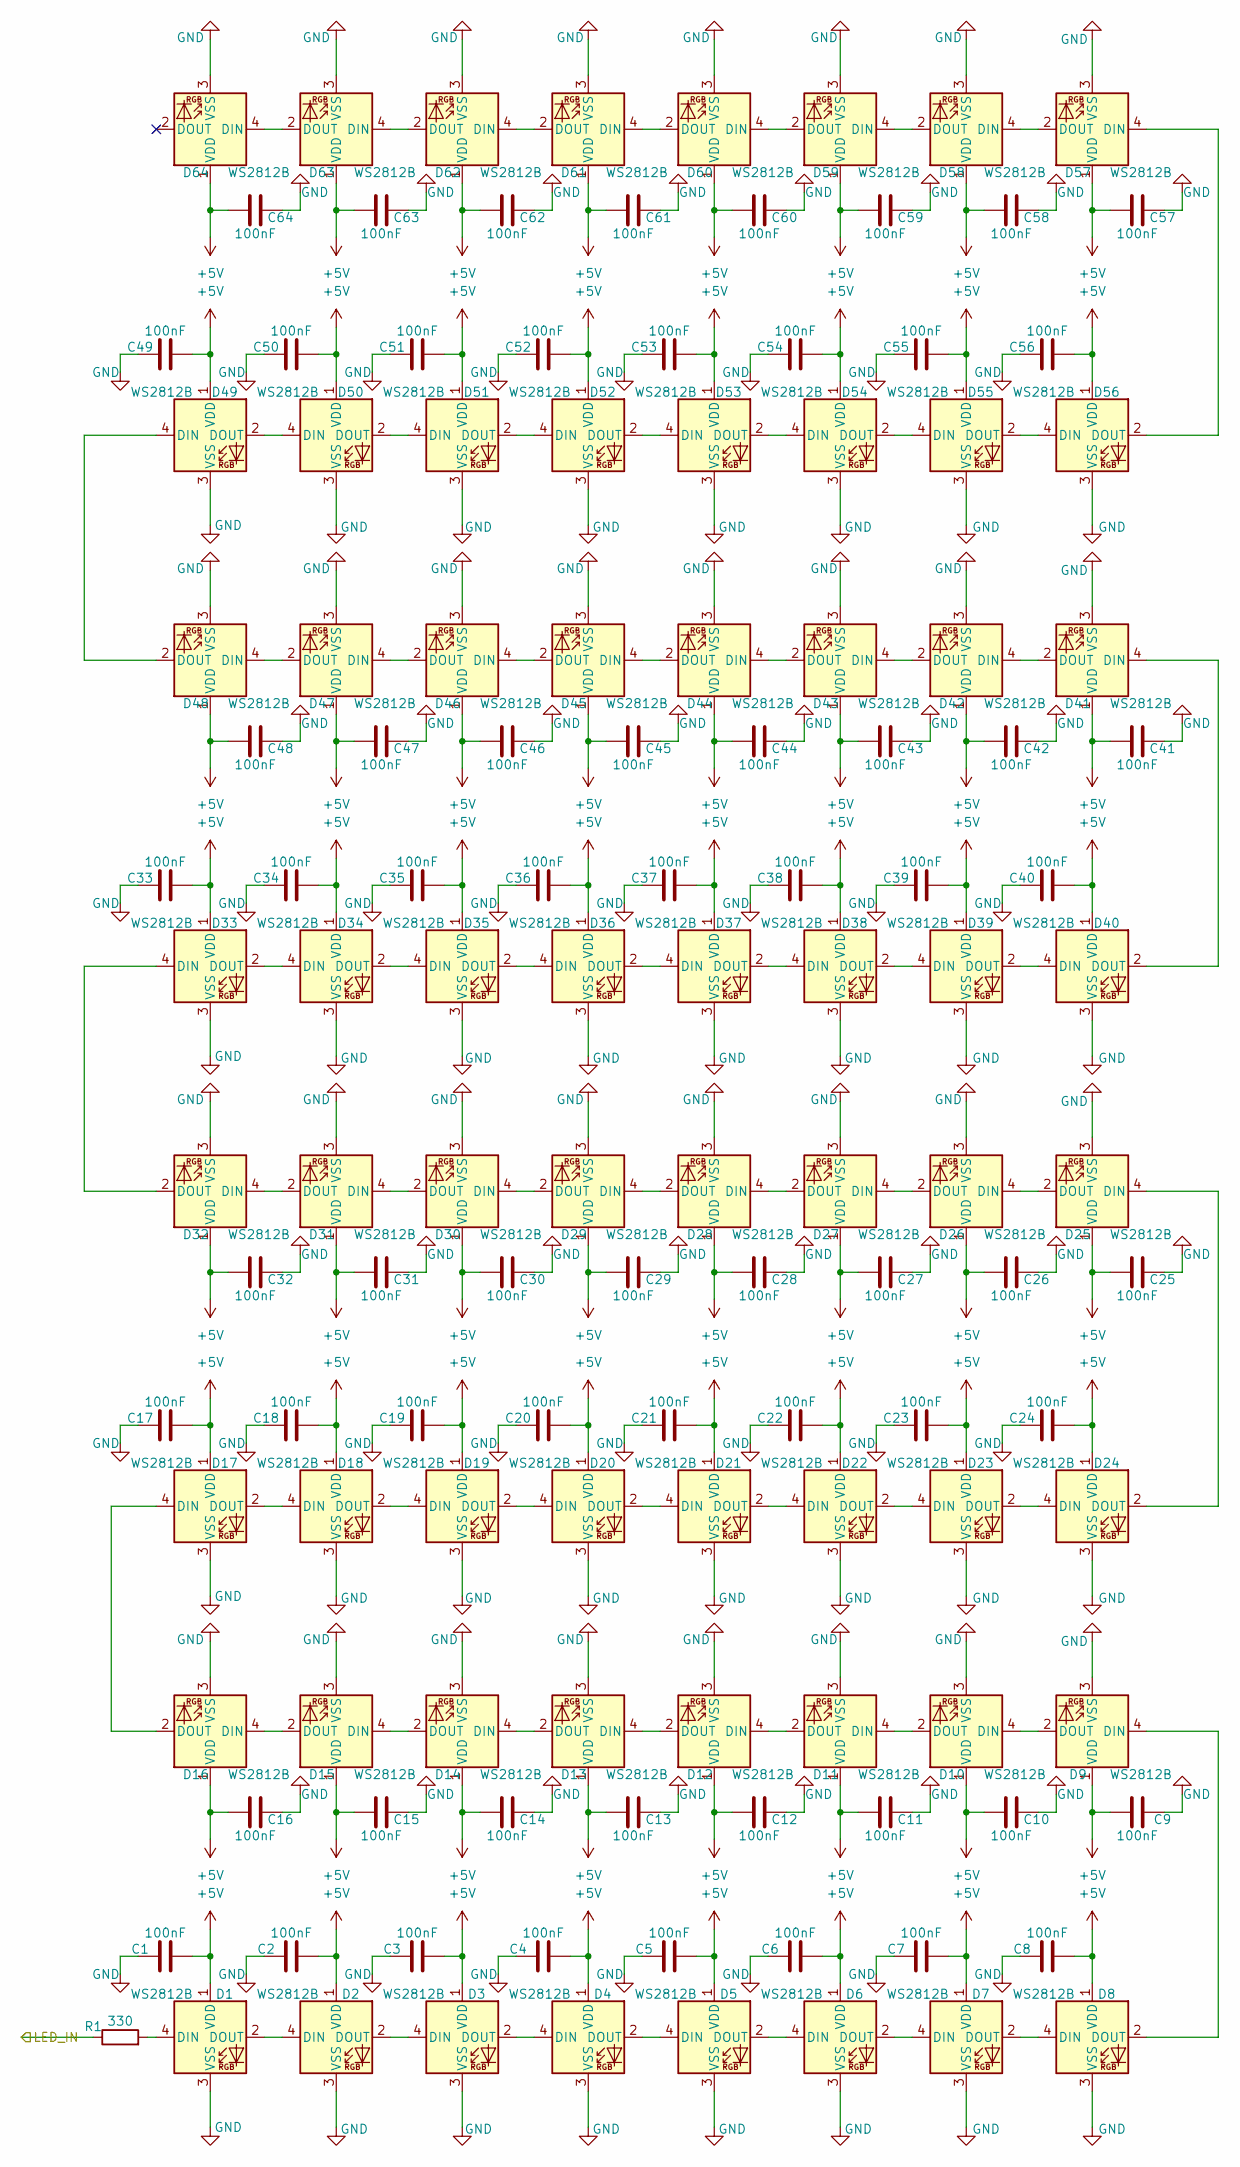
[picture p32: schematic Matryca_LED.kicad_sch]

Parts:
C1, C2, C3, C4, C5, C6, C7, C8, C9, C10, C11, C12, C13, C14, C15, C16, C17, C18, C19, C20, C21, C22, C23, C24, C25, C26, C27, C28, C29, C30, C31, C32, C33, C34, C35, C36, C37, C38, C39, C40, C41, C42, C43, C44, C45, C46, C47, C48, C49, C50, C51, C52, C53, C54, C55, C56, C57, C58, C59, C60, C61, C62, C63, C64: 100nF; C_0805_2012Metric_Pad1.18x1.45mm_HandSolder
D1, D2, D3, D4, D5, D6, D7, D8, D9, D10, D11, D12, D13, D14, D15, D16, D17, D18, D19, D20, D21, D22, D23, D24, D25, D26, D27, D28, D29, D30, D31, D32, D33, D34, D35, D36, D37, D38, D39, D40, D41, D42, D43, D44, D45, D46, D47, D48, D49, D50, D51, D52, D53, D54, D55, D56, D57, D58, D59, D60, D61, D62, D63, D64: WS2812B; LED_WS2812B_PLCC4_5.0x5.0mm_P3.2mm
R1: 330; R_0805_2012Metric_Pad1.20x1.40mm_HandSolder

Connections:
+5V: C1.2, C2.2, C3.2, C4.2, C5.2, C6.2, C7.2, C8.2, C9.2, C10.2, C11.2, C12.2, C13.2, C14.2, C15.2, C16.2, C17.2, C18.2, C19.2, C20.2, C21.2, C22.2, C23.2, C24.2, C25.2, C26.2, C27.2, C28.2, C29.2, C30.2, C31.2, C32.2, C33.2, C34.2, C35.2, C36.2, C37.2, C38.2, C39.2, C40.2, C41.2, C42.2, C43.2, C44.2, C45.2, C46.2, C47.2, C48.2, C49.2, C50.2, C51.2, C52.2, C53.2, C54.2, C55.2, C56.2, C57.2, C58.2, C59.2, C60.2, C61.2, C62.2, C63.2, C64.2, D1.1 (VDD), D2.1 (VDD), D3.1 (VDD), D4.1 (VDD), D5.1 (VDD), D6.1 (VDD), D7.1 (VDD), D8.1 (VDD), D9.1 (VDD), D10.1 (VDD), D11.1 (VDD), D12.1 (VDD), D13.1 (VDD), D14.1 (VDD), D15.1 (VDD), D16.1 (VDD), D17.1 (VDD), D18.1 (VDD), D19.1 (VDD), D20.1 (VDD), D21.1 (VDD), D22.1 (VDD), D23.1 (VDD), D24.1 (VDD), D25.1 (VDD), D26.1 (VDD), D27.1 (VDD), D28.1 (VDD), D29.1 (VDD), D30.1 (VDD), D31.1 (VDD), D32.1 (VDD), D33.1 (VDD), D34.1 (VDD), D35.1 (VDD), D36.1 (VDD), D37.1 (VDD), D38.1 (VDD), D39.1 (VDD), D40.1 (VDD), D41.1 (VDD), D42.1 (VDD), D43.1 (VDD), D44.1 (VDD), D45.1 (VDD), D46.1 (VDD), D47.1 (VDD), D48.1 (VDD), D49.1 (VDD), D50.1 (VDD), D51.1 (VDD), D52.1 (VDD), D53.1 (VDD), D54.1 (VDD), D55.1 (VDD), D56.1 (VDD), D57.1 (VDD), D58.1 (VDD), D59.1 (VDD), D60.1 (VDD), D61.1 (VDD), D62.1 (VDD), D63.1 (VDD), D64.1 (VDD); also elsewhere on the board
/LED_IN: R1.1; also elsewhere on the board
GND: C1.1, C2.1, C3.1, C4.1, C5.1, C6.1, C7.1, C8.1, C9.1, C10.1, C11.1, C12.1, C13.1, C14.1, C15.1, C16.1, C17.1, C18.1, C19.1, C20.1, C21.1, C22.1, C23.1, C24.1, C25.1, C26.1, C27.1, C28.1, C29.1, C30.1, C31.1, C32.1, C33.1, C34.1, C35.1, C36.1, C37.1, C38.1, C39.1, C40.1, C41.1, C42.1, C43.1, C44.1, C45.1, C46.1, C47.1, C48.1, C49.1, C50.1, C51.1, C52.1, C53.1, C54.1, C55.1, C56.1, C57.1, C58.1, C59.1, C60.1, C61.1, C62.1, C63.1, C64.1, D1.3 (VSS), D2.3 (VSS), D3.3 (VSS), D4.3 (VSS), D5.3 (VSS), D6.3 (VSS), D7.3 (VSS), D8.3 (VSS), D9.3 (VSS), D10.3 (VSS), D11.3 (VSS), D12.3 (VSS), D13.3 (VSS), D14.3 (VSS), D15.3 (VSS), D16.3 (VSS), D17.3 (VSS), D18.3 (VSS), D19.3 (VSS), D20.3 (VSS), D21.3 (VSS), D22.3 (VSS), D23.3 (VSS), D24.3 (VSS), D25.3 (VSS), D26.3 (VSS), D27.3 (VSS), D28.3 (VSS), D29.3 (VSS), D30.3 (VSS), D31.3 (VSS), D32.3 (VSS), D33.3 (VSS), D34.3 (VSS), D35.3 (VSS), D36.3 (VSS), D37.3 (VSS), D38.3 (VSS), D39.3 (VSS), D40.3 (VSS), D41.3 (VSS), D42.3 (VSS), D43.3 (VSS), D44.3 (VSS), D45.3 (VSS), D46.3 (VSS), D47.3 (VSS), D48.3 (VSS), D49.3 (VSS), D50.3 (VSS), D51.3 (VSS), D52.3 (VSS), D53.3 (VSS), D54.3 (VSS), D55.3 (VSS), D56.3 (VSS), D57.3 (VSS), D58.3 (VSS), D59.3 (VSS), D60.3 (VSS), D61.3 (VSS), D62.3 (VSS), D63.3 (VSS), D64.3 (VSS); also elsewhere on the board
unnamed: D1.4 (DIN), R1.2
unnamed: D1.2 (DOUT), D2.4 (DIN)
unnamed: D2.2 (DOUT), D3.4 (DIN)
unnamed: D3.2 (DOUT), D4.4 (DIN)
unnamed: D4.2 (DOUT), D5.4 (DIN)
unnamed: D5.2 (DOUT), D6.4 (DIN)
unnamed: D6.2 (DOUT), D7.4 (DIN)
unnamed: D7.2 (DOUT), D8.4 (DIN)
unnamed: D8.2 (DOUT), D9.4 (DIN)
unnamed: D9.2 (DOUT), D10.4 (DIN)
unnamed: D10.2 (DOUT), D11.4 (DIN)
unnamed: D11.2 (DOUT), D12.4 (DIN)
unnamed: D12.2 (DOUT), D13.4 (DIN)
unnamed: D13.2 (DOUT), D14.4 (DIN)
unnamed: D14.2 (DOUT), D15.4 (DIN)
unnamed: D15.2 (DOUT), D16.4 (DIN)
unnamed: D16.2 (DOUT), D17.4 (DIN)
unnamed: D17.2 (DOUT), D18.4 (DIN)
unnamed: D18.2 (DOUT), D19.4 (DIN)
unnamed: D19.2 (DOUT), D20.4 (DIN)
unnamed: D20.2 (DOUT), D21.4 (DIN)
unnamed: D21.2 (DOUT), D22.4 (DIN)
unnamed: D22.2 (DOUT), D23.4 (DIN)
unnamed: D23.2 (DOUT), D24.4 (DIN)
unnamed: D24.2 (DOUT), D25.4 (DIN)
unnamed: D25.2 (DOUT), D26.4 (DIN)
unnamed: D26.2 (DOUT), D27.4 (DIN)
unnamed: D27.2 (DOUT), D28.4 (DIN)
unnamed: D28.2 (DOUT), D29.4 (DIN)
unnamed: D29.2 (DOUT), D30.4 (DIN)
unnamed: D30.2 (DOUT), D31.4 (DIN)
unnamed: D31.2 (DOUT), D32.4 (DIN)
unnamed: D32.2 (DOUT), D33.4 (DIN)
unnamed: D33.2 (DOUT), D34.4 (DIN)
unnamed: D34.2 (DOUT), D35.4 (DIN)
unnamed: D35.2 (DOUT), D36.4 (DIN)
unnamed: D36.2 (DOUT), D37.4 (DIN)
unnamed: D37.2 (DOUT), D38.4 (DIN)
unnamed: D38.2 (DOUT), D39.4 (DIN)
unnamed: D39.2 (DOUT), D40.4 (DIN)
unnamed: D40.2 (DOUT), D41.4 (DIN)
unnamed: D41.2 (DOUT), D42.4 (DIN)
unnamed: D42.2 (DOUT), D43.4 (DIN)
unnamed: D43.2 (DOUT), D44.4 (DIN)
unnamed: D44.2 (DOUT), D45.4 (DIN)
unnamed: D45.2 (DOUT), D46.4 (DIN)
unnamed: D46.2 (DOUT), D47.4 (DIN)
unnamed: D47.2 (DOUT), D48.4 (DIN)
unnamed: D48.2 (DOUT), D49.4 (DIN)
unnamed: D49.2 (DOUT), D50.4 (DIN)
unnamed: D50.2 (DOUT), D51.4 (DIN)
unnamed: D51.2 (DOUT), D52.4 (DIN)
unnamed: D52.2 (DOUT), D53.4 (DIN)
unnamed: D53.2 (DOUT), D54.4 (DIN)
unnamed: D54.2 (DOUT), D55.4 (DIN)
unnamed: D55.2 (DOUT), D56.4 (DIN)
unnamed: D56.2 (DOUT), D57.4 (DIN)
unnamed: D57.2 (DOUT), D58.4 (DIN)
unnamed: D58.2 (DOUT), D59.4 (DIN)
unnamed: D59.2 (DOUT), D60.4 (DIN)
unnamed: D60.2 (DOUT), D61.4 (DIN)
unnamed: D61.2 (DOUT), D62.4 (DIN)
unnamed: D62.2 (DOUT), D63.4 (DIN)
unnamed: D63.2 (DOUT), D64.4 (DIN)

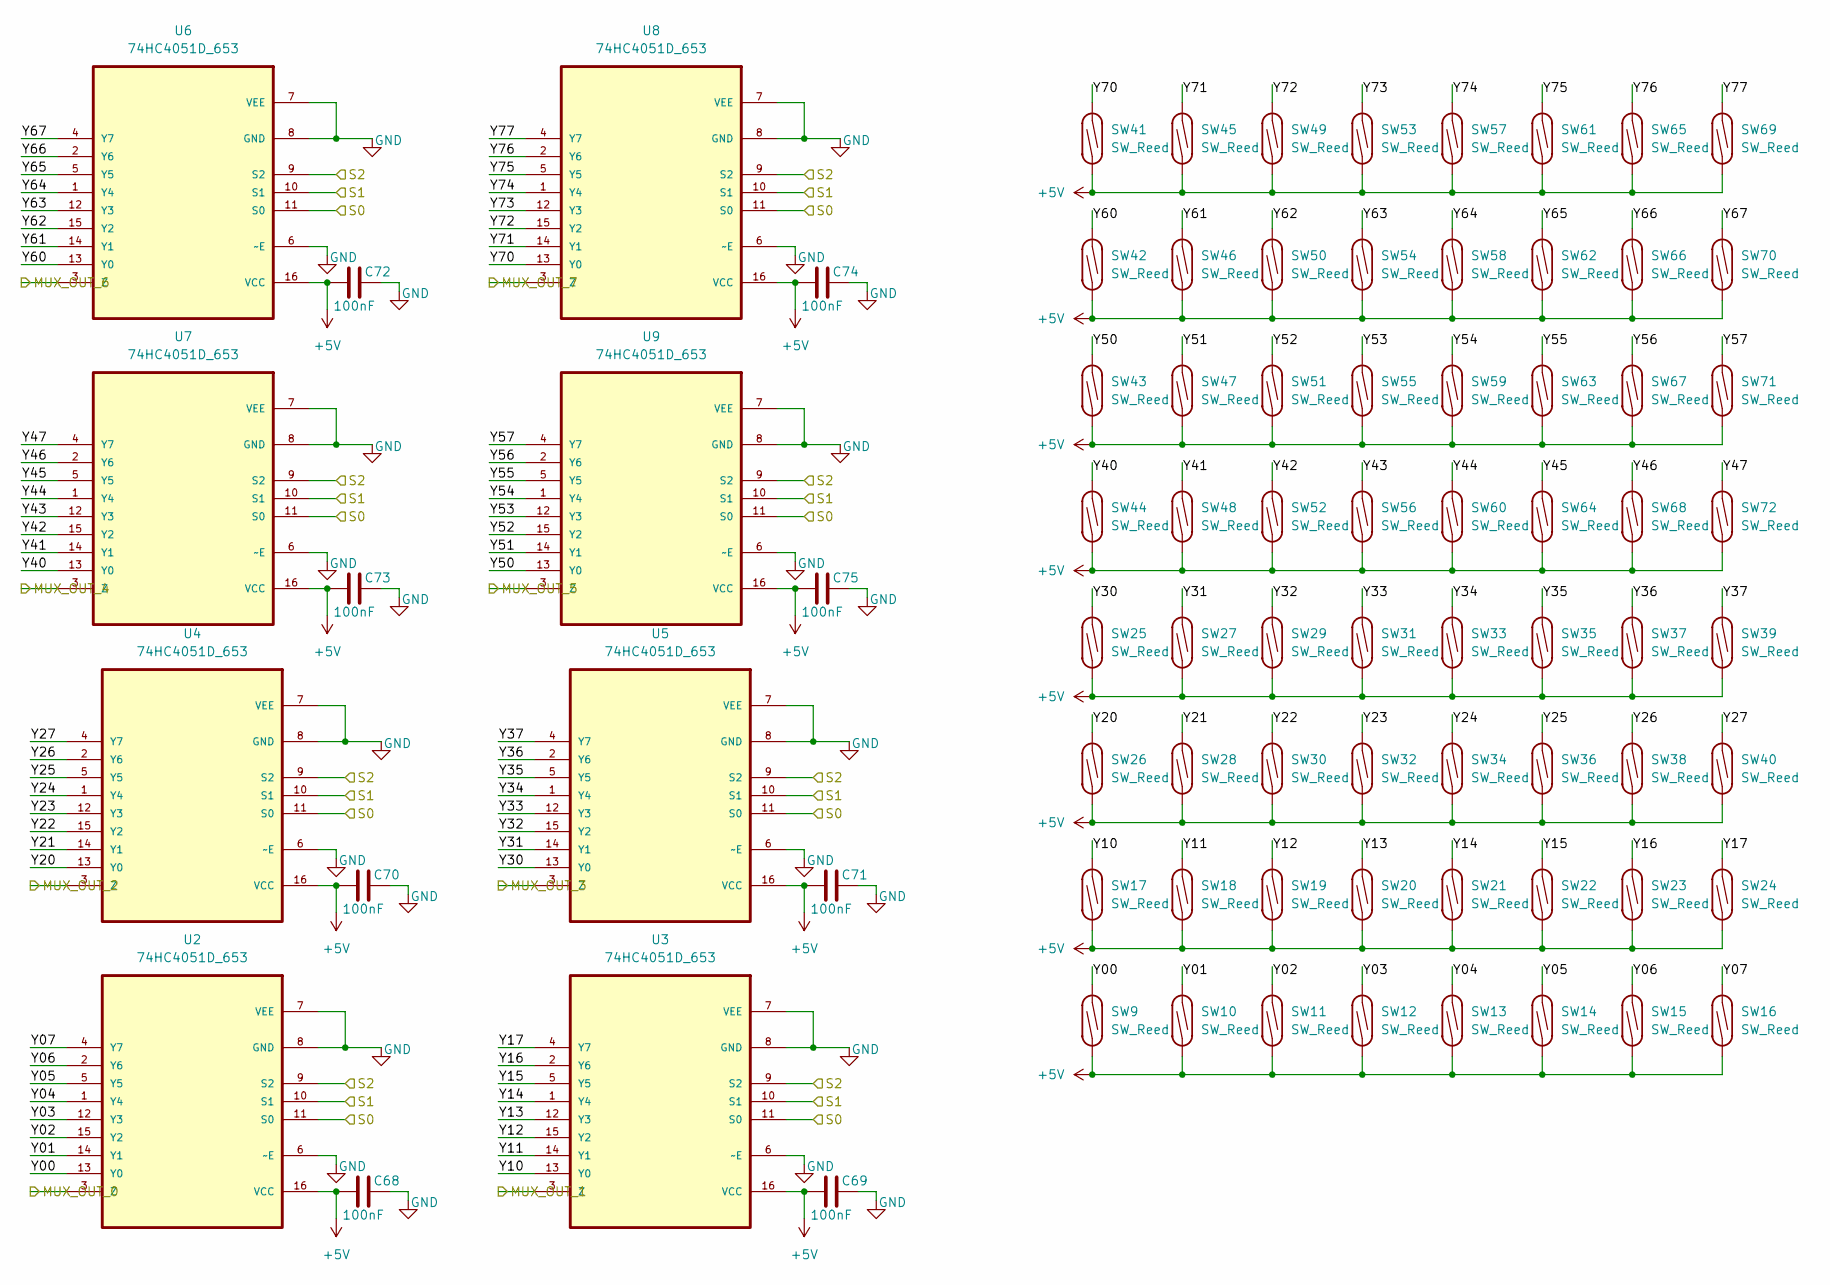
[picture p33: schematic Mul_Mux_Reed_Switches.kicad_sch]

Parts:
C68, C69, C70, C71, C72, C73, C74, C75: 100nF; C_0805_2012Metric_Pad1.18x1.45mm_HandSolder
SW9, SW10, SW11, SW12, SW13, SW14, SW15, SW16, SW17, SW18, SW19, SW20, SW21, SW22, SW23, SW24, SW25, SW26, SW27, SW28, SW29, SW30, SW31, SW32, SW33, SW34, SW35, SW36, SW37, SW38, SW39, SW40, SW41, SW42, SW43, SW44, SW45, SW46, SW47, SW48, SW49, SW50, SW51, SW52, SW53, SW54, SW55, SW56, SW57, SW58, SW59, SW60, SW61, SW62, SW63, SW64, SW65, SW66, SW67, SW68, SW69, SW70, SW71, SW72: SW_Reed; ReedSwitch_2x14mm
U2, U3, U4, U5, U6, U7, U8, U9: 74HC4051D_653; SOIC127P600X175-16N; MPN 74HC4051D,653

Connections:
+5V: C68.1, C69.1, C70.1, C71.1, C72.1, C73.1, C74.1, C75.1, SW9.2, SW10.2, SW11.2, SW12.2, SW13.2, SW14.2, SW15.2, SW16.2, SW17.2, SW18.2, SW19.2, SW20.2, SW21.2, SW22.2, SW23.2, SW24.2, SW25.2, SW26.2, SW27.2, SW28.2, SW29.2, SW30.2, SW31.2, SW32.2, SW33.2, SW34.2, SW35.2, SW36.2, SW37.2, SW38.2, SW39.2, SW40.2, SW41.2, SW42.2, SW43.2, SW44.2, SW45.2, SW46.2, SW47.2, SW48.2, SW49.2, SW50.2, SW51.2, SW52.2, SW53.2, SW54.2, SW55.2, SW56.2, SW57.2, SW58.2, SW59.2, SW60.2, SW61.2, SW62.2, SW63.2, SW64.2, SW65.2, SW66.2, SW67.2, SW68.2, SW69.2, SW70.2, SW71.2, SW72.2, U2.16 (VCC), U3.16 (VCC), U4.16 (VCC), U5.16 (VCC), U6.16 (VCC), U7.16 (VCC), U8.16 (VCC), U9.16 (VCC); also elsewhere on the board
/MUX_OUT_0: U2.3 (Z); also elsewhere on the board
/MUX_OUT_1: U3.3 (Z); also elsewhere on the board
/MUX_OUT_2: U4.3 (Z); also elsewhere on the board
/MUX_OUT_3: U5.3 (Z); also elsewhere on the board
/MUX_OUT_4: U7.3 (Z); also elsewhere on the board
/MUX_OUT_5: U9.3 (Z); also elsewhere on the board
/MUX_OUT_6: U6.3 (Z); also elsewhere on the board
/MUX_OUT_7: U8.3 (Z); also elsewhere on the board
/Mul_Mux_Reed_Switches/Y00: SW9.1, U2.13 (Y0)
/Mul_Mux_Reed_Switches/Y01: SW10.1, U2.14 (Y1)
/Mul_Mux_Reed_Switches/Y02: SW11.1, U2.15 (Y2)
/Mul_Mux_Reed_Switches/Y03: SW12.1, U2.12 (Y3)
/Mul_Mux_Reed_Switches/Y04: SW13.1, U2.1 (Y4)
/Mul_Mux_Reed_Switches/Y05: SW14.1, U2.5 (Y5)
/Mul_Mux_Reed_Switches/Y06: SW15.1, U2.2 (Y6)
/Mul_Mux_Reed_Switches/Y07: SW16.1, U2.4 (Y7)
/Mul_Mux_Reed_Switches/Y10: SW17.1, U3.13 (Y0)
/Mul_Mux_Reed_Switches/Y11: SW18.1, U3.14 (Y1)
/Mul_Mux_Reed_Switches/Y12: SW19.1, U3.15 (Y2)
/Mul_Mux_Reed_Switches/Y13: SW20.1, U3.12 (Y3)
/Mul_Mux_Reed_Switches/Y14: SW21.1, U3.1 (Y4)
/Mul_Mux_Reed_Switches/Y15: SW22.1, U3.5 (Y5)
/Mul_Mux_Reed_Switches/Y16: SW23.1, U3.2 (Y6)
/Mul_Mux_Reed_Switches/Y17: SW24.1, U3.4 (Y7)
/Mul_Mux_Reed_Switches/Y20: SW26.1, U4.13 (Y0)
/Mul_Mux_Reed_Switches/Y21: SW28.1, U4.14 (Y1)
/Mul_Mux_Reed_Switches/Y22: SW30.1, U4.15 (Y2)
/Mul_Mux_Reed_Switches/Y23: SW32.1, U4.12 (Y3)
/Mul_Mux_Reed_Switches/Y24: SW34.1, U4.1 (Y4)
/Mul_Mux_Reed_Switches/Y25: SW36.1, U4.5 (Y5)
/Mul_Mux_Reed_Switches/Y26: SW38.1, U4.2 (Y6)
/Mul_Mux_Reed_Switches/Y27: SW40.1, U4.4 (Y7)
/Mul_Mux_Reed_Switches/Y30: SW25.1, U5.13 (Y0)
/Mul_Mux_Reed_Switches/Y31: SW27.1, U5.14 (Y1)
/Mul_Mux_Reed_Switches/Y32: SW29.1, U5.15 (Y2)
/Mul_Mux_Reed_Switches/Y33: SW31.1, U5.12 (Y3)
/Mul_Mux_Reed_Switches/Y34: SW33.1, U5.1 (Y4)
/Mul_Mux_Reed_Switches/Y35: SW35.1, U5.5 (Y5)
/Mul_Mux_Reed_Switches/Y36: SW37.1, U5.2 (Y6)
/Mul_Mux_Reed_Switches/Y37: SW39.1, U5.4 (Y7)
/Mul_Mux_Reed_Switches/Y40: SW44.1, U7.13 (Y0)
/Mul_Mux_Reed_Switches/Y41: SW48.1, U7.14 (Y1)
/Mul_Mux_Reed_Switches/Y42: SW52.1, U7.15 (Y2)
/Mul_Mux_Reed_Switches/Y43: SW56.1, U7.12 (Y3)
/Mul_Mux_Reed_Switches/Y44: SW60.1, U7.1 (Y4)
/Mul_Mux_Reed_Switches/Y45: SW64.1, U7.5 (Y5)
/Mul_Mux_Reed_Switches/Y46: SW68.1, U7.2 (Y6)
/Mul_Mux_Reed_Switches/Y47: SW72.1, U7.4 (Y7)
/Mul_Mux_Reed_Switches/Y50: SW43.1, U9.13 (Y0)
/Mul_Mux_Reed_Switches/Y51: SW47.1, U9.14 (Y1)
/Mul_Mux_Reed_Switches/Y52: SW51.1, U9.15 (Y2)
/Mul_Mux_Reed_Switches/Y53: SW55.1, U9.12 (Y3)
/Mul_Mux_Reed_Switches/Y54: SW59.1, U9.1 (Y4)
/Mul_Mux_Reed_Switches/Y55: SW63.1, U9.5 (Y5)
/Mul_Mux_Reed_Switches/Y56: SW67.1, U9.2 (Y6)
/Mul_Mux_Reed_Switches/Y57: SW71.1, U9.4 (Y7)
/Mul_Mux_Reed_Switches/Y60: SW42.1, U6.13 (Y0)
/Mul_Mux_Reed_Switches/Y61: SW46.1, U6.14 (Y1)
/Mul_Mux_Reed_Switches/Y62: SW50.1, U6.15 (Y2)
/Mul_Mux_Reed_Switches/Y63: SW54.1, U6.12 (Y3)
/Mul_Mux_Reed_Switches/Y64: SW58.1, U6.1 (Y4)
/Mul_Mux_Reed_Switches/Y65: SW62.1, U6.5 (Y5)
/Mul_Mux_Reed_Switches/Y66: SW66.1, U6.2 (Y6)
/Mul_Mux_Reed_Switches/Y67: SW70.1, U6.4 (Y7)
/Mul_Mux_Reed_Switches/Y70: SW41.1, U8.13 (Y0)
/Mul_Mux_Reed_Switches/Y71: SW45.1, U8.14 (Y1)
/Mul_Mux_Reed_Switches/Y72: SW49.1, U8.15 (Y2)
/Mul_Mux_Reed_Switches/Y73: SW53.1, U8.12 (Y3)
/Mul_Mux_Reed_Switches/Y74: SW57.1, U8.1 (Y4)
/Mul_Mux_Reed_Switches/Y75: SW61.1, U8.5 (Y5)
/Mul_Mux_Reed_Switches/Y76: SW65.1, U8.2 (Y6)
/Mul_Mux_Reed_Switches/Y77: SW69.1, U8.4 (Y7)
/S0: U2.11 (S0), U3.11 (S0), U4.11 (S0), U5.11 (S0), U6.11 (S0), U7.11 (S0), U8.11 (S0), U9.11 (S0); also elsewhere on the board
/S1: U2.10 (S1), U3.10 (S1), U4.10 (S1), U5.10 (S1), U6.10 (S1), U7.10 (S1), U8.10 (S1), U9.10 (S1); also elsewhere on the board
/S2: U2.9 (S2), U3.9 (S2), U4.9 (S2), U5.9 (S2), U6.9 (S2), U7.9 (S2), U8.9 (S2), U9.9 (S2); also elsewhere on the board
GND: C68.2, C69.2, C70.2, C71.2, C72.2, C73.2, C74.2, C75.2, U2.6 (~E), U2.7 (VEE), U2.8 (GND), U3.6 (~E), U3.7 (VEE), U3.8 (GND), U4.6 (~E), U4.7 (VEE), U4.8 (GND), U5.6 (~E), U5.7 (VEE), U5.8 (GND), U6.6 (~E), U6.7 (VEE), U6.8 (GND), U7.6 (~E), U7.7 (VEE), U7.8 (GND), U8.6 (~E), U8.7 (VEE), U8.8 (GND), U9.6 (~E), U9.7 (VEE), U9.8 (GND); also elsewhere on the board

Board: 2 copper layers, 224 parts (0 on the bottom side), 159 nets, no tracks yet.

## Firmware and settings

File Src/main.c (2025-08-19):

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
/* Includes ------------------------------------------------------------------*/
#include "main.h"
#include "dma.h"
#include "spi.h"
#include "tim.h"
#include "usart.h"
#include "gpio.h"

/* USER CODE BEGIN Includes */
#include "math.h"

/* USER CODE END Includes */


void SystemClock_Config(void);
/* USER CODE BEGIN 0 */

#define MAX_LED 64
#define USE_BRIGHTNESS 1

uint8_t LED_Data[MAX_LED][4];
uint8_t LED_Mod[MAX_LED][4]; // jasność

int datasentflag=0;

void HAL_TIM_PWM_PulseFinishedCallback(TIM_HandleTypeDef *htim)
{
	HAL_TIM_PWM_Stop_DMA(&htim1, TIM_CHANNEL_1);
	datasentflag=1;
}

void Set_LED (int LEDnum, int Red, int Green, int Blue)
{
	LED_Data[LEDnum][0] = LEDnum;
	LED_Data[LEDnum][1] = Green;
	LED_Data[LEDnum][2] = Red;
	LED_Data[LEDnum][3] = Blue;
}

#define PI 3.14159265

void Set_Brightness (int brightness)  // 0-45
{
#if USE_BRIGHTNESS

	if (brightness > 45) brightness = 45;
	for (int i=0; i<MAX_LED; i++)
	{
		LED_Mod[i][0] = LED_Data[i][0];
		for (int j=1; j<4; j++)
		{
			float angle = 90-brightness;  // in degrees
			angle = angle*PI / 180;  // in rad
			LED_Mod[i][j] = (LED_Data[i][j])/(tan(angle));
		}
	}

#endif

}

uint16_t pwmData[(24*MAX_LED)+50];

void WS2812_Send (void)
{
	uint32_t indx=0;
	uint32_t color;


	for (int i= 0; i<MAX_LED; i++)
	{
#if USE_BRIGHTNESS
		color = ((LED_Mod[i][1]<<16) | (LED_Mod[i][2]<<8) | (LED_Mod[i][3]));
#else
		color = ((LED_Data[i][1]<<16) | (LED_Data[i][2]<<8) | (LED_Data[i][3]));
#endif

		for (int i=23; i>=0; i--)
		{
			if (color&(1<<i))
			{
				pwmData[indx] = 60;  // 2/3 of 90
			}

			else pwmData[indx] = 30;  // 1/3 of 90

			indx++;
		}

	}

	for (int i=0; i<50; i++)
	{
		pwmData[indx] = 0;
		indx++;
	}

	HAL_TIM_PWM_Start_DMA(&htim1, TIM_CHANNEL_1, (uint32_t *)pwmData, indx);
	while (!datasentflag){};
	datasentflag = 0;
}



void send(int Green, int Red, int Blue)
{
    uint32_t data = (Green<<16) | (Red<<8) | Blue;
    uint32_t idx = 0;

    // Wypełniamy pwmData[0..23]
    for(int bit = 23; bit >= 0; bit--) {
        pwmData[idx++] = (data & (1UL<<bit)) ? 60 : 30;
    }

    // Dodajemy 25-ty element = 0, żeby DMA wygasiło PWM
    pwmData[idx++] = 0;

    // Uruchamiamy DMA na wszystkich 25 półsłów
    HAL_TIM_PWM_Start_DMA(&htim1, TIM_CHANNEL_1, (uint32_t *)pwmData, idx);
}

static void ClearAllLEDs(void)
{
    for (int i = 0; i < MAX_LED; i++)
        Set_LED(i, 0, 0, 0);
}



/* USER CODE END 0 */

/**
  * @brief  The application entry point.
  * @retval int
  */
int main(void)
{
  HAL_Init();

  SystemClock_Config();
  MX_GPIO_Init();
  MX_DMA_Init();
  MX_TIM1_Init();
	  // zapal białą „0”
	     /*ClearAllLEDs();
	     Set_LED(0, 255,255,255);
	     WS2812_Send();
	     HAL_Delay(500);

	     // ——————————————
	     // zgaś „0”
	     ClearAllLEDs();  // już nic nie musisz ustawiać, bo są czarne
	     WS2812_Send();
	     HAL_Delay(500);

	     // ——————————————
	     // zapal „3” na magentę
	     ClearAllLEDs();
	     Set_LED(3, 255,0,255);
	     WS2812_Send();
	     HAL_Delay(500);

	     // ——————————————
	     // zgaś „3”
	     ClearAllLEDs();
	     WS2812_Send();
	     HAL_Delay(500);*/
	  Set_LED(0, 255, 0, 0);
	    Set_LED(1, 0, 255, 0);
	    Set_LED(2, 0, 0, 255);

	    Set_LED(3, 46, 89, 128);

	    Set_LED(4, 156, 233, 100);
	    Set_LED(5, 102, 0, 235);
	    Set_LED(6, 47, 38, 77);

	    Set_LED(7, 255, 200, 0);
	    Set_LED(8, 132, 11, 234);
	    Set_LED(63, 30, 95, 79);

	    while (1)
	    {

	  	  for (int i=0; i<46; i++)
	  	  {
	  		  Set_Brightness(i);
	  		  WS2812_Send();
	  		  HAL_Delay (50);
	  	  }

	  	  for (int i=45; i>=0; i--)
	  	  {
	  		  Set_Brightness(i);
	  		  WS2812_Send();
	  		  HAL_Delay (50);
	  	  }
	    }

}

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


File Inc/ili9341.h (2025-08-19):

/*
 * ili9341.h
 *
 *  Created on: Apr 30, 2025
 *      Author: javis
 */

/* vim: set ai et ts=4 sw=4: */
#ifndef __ILI9341_H__
#define __ILI9341_H__

#include "fonts.h"
#include <stdbool.h>

#define ILI9341_MADCTL_MY  0x80
#define ILI9341_MADCTL_MX  0x40
#define ILI9341_MADCTL_MV  0x20
#define ILI9341_MADCTL_ML  0x10
#define ILI9341_MADCTL_RGB 0x00
#define ILI9341_MADCTL_BGR 0x08
#define ILI9341_MADCTL_MH  0x04

/*** Redefine if necessary ***/
#define ILI9341_SPI_PORT hspi1
extern SPI_HandleTypeDef ILI9341_SPI_PORT;

#define ILI9341_RES_Pin       GPIO_PIN_7
#define ILI9341_RES_GPIO_Port GPIOC
#define ILI9341_CS_Pin        GPIO_PIN_6
#define ILI9341_CS_GPIO_Port  GPIOB
#define ILI9341_DC_Pin        GPIO_PIN_9
#define ILI9341_DC_GPIO_Port  GPIOA

// default orientation
#define ILI9341_WIDTH  240
#define ILI9341_HEIGHT 320
#define ILI9341_ROTATION (ILI9341_MADCTL_MX | ILI9341_MADCTL_BGR)

// rotate right
/*
#define ILI9341_WIDTH  320
#define ILI9341_HEIGHT 240
#define ILI9341_ROTATION (ILI9341_MADCTL_MX | ILI9341_MADCTL_MY | ILI9341_MADCTL_MV | ILI9341_MADCTL_BGR)
*/

// rotate left
/*
#define ILI9341_WIDTH  320
#define ILI9341_HEIGHT 240
#define ILI9341_ROTATION (ILI9341_MADCTL_MV | ILI9341_MADCTL_BGR)
*/

// upside down
/*
#define ILI9341_WIDTH  240
#define ILI9341_HEIGHT 320
#define ILI9341_ROTATION (ILI9341_MADCTL_MY | ILI9341_MADCTL_BGR)
*/

/****************************/

// Color definitions
#define	ILI9341_BLACK   0x0000
#define	ILI9341_BLUE    0x001F
#define	ILI9341_RED     0xF800
#define	ILI9341_GREEN   0x07E0
#define ILI9341_CYAN    0x07FF
#define ILI9341_MAGENTA 0xF81F
#define ILI9341_YELLOW  0xFFE0
#define ILI9341_WHITE   0xFFFF
#define ILI9341_COLOR565(r, g, b) (((r & 0xF8) << 8) | ((g & 0xFC) << 3) | ((b & 0xF8) >> 3))

// call before initializing any SPI devices
void ILI9341_Unselect();

void ILI9341_Init(void);
void ILI9341_DrawPixel(uint16_t x, uint16_t y, uint16_t color);
void ILI9341_WriteString(uint16_t x, uint16_t y, const char* str, FontDef font, uint16_t color, uint16_t bgcolor);
void ILI9341_FillRectangle(uint16_t x, uint16_t y, uint16_t w, uint16_t h, uint16_t color);
void ILI9341_FillScreen(uint16_t color);
void ILI9341_DrawImage(uint16_t x, uint16_t y, uint16_t w, uint16_t h, const uint16_t* data);
void ILI9341_InvertColors(bool invert);

#endif // __ILI9341_H__

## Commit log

2025-10-10 Paczka z zespolonymi dzialajacymi dwoma ukladami, matryca led ARGB 8x8 oraz wyswietlacz lcd 2.8' wraz z przygotowanymi funkcjami do wyswietlania ruchu figur szachowych oraz przykladowemu zapisowi otw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
2025-11-04 Schemat ideowy, footprinty, przygotowania do PCB
    [74HC4051D_653.step, EEUFR1C152.step, Matryca_LED.kicad_sch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]
2025-11-07 przygotowanie do tworzenia pcb 4x4 led matrix
    [mux_led_reed.kicad_pcb, mux_led_reed.kicad_sch]
2025-11-10 first version of 4x4 pcb for chessboard
    [mux_led_reed.kicad_pcb, mux_led_reed.kicad_sch]
2025-11-11 plytka 4x4 zawierajaca mux, reed switche i ledy argb v1.0
    [TS02-66-60-BK-100-LCR-D.step, mux_led_reed.kicad_pcb, mux_led_reed.kicad_sch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]
2025-11-13 obie plytki pcb przygotowane, schematy ideowe opisane
    [Matryca_LED.kicad_sch, Mul_Mux_Reed_Switches.kicad_sch, logo_agh-removebg-preview.dxf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]
2025-11-17 pcb v1.0, przygotowane pliki do fabryki pcb, zamowienie zlozone, poprawa przelotek
    [mux_led_reed-B_Cu.gbl, mux_led_reed-B_Mask.gbs, mux_led_reed-B_Paste.gbp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]
2025-11-17 uporzadkowanie folderow, dodanie i wypelnienie BOM, zamowienie elementow
    [mux_led_reed.csv, mux_led_reed.kicad_pcb, mux_led_reed.kicad_sch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]
2025-11-18 pierwsze modele 3D, bez szachownicy sama podstawa na pcb
    [podstawa szachownicy od strony uC.f3d, podstawa szachownicy.f3d, uC podstawa.f3d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]

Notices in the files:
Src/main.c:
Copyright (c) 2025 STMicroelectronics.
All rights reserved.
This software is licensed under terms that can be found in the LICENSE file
